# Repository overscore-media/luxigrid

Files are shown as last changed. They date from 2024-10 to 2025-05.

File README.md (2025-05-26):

# Luxigrid

Luxigrid is a WiFi-enabled LED matrix for your desk, compatible with an ecosystem of 25+ apps and counting.

The hardware and software are open-source, so you can build one yourself. Or buy one pre-assembled or as a kit from [our website](https://luxigrid.overscore.media)!

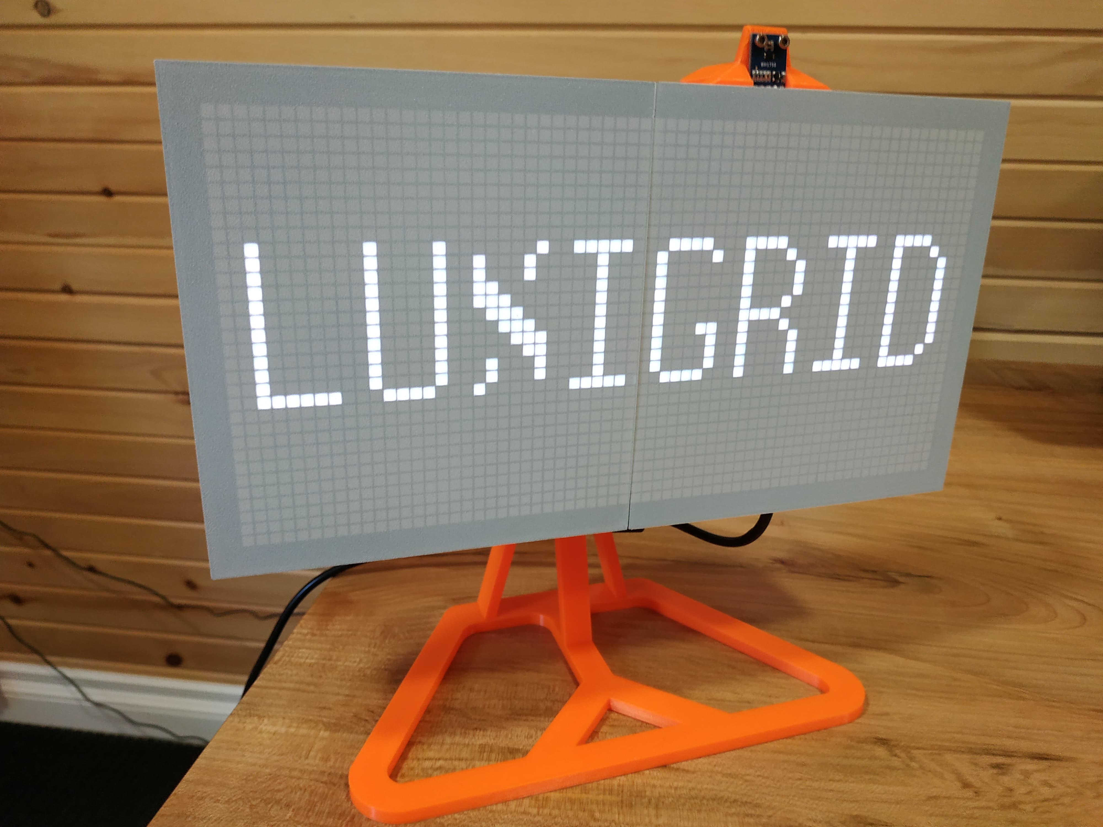
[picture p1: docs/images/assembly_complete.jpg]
An orange and white Luxigrid sitting on a wooden desk, displaying the Luxigrid logo on-screen


## Quick Specs

- 2048 RGB LEDs (in 64x32 grid)
- Browser-Based Web Interface
  - Configure important settings (WiFi, time/date, browse files on SD card, etc.)
  - Upload new apps over WiFi
  - Modify app-specific settings
- Can connect to the Internet (for stocks/weather/news/other info)
- Automatically adjusts its brightness (integrated light sensor)
- Temperature/Humidity Sensor (for an indoor weather station)
- Buzzer for playing alarms, alerts, and chiptunes
- Automatically adjusts for daylight savings time
- Keeps time even when the power goes out (real-time clock on-board)
- Made with readily-available components
- Open-Source
  - Build your own, or modify the code/hardware files to your heart's content
  - Code available under the MIT License
  - 3D printed parts available under the CC-BY-4.0 license
  - PCB Gerbers and KiCad project available and free to use as you see fit

## Quick Start Guide

If you're looking for help setting up your Luxigrid, we've assembled a Quick Start Guide with answers to your most common questions and troubleshooting help.

View the latest version of the [Quick Start Guide](./QUICK_START_GUIDE.md).

For technical support, you can also contact us on [our website](https://luxigrid.overscore.media). Please note that we only provide official support for products purchased from our website. But we'd be happy to chat with you, regardless of whether you've purchased a Luxigrid from our website, or built your own from scratch.

## Technical Details

- 64x32 LED matrix with 4mm pitch
  - Total of 2048 RGB LEDs
  - Compatible with HUB75 protocol
  - Readily available on sites like Aliexpress

- ESP32-DevKitC V4 board
  - ESP32-WROOM-32D processor module
  - WiFi (b/g/n 2.4 GHz) and Bluetooth 4.2
  - 240 MHz Clock Speed
  - 520 KB SRAM (16 KB cache) and 448 KB ROM
  - 1.75 MB of usable flash memory (with OTA updates enabled)
  - Readily available on many sites for under $10
  - Reference: <https://docs.espressif.com/projects/esp-idf/en/stable/esp32/hw-reference/esp32/get-started-devkitc.html>

- Custom PCB
  - Micro SD card reader
  - BME680 Environmental Sensor (temperature, humidity, air pressure)
  - BH1750 Light Sensor (for automatic screen brightness)
  - DS3231 Real-Time Clock (powered by a CR2032 coin cell battery)
  - Piezo Passive Buzzer
  - On/Off Rocker Switch
  - 2.5mm DC Barrel Jack for power

- Power Consumption: 5V DC - 3+ Amps at peak
  - *Please use a power supply capable of delivering at least 4A*

## Assembly Instructions

The process of assembling your own Luxigrid is fairly intensive, but should be documented well enough to be a fair challenge. If you're building one from scratch, you'll need to have purchased the parts from the Bill of Materials, have access to a 3D Printer, and be comfortable with soldering. It's not too difficult, as far as these sorts of electronics projects go, but it may not be for the faint of heart.

[View the full assembly instructions](./ASSEMBLY.md).

Alternatively, you can purchase a Luxigrid in kit form or pre-assembled from [our website](https://luxigrid.overscore.media).

## Development Instructions

The Luxigrid software is split into two semi-distinct components - the C++ firmware that resides on the ESP32, and the HTML/CSS/JavaScript-based web interface that runs on your browser. Since the ESP32 also acts as a web server, there is a level of integration involved. But the most complicated part of the software is its ability to support an arbitrary number of apps. Only one app can be installed on a Luxigrid at a time, and each app must be compiled separately (with its own firmware and web interface). But apps can be swapped between on the fly, thanks to the ESP32's Over-The-Air (OTA) update capability.

Needless to say, the underlying setup to make all of this work is pretty complex. And there are still potential areas for improvement. But we've done what we can to document the process.

[View the full development instructions](./DEVELOPING.md).

Alternatively, you can download the latest compiled versions of the available apps from the official [Luxigrid App Store](https://luxigrid.overscore.media/apps), or the [GitHub Releases page](https://github.com/overscore-media/luxigrid/releases).

## Found an Issue?

Let us know by [creating an Issue](https://github.com/overscore-media/luxigrid/issues) on this GitHub repository. Or if you have a bugfix, feature, or new application you'd like to share, feel free to open a [Pull Request](https://github.com/overscore-media/luxigrid/pulls). We also welcome GitHub stars, forks, and watchers.

For answers to specific questions, or if you just want to chat, drop us a line at [luxigrid.overscore.media](https://luxigrid.overscore.media).

## Credits

OverScore Media wishes to recognize the many giants whose shoulders this project stands upon. Thank you for your contributions to creativity and technology. We hope this project serves as an inspiration to others, like so many have been inspirations to us.

This includes the following individuals and teams. If we've missed any, please let us know. But be assured that their contributions have not gone unappreciated.

Where appropriate, additional copyright notices and software licenses have also been placed in the code. See also [licenses/credits.md](./licenses/credits.md).

### Software Libraries

- [ESP32 HUB75 LED Matrix Panel DMA Display](https://github.com/mrcodetastic/ESP32-HUB75-MatrixPanel-DMA) by @mrcodetastic on GitHub
- [Adafruit GFX Library](https://github.com/adafruit/Adafruit-GFX-Library)
- [Adafruit BusIO](https://github.com/adafruit/Adafruit_BusIO)
- [Adafruit Unified Sensor](https://github.com/adafruit/Adafruit_Sensor)
- [Adafruit BME680 Library](https://github.com/adafruit/Adafruit_BME680)
- [Adafruit RTClib](https://github.com/adafruit/RTClib)
- [BH1750](https://github.com/claws/BH1750) by @claws on GitHub
- [ESP Async WebServer](https://github.com/mathieucarbou/ESPAsyncWebServer) originally by [@me-no-dev](https://github.com/me-no-dev/ESPAsyncWebServer), then forked by [@yubox-node-org](https://github.com/yubox-node-org/ESPAsyncWebServer), then forked by [@mathieucarbou](https://github.com/mathieucarbou)
- [ArduinoJson](https://arduinojson.org/)
- [AnimatedGIF](https://github.com/bitbank2/AnimatedGIF) by @bitbank2
- [FastLED](https://github.com/FastLED/FastLED)

### Projects

The following projects have served as direct inspiration for parts of the Luxigrid firmware.

- [myClock](https://github.com/dragondaud/myClock) by @dragondaud on GitHub
- [Pong Wars for M5Stack](https://github.com/anoken/pong-wars-forM5Stack) by @anoken on GitHub
- [PONG clock](https://github.com/conejoninja/pongclock/) by @conejoninja on GitHub
- [Aurora](https://github.com/pixelmatix/aurora) by Jason Coon
- [minimalUploadAuthESP32](https://github.com/CelliesProjects/minimalUploadAuthESP32/blob/master/minimalUploadAuthESP32.ino) by @CelliesProjects on GitHub

### Development Tools

- [Arduino](https://www.arduino.cc/)
- [ESP32](https://www.espressif.com/en/products/socs/esp32)
- [PlatformIO](https://platformio.org/)
- [Visual Studio Code](https://code.visualstudio.com/)

### Web Development Tools

- [Tailwind.css](https://tailwindcss.com/)
- [Vite](https://vitejs.dev/)
- [JSDOM](https://github.com/jsdom/jsdom)
- [ESLint](https://eslint.org/)
- [ESLint Config XO](https://github.com/xojs/xo)
- [PostCSS](https://postcss.org/)
- [vite-plugin-html](https://github.com/vbenjs/vite-plugin-html)
- [vite-plugin-singlefile](https://github.com/richardtallent/vite-plugin-singlefile)
- [CSSNano](https://github.com/cssnano/cssnano)
- [Iconoir](https://iconoir.com/)

### Data Sources

- [Open-Meteo](https://open-meteo.com/) (for weather data)
- [Finnhub Stock API](https://finnhub.io/) (for stock data)
- [Wikipedia](https://www.wikipedia.org/) (for periodic table of elements data)
- <https://github.com/nayarsystems/posix_tz_db> (for timezone data)

### 3D Software

That's right. Luxigrid's 3D-printed parts were designed with free and open-source software!

- [FreeCAD](https://www.freecad.org/)
- [OpenSCAD](https://openscad.org/)
- [PrusaSlicer](https://www.prusa3d.com/page/prusaslicer_424/)

### 3D Models

This excellent 3D model was used as the basis for the desk mount. Our modified version is a bit taller, and uses an M4 bolt instead of an M5.

- [Vesa 75x75 monitor stand](https://www.thingiverse.com/thing:3808242) by @choosecool on Thingiverse
  - Licensed under the [Creative Commons - Attribution license](https://creativecommons.org/licenses/by/4.0/).

### Tutorials

These helpful tutorial creators have served as invaluable references during various parts of the concept, design, and production phases of this project. Thanks for sharing your knowledge!

- [Random Nerd Tutorials](https://randomnerdtutorials.com/) for a wealth of electronics tutorials
- [@Swiss_Cheese on YouTube](https://www.youtube.com/@Swiss_Cheese.) for PrusaSlicer tips and tricks
- [@ontherundesign's Hirth Joint](https://www.thingiverse.com/thing:2937436) FreeCAD Tutorial
- [RGB Panel Hookup Guide](https://learn.sparkfun.com/tutorials/rgb-panel-hookup-guide) by Sparkfun
- [Adafruit GFX Library Guide](https://cdn-learn.adafruit.com/downloads/pdf/adafruit-gfx-graphics-library.pdf) by Phillip Burgess

### Inspirations

These are some of the hardware projects and commercial products that have served as indirect inspirations for the development of Luxigrid. There were times when it seemed impractical to complete, but the existence of these projects gave us hope that it could be done. Hopefully this project can serve as such an inspiration to others. Your dreams may not be so unachievable, after all! :)

- [Tidbyt](https://tidbyt.com/)
- [Clockwise](https://clockwise.page/)
- [Adafruit Matrix Portal](https://www.adafruit.com/product/4745)
- [Pico RGB Matrix P3 64x32](https://www.waveshare.com/wiki/Pico-RGB-Matrix-P3-64x32) by Waveshare
- [Pixel Art Matrix Display](https://www.printables.com/model/600039-pixel-art-matrix-display) by @Till_312394 on Printables
- [Pixel Art with 64 LED Matrix WS2812B - v2](https://www.printables.com/model/946221-pixel-art-with-64-led-matrix-ws2812b-v2-new-led-di) by @Regis on Printables
- [ESP32 HUB75 LED Matrix Driver](https://github.com/rorosaurus/esp32-hub75-driver) by @rorosaurus on GitHub
- [ESP32 I2S Matrix Shield](https://www.tindie.com/products/brianlough/esp32-i2s-matrix-shield/) by Brian Lough
- [ESP32 D1 Mini D1 RGB Matrix Shield](https://github.com/hallard/WeMos-Matrix-Shield-DMA) by @hallard on GitHub
- [ESP Pixel Matrix](https://github.com/hanneslinder/esp-pixel-matrix) by @hanneslinder on GitHub
- [PxMatrix](https://github.com/2dom/PxMatrix) by @2dom on GitHub
- [HUB75 Pixel Art Display](https://github.com/mzashh/HUB75-Pixel-Art-Display) by @mzashh on GitHub
- [RGB Matrix Panel Shield for ESP32](https://www.tindie.com/products/lightwell/rgb-matrix-panel-shield-for-esp32/) by LIGHTWELL
- [ESP8266 RGB Matrix Cable Version](https://github.com/mike-rankin/ESP8266_RGB_Matrix_Cable_Version) by Mike Rankin

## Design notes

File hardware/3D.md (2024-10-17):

# Luxigrid - 3D Printed Parts List

The Luxigrid enclosure is fully 3D printable (with the exception of some fasteners and heated inserts - see the [Bill of Materials](./BOM.md) for more info).

Here is the list of files you'll need to print to make one of your own!

## List of Files

| Part Name | Optional? | Est. Print Time | Est. Filament Used (g) | Supports Required |
|---|---|---|---|---|
| Backplane Mesh Holder (x4) | * | 40 minutes | 12 | N |
| Desk Mount Bracket | N | 45 minutes | 13 | N |
| Desk Mount | N | 3 hours 30 minutes | 59 | N |
| Left Backplane | N | 4 hours 10 minutes | 82 | Y |
| Left Bracket | N | 1 hour 30 minutes  | 32 | Y |
| Left PCB Bracket | N | 50 minutes | 16 | Y |
| Matrix Diffuser - No Lip | * | 2 hours 20 minutes | 39*** | N |
| Matrix Diffuser - With Lip | * | 2 hours 20 minutes | 39*** | N |
| Right Backplane | N | 4 hours 10 minutes | 87 | Y |
| Right PCB Bracket | N | 40 minutes | 14 | Y |
| SD Card Hat | N | 5 minutes | 2 | N |
| **Totals** | | **21 hours** | **395 g** | |

*The backplane mesh holders are optional. Print them if you want to glue a mesh over the "windows" on the back of the enclosure.

**You need to print two diffusers. But you can choose to print a "No Lip" and a "With Lip" one, or two "No Lip" ones. The difference in material use is negligible, because the "With Lip" just has one extra 0.5mm line on the first layer. See notes below.

***You need at least black and white filament to print the diffusers. A minimum of **6g** of white, and **19g** of black filament is required per diffuser. The other 14g can be white, black, or whatever other colour you want.

## Slicing Tips

The recommended slicer to use with this project is [PrusaSlicer](https://www.prusa3d.com/page/prusaslicer_424/). It is compatible with Prusa printers, and many other models. Other slicers may work, but these files were designed with PrusaSlicer in mind. See the files in the `/hardware/3d/3MF` directory for PrusaSlicer projects.

Not all files are available in 3MF format, because not all of them have special requirements for supports, etc. The diffusers are probably the hardest parts of the enclosure to print, but it is doable.

If you plan to use a different slicer, you will need to ensure that supports are generated for the models requiring supports in the above. Just try not to go overboard with supports. Even if you're using a different slicer, it's recommended to open the 3MF's in PrusaSlicer first, to get a feel for which features need supports and which don't.

For the matrix diffusers, you will need one layer of white, followed by 10 layers of black, followed by any colour of your choice. This is assuming a **0.4mm nozzle** and **0.20mm** layer height, which is recommended for all parts.

The diffusers should *not have a brim on the edge where they connect*. This is to make it easier for them to fit together with as small a gap as possible. You may still need a brim on the other sides - see the 3MF files for an example.

In addition to the 3MF files for the trickier parts, we have also provided STL files for all parts, and STEP files for all but the matrix diffusers. Since they were designed in [OpenSCAD](https://openscad.org/), you also have access to the original .scad source file used to generate the matrix diffusers.

## Printing Tips

If you're using PrusaSlicer, especially with non-Prusa filament, you'll likely want to decrease the nozzle temperature considerably, to mitigate stringing. Especially for the black "grid" part of the matrix diffusers. We've had success at 190-195C for the black grid. But it depends on the specific filament you're using. Don't print too cold, or you may have other issues. But the default ~220C is generally too hot for printing the matrix diffuser grid. The other parts don't matter as much if they're stringy or not, but it really matters for the diffusers.

The diffusers must be printed with the same material throughout. So if you start with white PETG, you also need black (and whatever other optional colour) PETG to finish the diffuser. Same if you started with white PLA. Obviously you can print the rest of the enclosure with a different filament, but the colour difference may be noticeable, if you're using different types of filament for different parts of the enclosure.

We've had good results with either PLA or PETG, but other materials may work as well.

## Post-Processing Tips

If there are strings or small globs on your parts, very carefully removing them with a heat gun may be effective. This isn't really an option for the matrix diffusers or the vents/windows on the back of the enclosure, due to the thin plastic there being susceptible to warping if heat is applied.

Having some sandpaper and something like a "Metal Spudger" on hand may be useful for removing parts of brims, or other print artifacts. See the [BOM](./BOM.md) for more information on recommended tools.

For attaching the optional backplane mesh holders, hot glue is recommended. We recommend gluing the mesh to the holders first, then gluing the hole thing onto the backplane. Use the guide posts printed onto the inside of the backplanes to help align them. You may choose to install the mesh face-up or face-down. It can work either way. Although face-up is probably easier. See the [Assembly Instructions](../ASSEMBLY.md) for more information.

## Heated Insert Tips

The matrix diffusers and the right backplane both require metal heat-insert threads. You may choose to modify the source files to remove this requirement, but we highly recommend giving them a try.

These specific places, especially if you ever plan to take your Luxigrid apart, greatly benefit from not just having to screw into plastic. We experimented with placing them elsewhere, as there are still some places you'll have to screw into plastic. For instance, the PCB brackets have some plastic holes you'll have to screw into. But we couldn't get a reliable result that didn't involve the inserts falling out or detaching themselves from the plastic parts.

See the [BOM](./BOM.md) for details on the specific parts you'll need. There are many good tutorials out there for working with heated inserts. A special insert tip for a temperature-controlled soldering iron is recommended. We've tested several temperatures, and 490F or somewhere thereabouts seems ideal. You may want to have some practice before you attempt this. It's not too bad once you get the hang of it. But always be careful around soldering irons and high heat. And give the parts sufficient time to cool before continuing with the rest of the assembly.

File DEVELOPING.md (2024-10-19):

# Luxigrid - Development Documentation

## Project Setup

This repository contains two semi-distinct sub-projects - the C++ firmware for the ESP32, and the browser-based web interface code.

Briefly, the web interface lives in the `/ui` folder, and the C++ project is spread across the `/apps`, `/lib`, and `/src` directories.

The firmware is compiled using the PlatformIO toolchain. The `platformio.ini` file contains the build configuration, including the list of external C++ dependencies.

The `/scripts` directory contains a few Python and shell scripts that help with automating builds of the software.

Working with this code requires a decent amount of experience with C++ and JavaScript. Experience with embedded development is also a plus. It's not the fanciest or best code by any means, but it's more than serviceable.

## Initial Setup

You will need Node.js (at least version 18.20.2) and npm installed on your system. See <https://nodejs.org/en/download> for instructions.

You will also need PlatformIO to be installed on your system, ideally through its VS Code extension, and a compatible version of Python 3. Not as tricky as it might seem - see <https://randomnerdtutorials.com/vs-code-platformio-ide-esp32-esp8266-arduino/> or <https://docs.platformio.org/en/latest/integration/ide/vscode.html> for help.

You might also want to install `curl` if you don't already have it on your system (if you want to use the OTA Upload capability from PlatformIO).

First things first, clone or download this Git repository. Once you have it somewhere on your system, run `npm install` in the `/ui` directory.

Then, you should copy the `.env.example` file and rename the copy to `.env`. Do the same for the `/ui/.env.example` file.

Finally, from the PlatformIO sidebar in VS Code, you should be able to see the `Build` button under the `esp32dev` device folder.

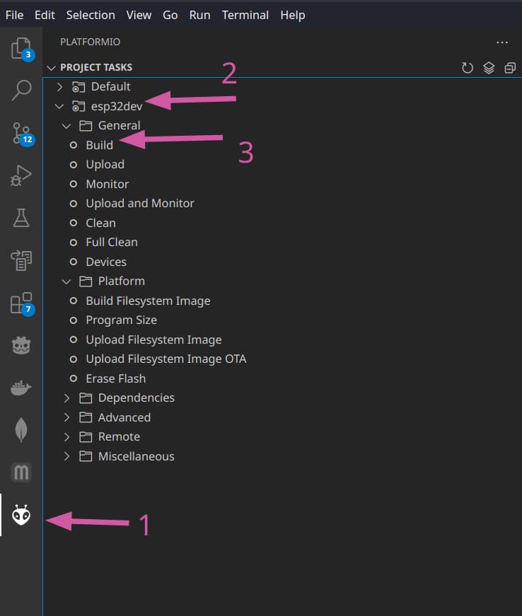
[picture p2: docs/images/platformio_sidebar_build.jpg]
From the PlatformIO sidebar, click "Build" under "esp32dev"


A terminal window should open in VS Code, and the result should look something like this.

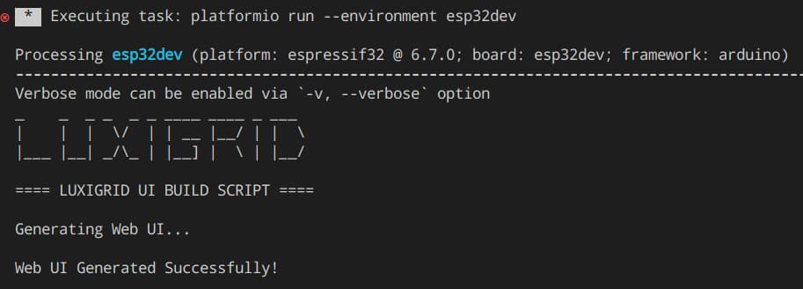
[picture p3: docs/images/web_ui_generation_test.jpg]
A terminal displays Web UI Generated Successfully!


You will probably have some errors below this, but as long as it says "Web UI Generated Successfully!" you should be good to move on.

## Setting the Current App

Each time you build the Luxigrid firmware, you need to specify which app you have selected. The reasoning for this is quite simple. With the ESP32's limited resources (especially flash memory) it is not possible to have all of these apps installed at the same time. Further, many of the apps have mutually-exclusive functionality that would conflict.

In order to set the current app, you must uncomment one of the app names in `lib/apps.h`. To enable the Pong Clock, for instance, you would uncomment `#define PONG_CLOCK` like so:

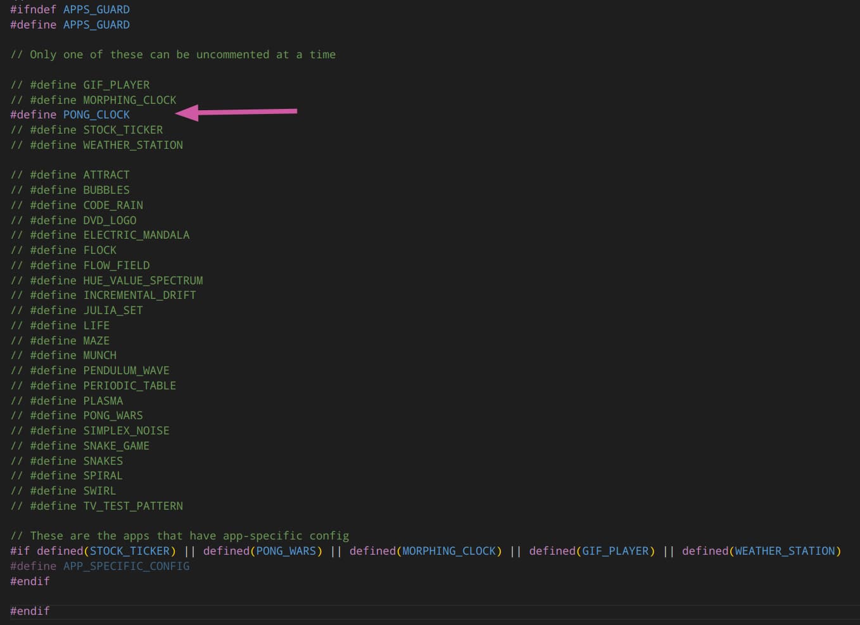
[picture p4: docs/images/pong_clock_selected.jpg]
The line with PONG_CLOCK is uncommented, while the other app names are still commented out


Unfortunately there's also a bit of frontend configuration to be done.

In the `/ui/.env` file, you'll need to at set at least the `VITE_APP_NAME`. In this case, `VITE_APP_NAME=Pong Clock` would be appropriate. For apps with app-specific config (see the list in `/lib/apps.h`) you'll also need to provide a `VITE_CURRENT_APP`. But for now you can leave it commented out. The other environment variables aren't that big of a deal right now. You could leave them as-is or comment them out.

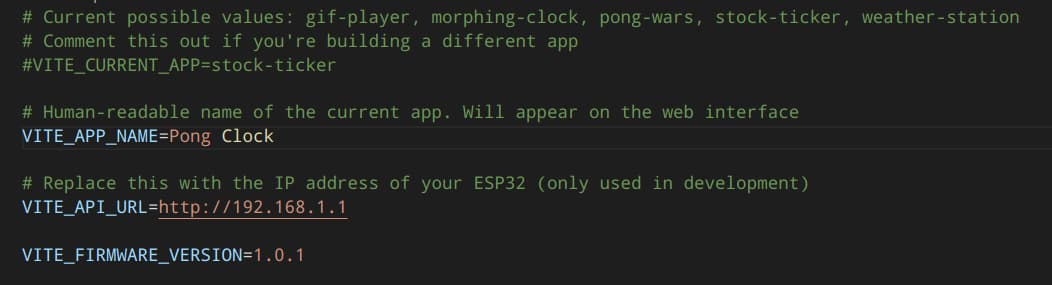
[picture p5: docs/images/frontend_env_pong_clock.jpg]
/ui/.env file with VITE_APP_NAME=Pong Clock and VITE_CURRENT_APP commented out


Then that should be all you need. Try building the app from the PlatformIO sidebar "Build" button. You should get something that looks a bit like this. Note the "Web UI Generated Successfully!" at the top, and the "Successfully created esp32 image." at the bottom. If you see any yellow or red text, something may have gone wrong.

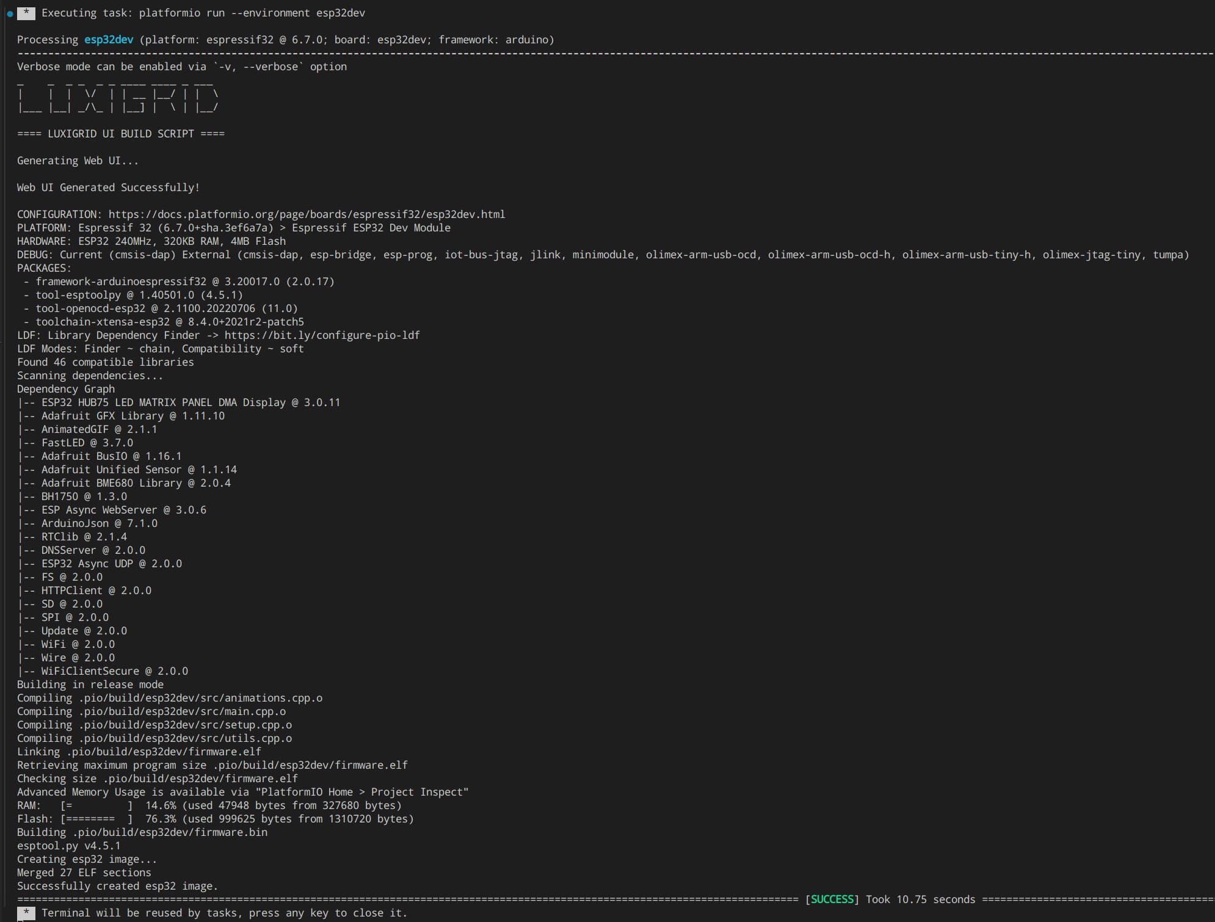
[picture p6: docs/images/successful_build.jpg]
A successful build of the Luxigrid firmware, that says "Successfully created esp32 image." at the bottom


So why are they all in the same project? Good question. While there are some obvious benefits to a more encapsulated approach, where each app has its own project, that would lead to a lot of unnecessary code duplication and even more complexity. It's just not worth it, when all of the apps share a significant portion of the codebase. Separating the shared code into a separate library might have made sense, but the existence of the web interface throws a bit of a wrench into that plan.

Ultimately, there may be better ways of structuring a project like this, but this works pretty well, given the constraints. Is it perfect? Does it eliminate code duplication? Does it make it the easiest to create new apps? No, not really. But it works.

## Deploying to the ESP32

### OTA Upload via PlatformIO

Once you've successfully built the Luxigrid firmware, you have a few options for deploying it to the ESP32. One option, provided by this project, is to use the "Upload" button on the PlatformIO sidebar (just under "Build").

If your ESP32 is already running, and already has an IP address on your WiFi network, you can set it as your `ESP32_IP` in the `.env` file. Then as long as it's accessible, and you have `curl` installed on your system, it should automatically upload the new firmware image to the ESP32, replacing the existing firmware. Once the ESP32 reboots, it should be running the new firmware (unless something went wrong, which the terminal might give you some insight on).

### Upload via the Luxigrid Web Interface

Alternatively, the `/.pio/build/esp32dev/firmware.bin` file is what you're looking for. If you have a Luxigrid that's currently running, you can upload that firmware image via the Luxigrid web interface from your browser. Same deal, it should reboot after uploading and installing the new firmware.

### Upload via USB

Otherwise, you'll have to find a way to upload onto the ESP32 via USB. You can comment out the `upload_protocol`, `upload_command`, and `pre:scripts/upload_firmware.py` lines in `platformio.ini`. Something like this (comment lines out by putting a `;` in front of them.)

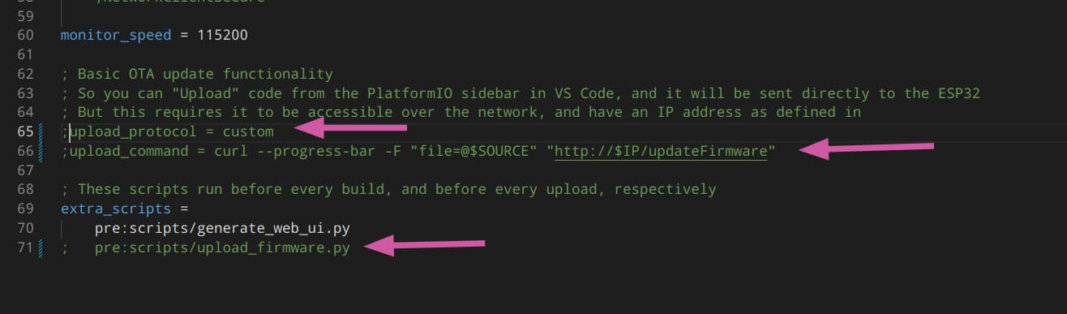
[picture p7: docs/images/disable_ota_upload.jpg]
Three lines near the end of the platformio.ini file are commented out with semicolons


Then plug your ESP32 into your computer via its Micro USB port.

It's not recommended to have the ESP32 plugged into the Luxigrid circuit board while uploading firmware. It might work, but it's at your own risk. Ideally you should have just the ESP32 board itself plugged in via USB.

You may need to mess with drivers or various things to get the ESP32 code upload to work over USB. Luckily, PlatformIO is pretty good at finding it, and it's pretty configurable if you're having issues. This tutorial from Random Nerd Tutorials should be very helpful if you're running into issues <https://randomnerdtutorials.com/vs-code-platformio-ide-esp32-esp8266-arduino/>.

You'll know when it works, when you can plug the ESP32 into the Luxigrid circuit board (provided it's properly installed in the LED matrix), provide power to the circuit board, and watch the Luxigrid logo pop up.

## Creating a New App

### Basic Requirements

The process of creating a new app is quite involved. Especially if it will have app-specific config. Hopefully the available apps can serve as decent examples should you choose to embark on this journey.

The first thing to note, is you should have a main source file for your app, in the `/apps` (or `/apps/animations`) folder. You'll need to think up a unique name for it, that doesn't conflict with existing app names. Your main source file should have an `.hpp` extension.

You should put a define guide at the top, something like:

```cpp
#ifndef STOCK_TICKER_GUARD
#define STOCK_TICKER_GUARD
```

But make it unique, like `MY_APP_NAME_GUARD`. Also don't forget to put a `#endif` at the end of the file. You will also need to import the Arduino and Luxigrid headers, at the very least.

```cpp
#include "Arduino.h"
#include "../lib/luxigrid.h"
```

You can import other dependencies at the top of your source file. They can be local files, or external dependencies installed by PlatformIO. It's up to you.

All apps need at least a `setup()` and a `loop()` function.

```cpp
void setup() {
    setupMatrix();
}

void loop() {

}
```

The `setup()` function should call `setupMatrix()` at the top, or you won't have access to the rest of the shared features of the Luxigrid firmware.

### App-Specific Config (Optional)

Apps that have app-specific config also need at least the following functions:

```cpp
void retrieveAppConfig() {}
void validateAppConfig() {}
void saveAppConfig() {}
```

There are several examples of apps with app-specific config, some more complicated than others. The config in `/apps/animations/pong-wars.hpp` is two colours, whereas the config in `/apps/stock-ticker.hpp` is much more involved.

Without going into too much detail, or we'd be here all day, each app with app-specific config needs to provide the means to load the config (from a JSON file on the SD card), a function to provide the config to the web interface, a function to provide a function to validate user-provided config from the web interface, and a function to save the config to the SD card.

The ArduinoJson library makes it convenient to store configuration as a JSON file. And various custom `struct`'s can be used to define the types of configuration that will be used in the app.

The app-specific config must be loaded in the `setup()` function, after which the global variable `configIsLoaded` should be set to true. Otherwise, it's up to you what happens in-between. See `/lib/web_server.hpp` for an idea of what the rest of the codebase expects.

### Other Required Setup

You'll also need to update `/lib/apps.h` and add your new app to the list. Add a new line under the APPS_GUARD that looks something like: `#define MY_NEW_APP`. For apps with app-specific-config, you'll need to add your app to the list of apps that have it. The goal is so `APP_SPECIFIC_CONFIG` will be defined only if it needs to be.

You'll also need to modify `/src/main.cpp` so your app's main source file is imported. That might look something like this, but your mileage may vary:

```cpp
#ifdef MY_APP
#include "../apps/my-app.hpp"
#endif
```

Finally, you might want to update `/scripts/build_all_apps.py` to include your new app. That is, if you want it to be built along with the other apps when bulk-compiling them.

### Required Web Interface Setup

Unfortunately this is only half the story (if app-specific config is involved). You'll still need to create a custom section on the web interface to enable users to interact with the app-specific config.

Without app-specific config, you can just set `VITE_APP_NAME` in `/ui/.env` to whatever you want to call your app. And keep `VITE_CURRENT_APP` commented out. You could then set a custom `VITE_FIRMWARE_VERSION`, it's up to you.

### Additional Web Interface Setup (App-Specific Config only)

If your app has its own config, you'll need to provide some frontend code to go along with it. This starts by creating a folder in the `/ui/apps` directory, with the name of your app. If you app is called "My App", for instance, `/ui/apps/my-app` would be a good choice. You will need to provide the name of this folder (in this case `my-app`) as the `VITE_CURRENT_APP` in the `/ui/.env` file.

Inside this folder, you'll need at least a JavaScript file, named something like `/ui/apps/my-app/my-app.js` (same filename as `VITE_CURRENT_APP` but with a `.js` extension).

This JS file must export a function by default. It can be called whatever you want.

This function must setup the app's icon (Finding icons from <https://iconoir.com/> and running them through <https://jakearchibald.github.io/svgomg/> works well), the app's name, the name of the button on the web interface, what settings inputs are available, and how they're interacted with.

In lieu of a step-by-step guide, see `/ui/apps/pong-wars/pong-wars.js` for a fairly minimal example. You can choose to construct the interface using just JavaScript, or you can provide a `.hbs` file and import it into your `.js` file. It must be `.hbs`, even if it's not actually Handlebars, because a custom optimizer (configured in `/ui/vite.config.js`) runs on `.hbs` files.

Like with the C++ side of app-specific config, other than that, it's up to you how you choose to implement the various parts of the web interface. Ideally, you should be able to work with what you have, and not have to pull in external JavaScript dependencies. Because in an embedded environment, they can really add up.

## Tips, Tricks, and Caveats

Admittedly, the process of creating a new app could be easier or better documented. But for the time being, at least unless there is enough interest in streamlining this process, development will be focused on fixing bugs, adding little features here and there, and adding new apps from time to time.

It would be nice to have the ability to create builds of the firmware with features like the Light Sensor, BME680 environmental sensor, RTC, etc. disabled in the code - for people who built a Luxigrid without one or more of them. Currently that's not officially supported (although the light sensor can be disabled from the web interface) but it would be nice.

Double buffering is supported by the ESP32-HUB75-MatrixPanel-DMA library, but the shared codebase isn't drop-in compatible with it. Although for most apps, it shouldn't be necessary in the first place.

If you're experiencing flickering with a custom app, avoid `dma_display->clearScreen()` wherever possible. For one reason or another, flickering seems far less noticeable if you're just updating one part of the screen at a time. Like drawing a black rectangle before updating the text above it.

Technically more fonts are supported, although only two are currently used in the app (`Org_01` is a blocky font, `TomThumb` is a tiny font). But the Adafruit GFX library is compatible with (and includes) many fonts. Worth looking into, if you're interested in a different look.

There are some pretty advanced latent capabilities of this system. An alarm clock comes to mind, or perhaps a Spotify "Now Playing" display. Rest assurred, we at OverScore Media have some ideas in the works. But if you have any ideas of you own, you might be surprised what's possible.

The hardest part about building internet-connected apps is finding a reliable data source. Finnhub and Open-Meteo are great; really appreciate that they're free for personal use. But a lot of interesting project ideas are hampered by bad, non-existent, obsolete, or expensive APIs.

There might be a way to run clock faces from the Clockwise project on a Luxigrid. There may also be potential HomeAssistant or ESPHome integrations.

It'd be interesting to apply this approach to larger or smaller LED matrixes. The Luxigrid PCB technically has "HUB75 (E)" compatibility, for larger matrixes like 64x64. Although the firmware currently expects a 64x32 matrix in most places. There are also matrixes with larger or smaller LEDs. Going any larger than 4mm would push the PCB to (and perhaps beyond) its limits, since it would require more power to operate. Especially the barrel jack, which is rated at 5A. Although a smaller 3mm matrix version should be doable. The hardware would probably work just fine, it would just require new 3D files. Anyway. Maybe one of these days...

But from a software point of view, you'd probably be surprised just how many similar code projects are out there. Search "HUB75" followed by whatever search term. Some work with a Raspberry Pi, and may require resources that the ESP32 can't provide. Many may be compatible with some tweaks, though. And even if they're written in a different programming language, or even if they use an LCD/OLED instead of a HUB75 LED matrix, you'd probably be surprised how straightforward they may be to port to this framework.

Case in point, the Pong Clock app is pretty much a port of <https://github.com/conejoninja/pongclock/>, although the original was written in Go. And Pong Wars was adapted from <https://github.com/anoken/pong-wars-forM5Stack>. The original was written for a modified ESP32 connected to a square LCD display.

Bottom line, as early and complex as it may be - the Luxigrid firmware has been designed with modularity in mind from the start. It abstracts away as much of the repetitive stuff as reasonable, letting you interact with the display and perhipherals in a pretty fluent way. The powerful [ESP32-HUB75-MatrixPanel-DMA](https://github.com/mrcodetastic/ESP32-HUB75-MatrixPanel-DMA) library by @mrcodetastic does a lot of the heavy lifting on the LED side of things, and libraries like [ArduinoJson](https://github.com/bblanchon/ArduinoJson) and [ESPAsyncWebServer](https://github.com/mathieucarbou/ESPAsyncWebServer) make custom web-based configuration fairly straightforward to setup.

## Folder Structure

Here's the complete folder structure of this project, including some descriptions of relevant files. Most source code files also have some kind of comment(s) inside the files themselves, explaining their purpose, etc.

- `/.pio` (auto-generated by PlatformIO; do not source-control)

- `/.vscode` (contains some optional settings to make code editing easier with Visual Studio Code)

- `/apps` (the individual applications live here)
  - `/apps/animations` (for apps that don't rely on external resources or time-keeping)

- `/docs`
  - `/docs/images` (where images are stored for this documentation)

- `/hardware`
  - `/hardware/3d/` (3D Printing files)
    - `/hardware/3d/3MF` (3MF files generated from Prusa Slicer. Use as a reference for the trickier-to-print parts.)
    - `/hardware/3d/SCAD` (OpenSCAD source files. Currently just for the matrix diffusers)
    - `/hardware/3d/STEP` (STEP 3D files. Useful for importing into a 3D slicer or CAD program)
    - `/hardware/3d/STL` (STL files. Useful for importing into some 3D slicers. STEPs are recommended whenever your slicer supports them, but the matrix diffuser is only available in SCAD and STL)
  - `/hardware/pcb`
    - `/hardware/pcb/kicad` (the KiCad project used to create the PCB)
    - `/hardware/pcb/gerbers` (pre-generated Gerber files for PCB manufacturing)
  - `/hardware/3D.md` (3D printing instructions)
  - `/hardware/BOM.md` (Bill of Materials)
  - `/hardware/luxigrid_shopping_list.xlsx` (Spreadsheet for helping with buying parts for building a Luxigrid from scratch)

- `/lib` (various helper/library files, for apps or Luxigrid itself) - all apps use at least these files:
  - `/lib/apps.h`
    - Where the list of apps is defined, and the current app is selected
    - Uncomment out one of the apps at a time, so the compiler will know which one to build
    - Also defines whether the current app has app-specific config (from the web interface)
  - `/lib/luxigrid.h`
    - The main project header. Imports dependencies used in every app, and declares global variables/structs and shared functions
  - `/lib/web_server.hpp`
    - Where the web server code lives. With the exception of app-specific config handlers (defined in app code where applicable)
    - Includes routes for SD card file management, WiFi configuration, time and other global configuration, OTA firmware updates, and a health check route to see if the device is online and fully loaded
  - `/lib/web_ui.h`
    - Auto-generated by `scripts/generate_web_ui.py`; do not source-control
    - Contains a binary array of gzipped data, representing the web interface
    - Is used by the web server to display the web interface
    - When compiling with PlatformIO, the web interface is automatically rebuilt prior to each code compliation

- `/licenses` (licenses and credits for third-party code/libraries used in this project)

- `/scripts` (automation helpers)
  - `/scripts/build_all_apps.py` (used to compile all apps automatically, and generate a .ZIP of them)
  - `/scripts/build_ui.sh` (bash script used in conjunction with `generate_web_ui.py`)
  - `/scripts/generate_elements.py` (used to generate the list of elements for the periodic table app - kept here for future reference)
  - `/scripts/generate_web_ui.py` (ensures the web interface code is up to date before the rest of the C++ code is compiled)
  - `/scripts/upload_firmware.py` (enables automatic OTA firmware uploads from PlatformIO)

- `/src` (main C++ source directory)
  - `/src/animations.cpp` (some animations and user interface elements, like the startup logo and WiFi information splash page)
  - `/src/main.cpp` (basically just `#include`'s for the available apps, based on the current app as set in `/lib/apps.h`)
  - `/src/setup.cpp` (initial setup functions, for the LED matrix, WiFi, time and date, the onboard sensors, and the SD card)
  - `/src/utils.cpp` (various shared utilty functions)

- `/ui` (where the web interface code lives)
  - `/ui/apps` (contains subfolders for the apps with app-specific config)
    - Must have a `.js` file, but may also have other files (like `.hbs` or `.css`)
    - Each app with config must have a folder with its name, and a matching `.js` file inside
    - So `gif-player` has `/ui/apps/gif-player` which houses `gif-player.js`
    - And `pong-wars` has `/ui/apps/ponig-wars` which houses `pong-wars.js`
  - `/ui/dist` (automatically-generated build files; do not source-control)
  - `/ui/lib` (various shared JavaScript utility functions)
  - `/ui/node_modules` (Node.js dependencies; do not source-control)
  - `/ui/templates` (some reusable HTML templates)
    - They're `.hbs` extension, and they have `{{}}` interpolation going on, but it's not actually Handlebars
    - It's just easier to think of them as Handlebars files
  - `/ui/.env.example` (copy and rename this to `/ui/.env`)
    - Set `VITE_CURRENT_APP` for apps with app-specific config (like `stock-ticker`, `gif-player`, etc.) or uncomment for apps without app-specific config
    - Set `VITE_APP_NAME` to a human-readable name of the current app (like `Stock Ticker` or `GIF Player`)
    - Set `VITE_API_URL` to the accessible URL of your ESP32 (during development only)
    - Set `VITE_FIRMWARE_VERSION` to whatever version string you want to display on the web interface (optional)
  - `/ui/.eslintrc.cjs` (ESLint configuration for linting/analyzing JavaScript code)
  - `/ui/.gitignore` (List of files that won't be source-controlled in the `/ui` directory by default)
  - `/ui/.prettierrc` (Prettier configuration for linting HTML)
  - `/ui/generateWebUI.js` (Script that generates `/lib/web_ui.h`)
  - `/ui/index.html` (Main HTML file for the web interface)
  - `/ui/main.js` (Main JavaScript file for the web interface)
  - `/ui/package-lock.json` (Node.js dependencies list - do not edit)
  - `/ui/package.json` (High-level, Node.js dependencies list, for use with `npm`)
  - `/ui/postcss.config.js` (PostCSS configuration)
  - `/ui/style.css` (Global CSS file for the web interface)
  - `/ui/tailwind.config.js` (Configuration for Tailwind.css)
  - `/ui/timezones.json` (JSON data of timezones - adapted from <https://github.com/nayarsystems/posix_tz_db>)
  - `/ui/vite.config.js` (Custom Vite configuration)

- `.clang-format` (settings for auto-formatting C++ code, to keep it stylistically consistent)

- `.env.example` (copy and rename this to `.env`)
  - You can set `ESP32_IP` if you want to OTA upload to the ESP32 directly from PlatformIO

- `.gitignore` (list of files that won't be source-controlled by default)

- `ASSEMBLY.md` (Assembly Instructions)

- `DEVELOPING.md` (this file - Development Instructions)

- `LICENSE.txt` (the main license of this repository)

- `platformio.ini` (contains the build configuration and C++ dependencies)

- `QUICK_START_GUIDE.md` (Quick Start Guide)

- `README.md` (take a guess 😉)

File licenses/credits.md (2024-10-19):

# Credits

- License Files:
  - **MIT License** (licenses/MIT_LICENSE.txt)
  - **Apache 2.0 License** (licenses/APACHE_LICENSE.txt)
  - **GNU Lesser General Puglic License v3.0** (licenses/LGPL3_LICENSE.txt)
  - **BSD License** (licenses/BSD_LICENSE.txt)
  - **CC-BY 4.0 License** (licenses/CC_BY_LICENSE.txt)
  - **CC0 1.0 License** (licenses/CC0_LICENSE.txt)

## Credits for Luxigrid Software

---

- Adafruit BME680 Library
  - <https://github.com/adafruit/Adafruit_BME680>
  - <https://adafruit.github.io/Adafruit_BME680/html/index.html>
  - Written by Limor Fried/Ladyada for Adafruit Industries
  - BSD License

---

- Adafruit Bus IO Library
  - <https://github.com/adafruit/Adafruit_BusIO>
  - Copyright (c) 2017 Adafruit Industries
  - MIT License

---

- Adafruit GFX Library
  - <https://github.com/adafruit/Adafruit-GFX-Library>
  - Copyright (c) 2012 Adafruit Industries.  All rights reserved.
  - BSD License

---

- Adafruit RTClib
  - <https://github.com/adafruit/RTClib>
  - "a fork of JeeLab's fantastic real time clock library for Arduino"
  - Copyright (c) 2019 Adafruit Industries
  - MIT License

---

- Adafruit Unifed Sensor Driver
  - <https://github.com/adafruit/Adafruit_Sensor>
  - Apache 2.0 License

---

- AnimatedGIF
  - <https://github.com/bitbank2/AnimatedGIF>
  - Copyright (c) 2020-2024 BitBank Software, Inc.
  - Written by Larry Bank (<larry@bitbanksoftware.com>)
  - Apache 2.0 License

---

- ArduinoJson
  - <https://arduinojson.org/>
  - <https://github.com/bblanchon/ArduinoJson>
  - Copyright © 2014-2024, Benoit BLANCHON
  - MIT License

---

- BH1750
  - <https://github.com/claws/BH1750>
  - Copyright (c) 2018 claws
  - MIT License

---

- cssnano
  - <https://github.com/cssnano/cssnano>
  - <https://cssnano.github.io/cssnano/>
  - Copyright (c) Ben Briggs <beneb.info@gmail.com> (<http://beneb.info>)
  - MIT License

---

- ESLint
  - <https://github.com/eslint/eslint>
  - <https://eslint.org/>
  - Copyright OpenJS Foundation and other contributors, <www.openjsf.org>
  - MIT License

---

- ESLint Config XO
  - <https://github.com/xojs/xo>
  - Copyright (c) Sindre Sorhus <sindresorhus@gmail.com> (<https://sindresorhus.com>)
  - MIT License

---

- ESP32-HUB75-MatrixPanel-DMA
  - <https://github.com/mrcodetastic/ESP32-HUB75-MatrixPanel-DMA>
  - Copyright (c) 2018-2032 Faptastic
  - MIT License

---

- ESPAsyncWebServer
  - <https://github.com/mathieucarbou/ESPAsyncWebServer>
  - Originally by [@me-no-dev](https://github.com/me-no-dev/ESPAsyncWebServer)
  - Then forked by [@yubox-node-org](https://github.com/yubox-node-org/ESPAsyncWebServer)
  - Then forked by [@mathieucarbou](https://github.com/mathieucarbou)
  - LGPL-3.0 License

---

- Espressif 32 for PlatformIO
  - <https://github.com/platformio/platform-espressif32>
  - Apache 2.0 License

---

- FastLED
  - <https://github.com/FastLED/FastLED>
  - <https://fastled.io/>
  - Originally created by Daniel Garcia in 2010 ([@focalintent](https://github.com/focalintent) on GitHub) - RIP
  - Mark Kriegsman ([@kriegsman](https://github.com/kriegsman)) on GitHub) - joined the project in 2013
  - Copyright (c) 2013 FastLED
  - MIT License

---

- Iconoir
  - <https://iconoir.com/>
  - <https://github.com/iconoir-icons/iconoir>
  - Copyright (c) 2021 Luca Burgio
  - MIT License

---

- JSDOM
  - <https://github.com/jsdom/jsdom>
  - Copyright (c) 2010 Elijah Insua
  - MIT License

---

- minimalUploadAuthESP32
  - <https://github.com/CelliesProjects/minimalUploadAuthESP32>
  - Copyright (c) 2022 Cellie
  - MIT License

---

- posix_tz_db
  - <https://github.com/nayarsystems/posix_tz_db>
  - Copyright (c) Nayar Systems
  - MIT License

---

- PostCSS
  - <https://github.com/postcss/postcss>
  - <https://postcss.org/>
  - Copyright 2013 Andrey Sitnik <andrey@sitnik.ru>
  - MIT License

---

- Tailwind CSS
  - <https://github.com/tailwindlabs/tailwindcss>
  - <https://tailwindcss.com/>
  - Copyright (c) Tailwind Labs, Inc.
  - MIT License

---

- Vite
  - <https://github.com/vitejs/vite>
  - <https://vitejs.dev/>
  - Copyright (c) 2019-present, Yuxi (Evan) You and Vite contributors
  - MIT License

---

- vite-plugin-html
  - <https://github.com/vbenjs/vite-plugin-html>
  - Copyright (c) 2020-present, Vben
  - MIT License

---

- vite-plugin-singlefile
  - <https://github.com/richardtallent/vite-plugin-singlefile>
  - Copyright (c) 2021-present, Richard S. Tallent, II
  - MIT License

---

## Image Credits for [luxigrid.overscore.media](https://luxigrid.overscore.media)

- 32x32 Pixel Art Creatures
  - <https://opengameart.org/content/assorted-32x32-creatures>
  - <https://opengameart.org/content/more-assorted-32x32-creatures>
  - <https://opengameart.org/content/32x32-pixel-art-creatures-volume-3>
  - Posted by AndHeGames on OpenGameArt
  - CC0 License

- 32x32 Portraits
  - <https://opengameart.org/content/32-x-32-portraits>
  - Posted by Seafood5040 on OpenGameArt
  - CC0 License

- CC0 Food Icons
  - <https://opengameart.org/content/cc0-food-icons>
  - Posted by AntumDesign on OpenGameArt
  - CC0 License

- CC0 Tool Icons
  - <https://opengameart.org/content/cc0-tool-icons>
  - Posted by AntumDeluge on OpenGameArt
  - CC0 License

- Hand Cursor
  - <https://opengameart.org/content/hand-cursor>
  - Posted by andreyin on OpenGameArt
  - CC0 License

- Hearts [32x32] & [16x16]
  - <https://opengameart.org/content/hearts-32x32-16x16>
  - Posted by Leozlk on OpenGameArt
  - CC0 License

- GitHub Icon
  - <https://iconduck.com/icons/313558/github>
  - Jérémie Pichon
  - MIT License

- Winter Birds
  - <https://opengameart.org/content/winter-birds>
  - Posted by Refuzzle on OpenGameArt
  - CC0 License

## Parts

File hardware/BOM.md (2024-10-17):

# Luxigrid - Bill of Materials

This is the list of the parts/tools you may need to assemble a Luxigrid of your own. Fair warning, it's a fairly long list. But we've gone to considerable lengths to ensure the availability/reasonable price of these components. Hopefully they're still relatively easy to find, if and when you choose to embark on this adventure.

You can also purchase a Luxigrid in kit form or pre-assembled from [our website](https://luxigrid.overscore.media) 😉.

**Please Note:** OverScore Media does not guarantee that any of this information is accurate or up-to-date. It is provided for informational purposes only, in the hope that it will be useful. Any images are for illustration only. If you choose to follow these instructions, you do so at your own risk. This is just to let you know what you might be in for. Please be careful.

We've also provided a handy [Shopping List](./luxigrid_shopping_list.xlsx) spreadsheet that you may find helpful.

## Modules

- **LED Matrix**
  - P4 64x32 LED Matrix
  - 256x128mm
  - HUB75
  - Your mileage may vary, but Muen LED/MuenShop on Aliexpress has good deals
  - *Must be compatible with the ESP32 HUB75 MatrixPanel DMA Library* - see <https://github.com/mrcodetastic/ESP32-HUB75-MatrixPanel-DMA?tab=readme-ov-file#supported-panels>

- **ESP32-DevKitC V4 Board**
  - You're looking for a **38-pin** ESP32 board that has an **ESP32-WROOM-32D** chip and **Micro USB**
  - Look for the one that matches this picture *exactly*, since the Luxigrid PCB is built around it
  - They shouldn't be too hard to find, if you know what you're looking for - i.e., this:

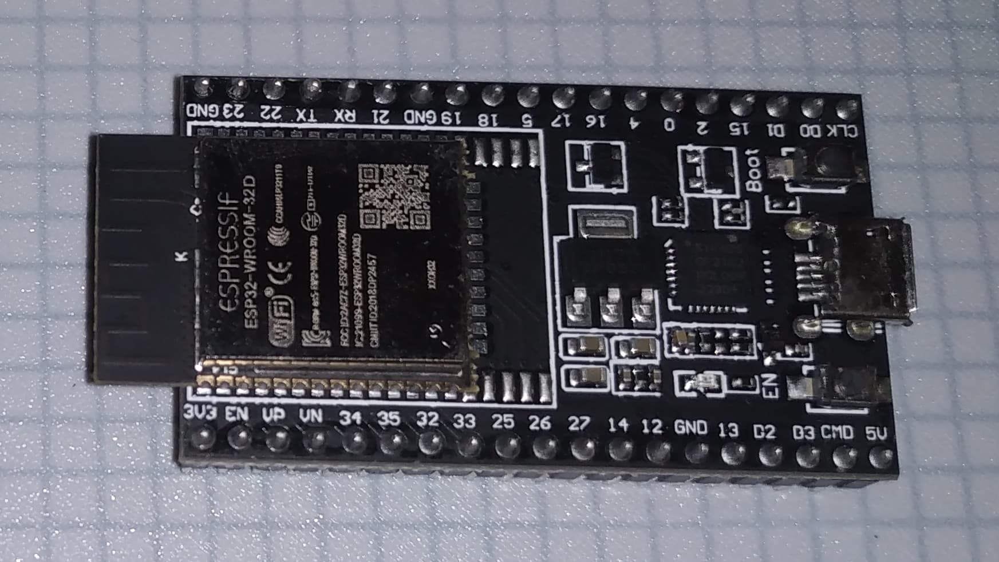
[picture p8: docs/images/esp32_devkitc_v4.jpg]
38-pin Microcontroller board powered by ESP32-WROOM-32D chip


- **DS3231 RTC Module**
  - These RTC modules are fairly easy to find
  - Some come with a battery included, but you're probably better off finding a battery elsewhere (more on that below)
  - Note: To install it on the Luxigrid PCB, you'll need to solder 4 male header pins facing downwards (as shown in the picture)
  - Many modules come with 4 extra male header pins for this purpose
  - Also, don't mind the subpar soldering job on this and other parts. These were from an early test - we've had more practice since then.

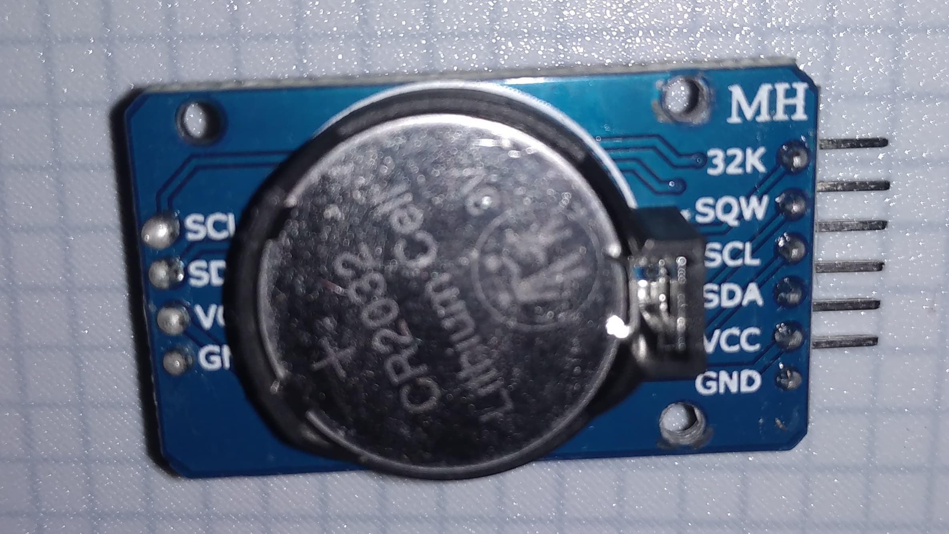
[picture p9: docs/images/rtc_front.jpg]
Front of RTC Module, with CR2032 Battery, 4 pins on left side, and 6 pins on right side

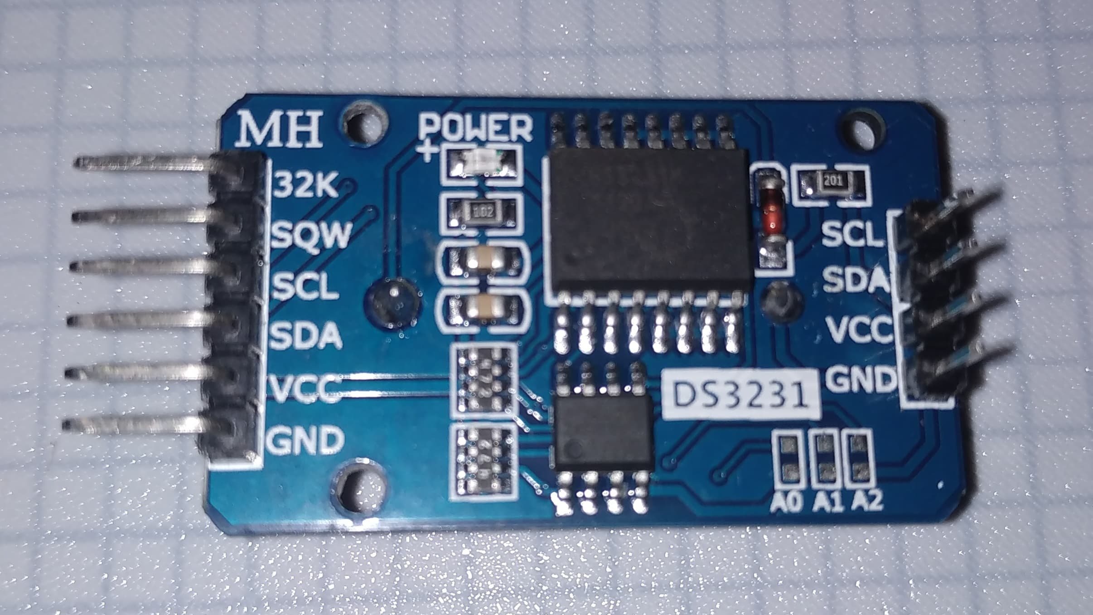
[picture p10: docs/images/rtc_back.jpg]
Backside of RTC Module, 6 pins on left side pointing sideways, and 4 pins on right side pointing up


- **BME680 Module**
  - Unfortunately, this module can be quite pricey, as the sensor itself is about $4 CAD. Try to find one under $10 CAD, if possible.
  - Granted, *good luck* finding anywhere near as accurate/powerful a sensor for the price point that can do temperature and humidity.
  - It must have VCC, GND, SCL, SDA, SDO, and CS pins as shown. Although Luxigrid doesn't use the SDO and CS pins; just the other pins for the I2C interface
  - For whatever reason, these are usually purple. But you might find one in black or other colour. As long as it has the same board shape and pinout, you should be fine.
  - You will need to solder a 6-pin (or at least a 4-pin; SDO and CS are unused) male header to the pins as shown, with the "back" side of the board facing up. The orientation is very important.

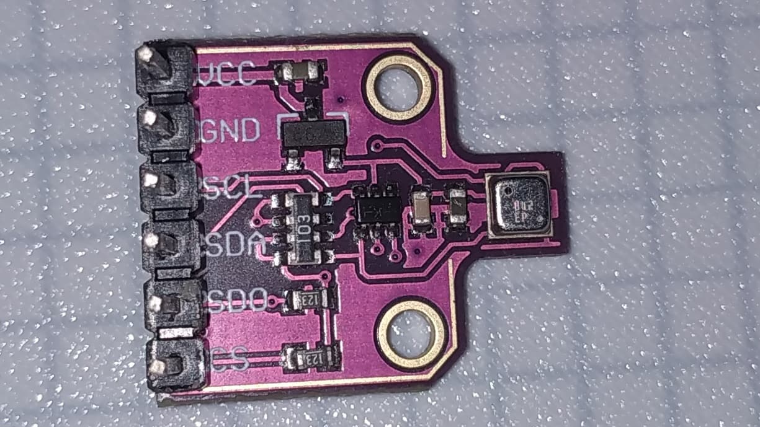
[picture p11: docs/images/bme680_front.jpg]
Front of BME680 module, with 6 header pins sticking up on the left, and the sensor itself on a protrustion of the purple PCB to the right

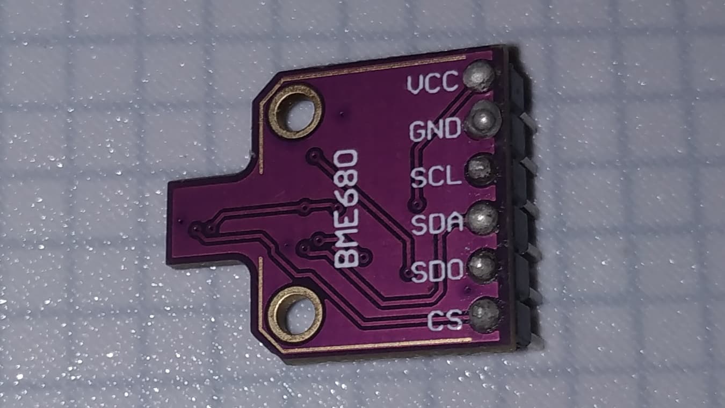
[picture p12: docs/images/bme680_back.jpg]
Bottom of BME680 module, with 6 header pins facing dowards on the right


- **Micro SD Card Module - 3.3V Logic**
  - This is unfortunately one of the trickier ones to find - not because there aren't many out there, but because there are many incompatible products that look similar.
  - This module you want is very small, and it runs off **3.3V logic**. Many Arduino-compatible SD card modules use 5V logic
  - You can generally tell them apart, because the 5V ones are a bit bigger, and they have a little black part with three "legs" and a "hat" - that's the voltage regulator. You don't want one of them.
  - "Mini TF Card Module" might help in your search
  - Try not to get dinged on shipping, but these shouldn't be more than about $1.50 CAD.
  - You're going to want to solder 6 male header pins (often included) facing up from the top
  - So if you put the module on its back (the side without the micro SD card slot) the pins should be pointing down

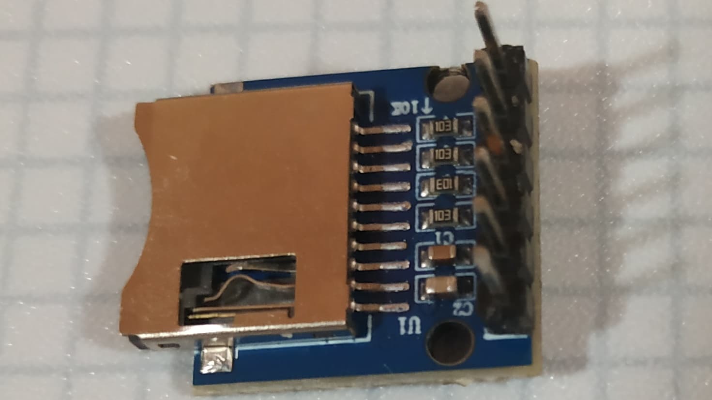
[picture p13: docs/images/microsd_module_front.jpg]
Front of Micro SD Card Module, with 4 small resistors and 2 capacitors beside the Micro SD card slot, and 6 male header pins facing upwards


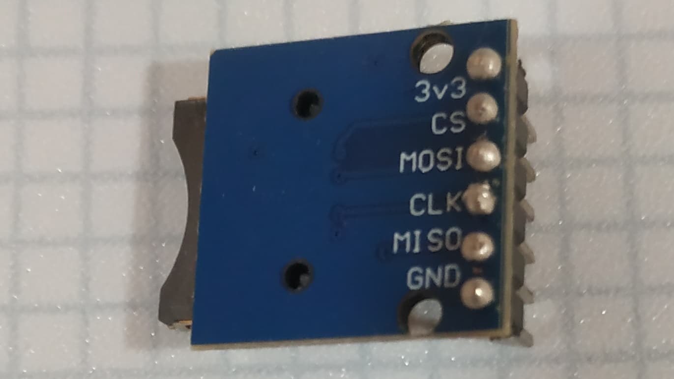
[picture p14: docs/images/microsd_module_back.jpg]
Bottom of Micro SD Card Module, with 6 male header pins facing downwards


- **BH1750 Module**
  - These are readily available, often under the name "GY-302"
  - It's a rectangular board with a BH1750 chip, five pins, and two screw holes
  - You'll need to solder 5 male header pins facing away from the front, where the sensor is (or at least 4; the ADDR pin is unused by Luxigrid)
  - The little black rectangle on the front-middle of the board is the sensor itself

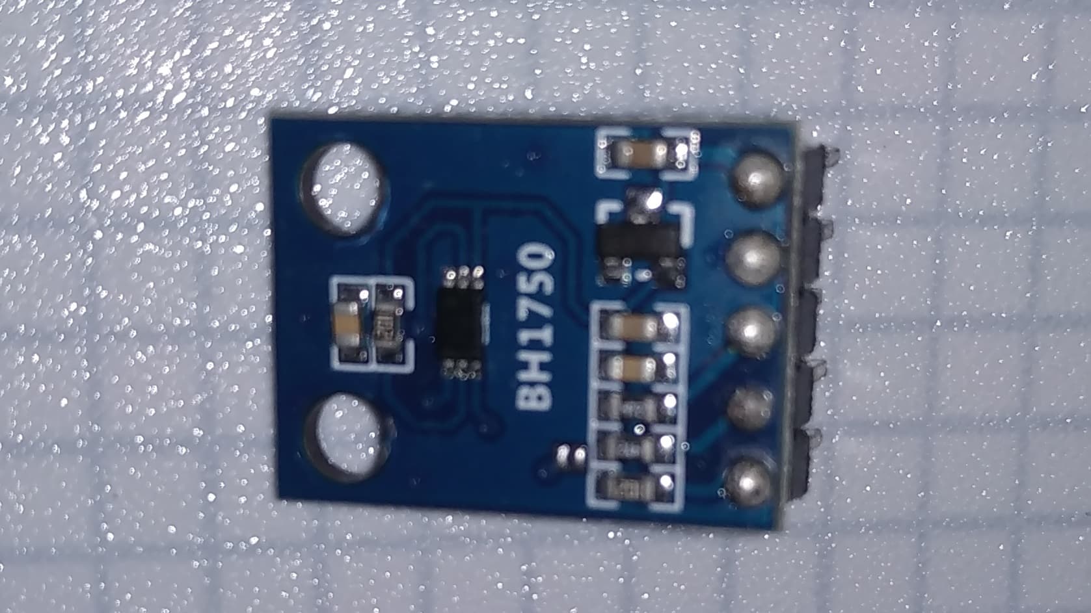
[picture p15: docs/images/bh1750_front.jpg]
Front of BH1750 Module, with two screw holes on one side and five male header pins facing down on the other side. In the middle is a small black rectangle and the text BH1750

Back of the BH1750 Module, called GY-302. Five male header pins are sticking upwards

## Passive Components

- **Resistors - 1K** - x2
  - You'll need two 1K (that's one Kiloohm) resistors for hooking up the buzzer
  - The main requirements are the 1K resistance and that they're through-hole components
  - Resistors are generally a pretty generic part, but these were the ones we found. Anything similar to these is probably going to work: [MFR50SFTE52-1K](https://www.mouser.ca/ProductDetail/603-MFR50SFTE52-1K)

A group of blue 1K resistors with silver leads and colour bands signifying their resistance level

- **Transistor - S8050** - x1
  - You're looking for an NPN transistor with a through-hole footprint
  - There are many good options out there, but we found these ones work really well. The ones with "kinked leads" make soldering them a bit easier: [SS8050DTA](https://www.mouser.ca/ProductDetail/512-SS8050DTA)
  - It doesn't necessarily have to be an S8050, but that part is known to work

A group of S8050 transistors on a strip of tape, with bent legs to allow for easier soldering

- **Passive Piezo Buzzer** - x1
  - These are a pretty generic part, but you definitely want a **passive** buzzer, not an active buzzer
  - Generally the passive ones have a little green circuit board on the bottom
  - You may have to slightly bend the legs to make it fit the PCB, but that should be fine if you're careful

Two passive piezo buzzers, showing a plus side on one side, and a green circuit board on the back

- **DC-Rated Miniature Rocker Switch** - x1
  - These were a royal pain to find, but they're a perfect fit: [Wurth 471002268143](https://www.digikey.ca/en/products/detail/w%C3%BCrth-elektronik/471002268143/9950822)
  - You may also have success with the sister model, the [Wurth 471002268142](https://www.digikey.ca/en/products/detail/w%C3%BCrth-elektronik/471002268142/9950821), which just has a different off symbol.
  - These are fairly expensive, at ~$5 CAD per switch, but they are actually rated for DC current. The majority of miniature rocker switches are only rated for AC, and there's no formula to calculate a safe DC rating for an AC switch.
  - If you decide on a different switch, you may have to adjust the 3D model of the left backplane of the Luxigrid enclosure to fit it. But we would strongly recommend not going with a switch that has not been rated for at least 10A DC. For reference, Luxigrid operates at 5V DC, and may draw upwards of 3A when the screen is fully lit.

A group of black, round Wurth 471002268143 rocker switches with on/off markings and leads to solder onto

## Connectors

- **Spade Terminals/Barrier Terminal Block (1x2, 7.62mm)** - x1
  - You will need a 2-pin barrier terminal block, with 7.62mm, to connect the LED matrix to the Luxigrid PCB

Two barrier terminal blocks, with screws on one side and leads to connect to the PCB on the other side

- **Screw Terminals (1x2, 5mm)** - x1
  - You will need a 2-pin screw terminal block with 5mm pitch, to wire up the power switch
  - We recommend the [Same Sky TB003-500-P02BE](https://www.mouser.ca/ProductDetail/490-TB003-500-P02BE) or a similar product. You need one that's able to support 18 AWG wire, and the higher the voltage and current rating, the better.

Teal screw terminals, with screws on the top, leads on the bottom, and two spots for holding onto wire in the middle

- **DC Barrel Jack** - x1
  - The barrel jack provides power to the PCB. It depends on what power supply you're using, but getting one with an inner diameter of 2.50mm, and an outer diameter of 5.50mm is ideal
  - Don't cheap out on the barrel jack. We recommend the [Same Sky PJ-002BH](https://www.digikey.ca/en/products/detail/same-sky-formerly-cui-devices/PJ-002BH/408447) or something equivalent. It has a DC voltage rating of 24 V, and a current rating of 5A. Most cheap/generic barrel jacks are only "rated" (if they're actually rated at all) at 2.5A or less. Like the power switch, you don't want such a critical part melting on you.

A group of Same Sky PJ-002BH barrel jacks, with three PCB connector pins

## Headers

You will need some female 2.54mm "Dupont" style PCB headers, to connect parts like the sensors and ESP32 to the PCB.

- *Note: This assumes the Modules above all came with male header pins, as shown in the pictures above, which is likely. Otherwise, you would have to order those separately*

- 2x8 Female Header Block - x1

Black plastic header blocks with metal pins stickig out the bottom. There are two rows of 8 pins in each

- 1x4 Female Header Block - x3

- 1x6 Female Header Block - x1

- 1x19 Female Header Block - x2

- *Pro Tip:* You're probably going to be out of luck finding 1x19 female header pins. But with a bit of practice, you can cut one pin off a 1x20 pin block with side cutters or a hobby knife (be careful) and sand it down a bit until it's flush.
  - Once you know how to do that, you can buy **1x40** female header blocks for pretty cheap. So you don't necessarily have to find these specific sizes, once you learn how to cut them down to size
  - You should still probably get a 2x8 female header block, though. The bigger blocks are harder to cut, and you'll want the PCB to line up properly with the LED matrix

40-pin male header blocks, showing how side cutters can be used to cut them down into smaller sizes

You could technically solder certain parts directly onto the Luxigrid PCB, but the 3D printing files were not designed with that in mind. And with headers, you can more easily replace a specific component if it ever fails, instead of having to replace the whole board, which is probably more convenient and slightly less wasteful.

## Fasteners

- You're looking for the following sizes/quantities of metric "Socket Head Cap Screws" or "Hex Socket Cap Screws" or something like that. They're pretty ubiquitous.

- **M3 x 10mm** - x16
  - These hold the main part of the Luxigrid enclosure together, and keep the PCB in place
  - Eight of them will be screwing into threaded inserts on the matrix diffusers, six will be screwing into the integrated threads on the LED matrix itself, and two will hold the PCB

- **M2.5 x 8mm** - x4-8
  - These are for attaching the BH1750 light sensor (x2), the micro SD card module (x2), and the RTC and BME680 sensor. For the RTC and BME680 sensor, you may only want one screw, or none at all

- **M4 x 12mm** - x4
  - These are for attaching the desk mount bracket to the back of the right backplane, via the threaded inserts

- **M4 x 30mm** - x1
  - This is for the desk mount. It acts like a peg to hold it together.
  - *You can use a longer screw than 30mm, because it will just stick out the other end of the desk mount, but at least 30mm is recommended*

- **M4 Nut** - x1
  - The specific shape of nut probably won't matter, as long as it has M4 threads and isn't too big
  - But you're not looking for a nylon lock nut, just a regular M4 nut
  - This is for the desk mount, by the way

An M4 nut, a M4x12mm screw, an M2.5 x 8mm screw, a black M3 x 10mm screw (the others are stainless steel) and a long M4 screw that is over 30mm

- *Pro Tip:* Buy these types of fasteners in bulk or as a kit when you can, for decent savings down the road. Especially if you plan on doing more 3D printing projects, having some metric hex cap screws is never a bad idea. You can get a lot of mileage off a 100-pack of M3 x 10mm's or M4 x 12mm's, for instance.
  - You can commonly see the black carbon screws or stainless steel screws. Stainless is a *bit* more expensive and it won't blend in if you made a black Luxigrid, but it's shinier and won't rust as easily. Your call; neither's a bad choice.

## Hookup Wire

- **18 AWG Wire for the Power Switch**
  - Flexible copper wire with silicone insulation is probably the easiest to work with in this case
  - You only need about 10-20cm to hook up the power switch, but you may find it easier to buy it by the meter

About a metre of 18 AWG wire with red insulation, spooled up in a plastic bag

- **Female-to-Male Dupont Cables (20mm)** - x4
  - These colourful pre-made cables are often used with breadboard and Arduino projects
  - You need four of them to hook up the BH1750; they're often available in packs of 10-40 for a reasonable price
  - Make sure you get the ones with one female end and one male end

A group of colourful Dupont cables, with male ends on one side and female ends on the other

## Other Components

- **Luxigrid PCB**
  - See the [Assembly Instructions](../ASSEMBLY.md) for more information on procuring and assembling the PCB
  - Here are pictures of the front and back of the board, before populating it with parts

The front of the Luxigrid PCB

The back of the Luxigrid PCB

- **5V 4A Power Supply**
  - You're looking for something that safely outputs at 5V DC at at least 4A (or 5A+)
  - Luxigrid pulls upwards of 3A when the screen is completely lit and at full brightness.
  - Look for something with a 2.5mm barrel connector
  - You may require an AC extension cord to extend the wall side of the power supply. We do not recommend extending the DC/barrel connector side of the cable, or putting an inline switch on it, etc. They are likely not rated for this amount of current.

- **CR2032 Coin Cell Battery**
  - For the Real-Time Clock module, to keep the time even when your Luxigrid is off, or during a power outage
  - Some RTC modules come with batteries, but you can find these almost anywhere
  - It's probably cheaper to buy this separately, instead of buying an RTC module that comes with a battery

- **Micro SD Card**
  - *At least 4GB recommended*
  - The size of the card you need is basically determined by how many big GIFs you might want to put on it
  - Other things (configuration files, etc.) don't take up much space at all, but GIFs can be pretty big depending on their length/quality

- **Heated Inserts**
  - The diffusers and right backplane require heated inserts
  - We recommend **6mm M3 w/ 4.5mm OD** inserts (of which you'll need **8**) for the diffusers and **5mm M4 w/ 6mm OD** inserts for the right backplane (you need **2** of these)
  - There are many types, of varying quality and effectiveness. Try to find ones designed with 3D printing in mind - not just injection molding. If they're tapered near the end, with two sets of opposing knurls on the outside, they will probably work. But your mileage may vary.
  
  M3 heated inserts made of brass

  M4 heated inserts made of brass

- **Stainless Steel Filter Screen** (optional)
  - If you want to cover the holes in the back of the enclosure with a filter to mitigate dust build-up, there are various options
  - You want something with holes large enough to allow some airflow, but small enough to block most dust - and something that won't tear easily.
  - A **"120 Mesh" Stainless Steel Filter Screen** is what we usually go with. You should only need about **150 square centimetres** for the four filter plates. You can usually buy it by the square meter
  - You will need to cut it into 4 rectangular pieces, roughly 4 cm x 9.5 cm.
  - These may be difficult to find, but they are out there on sites like Aliexpress if you're persistent.

A stainless steel mesh that is fine, but still somewhat see-through

## Tools/Consumables

- **Allen Keys/Screwdriver**
  - M2.5
  - M3
  - M4
  - *Pro Tip:* If Allen Keys frustrate you, look into a "Precision Screwdriver Set" that comes with metric hex bits.
  - You'll also need some precision Phillips bits for screwing down some connectors, but you may already have some lying around.

- **Wire Strippers/Cutters**
  - For preparing the wire to hook up the power switch, you should use strippers capable of stripping 18 AWG gauge wire
  - You might be able to use this to cut the header blocks, if that's your plan. Otherwise you'll also need **side cutters**.

- **Soldering Iron**
  - Any iron will technically do, but at least basic temperature control is a major plus
  - We used a Hakko FX-888D for what it's worth, but a cheaper iron should do the trick - if you're patient and have at least a bit of practice
  - Also Flux. Use Lots of Flux to help the solder flow properly (you can clean it off finished parts with a toothbrush and some rubbing alcohol - there are many good tutorials for that out there) - just don't brush your teeth with it after! 😂

- **Heated Insert Tips for Soldering Iron**
  - Certain 3D printed parts of the Luxgrid enclosure (the matrix diffusers and the right backplane) require installing heated inserts.
  - A convenient way to install these is to swap the tip of your soldering iron with a special tip dedicated to heated inserts.
    - You'll need at least two heated insert tip sizes - for M3 and M4 inserts
    - You may be able to buy an adapter that fits onto the end of your iron, so you can swap out the M3 or M4 insert tip
  - Just be careful when changing the tips, that your soldering iron isn't on or still hot!
  - It takes a bit of practice, but it's not too difficult once you get the hang of it - and there are many helpful resources out there for threaded inserts and 3D printing

An example of brass adapters for heated inserts on the end of a soldering iron

- **Hot Glue Gun**
  - If you want to install the optional dust screens on the back of the enclosure, you'll need some kind of glue to attach them
  - Hot Glue is pretty convenient, but there are other options
  - Just make sure whatever you're using can stick to the plastic you printed with, and that it doesn't eat away at it. Some adhesives are corrosive or reactive with certain types of palstic.
  - You might go through a few sticks of hot glue in the process.

- **Multimeter**
  - For testing and troubleshooting electrical connections, a multimeter is a good tool to have on hand. Even a cheaper one should do the trick. Even if you're just using it for continuity tests or voltage measurements, it can help to eliminate some pesky variables in the event something goes wrong. If you want some features/precision, or you want to measure the amperage draw of anything, you may want a slightly more sophisticated model, although you shouldn't have to spend too much to get something usable enough for this project. The cheapest ones often can't safely measure more than a few hundred mA of current, which parts of Luxigrid's circuits can easily draw.

## 3D Printing Requirements

- **3D Printer**
  - Obviously 😂
  - Use whatever you're comfortable with, but Luxigrid was designed to be printed on an FDM printer with PLA or PETG filament
  - Some of the parts, especially the diffusers, may be difficult to print unless you have a well-tuned printer with reasonable dimensional accuracy and excellent build surface adhesion
  - We used a Prusa MK3.9 during the design process, but there are many good options out there
  - See the [3D Printing Instructions](./3D.md) for more information

- **Filament**
  - **~400g** needed to print entire enclosure
    - Assuming 0.4mm nozzle and 0.20mm layer height, and using recommended supports/orientations from 3MF files
  - **White Filament** (minimum 12g used for the diffusers)
  - **Black Filament** (minimum 38g used for the diffusers)
  - **Another Colour** (unless you want a white or black Luxigrid, in which case you're set)

- **Filament Notes:**
  - Use as bright white and as dark black as you can find. The diffuser effect won't work with any other colours. The accent colour, however, can be whatever you like
  - You can use whatever kind of filament you like, but at least the diffuser has to be made from filaments that will stick to each other (ideally the same kind of filament)
  - Your mileage may vary, but we've found that PLA won't stick to PETG at all, and PVB *might* stick to PLA well enough to finish a print, but it'll have to be glued together later, which could get messy.

- **Sandpaper (recommended)**
  - A few of the parts require printing with brims and/or support material which may leave minor surface defects upon removal
  - It's a good idea to have some sandpaper handy (of various grit levels, depending on your pateience and the amount of material you need to remove)

- **Post-Processing/Deburring Tools (recommended)**
  - For those ornery stray bits of plastic, some kind of metal deburring tool can come in handy
  - A tool called a "Double Sided Prying Tool" or "Metal Spudger" can also come in handy for removing brims or scraping away at excess plastic

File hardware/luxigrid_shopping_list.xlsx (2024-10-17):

Luxigrid Shopping List
Item Name: | Optional? | Min. Quantity Required | Recommended Part # | Found at Link: | Purchased? | Purchased On: | Paid:
Modules:
P4 64x32 LED Matrix |  | 1
ESP32-DevKitC V4 Board |  | 1
DS3231 RTC Module |  | 1
BME680 Module |  | 1
Micro SD Card Module – 3.3V Logic |  | 1
BH1750 Module |  | 1
Passive Components:
1K Resistor |  | 2 | Various, MFR50SFTE52-1K
S8050 NPN Transistor |  | 1 | Various, SS8050DTA
Passive Piezo Buzzer |  | 1
DC-Rated Miniature Rocker Switch |  | 1 | Wurth 471002268143 OR Wurth 471002268142
Connectors:
Barrier Terminal Block (1x2, 7.62mm) |  | 1
Screw Terminals (1x2, 5mm) |  | 1 | Same Sky TB003-500-P02BE
DC Barrel Jack (5A Rated) |  | 1 | Same Sky PJ-002BH
Headers:
2x8 Female Header Block |  | 1
1x4 Female Header Block |  | 3
1x6 Female Header Block |  | 1
1x19 Female Header Block (or 1x20 and cut it down to size) |  | 2
OR
1x40 Female Header Block (and cut it down to size) |  | 2
Fasteners:
M3 x 10mm |  | 16
M2.5 x 8mm |  | 4 – 8*
M4 x 12mm |  | 4
M4 x 30mm |  | 1
M4 Nut |  | 1
Hookup Wire:
18 AWG Wire (Flexible copper w/ silicone insulation recommended) |  | 10 – 20 cm
Female to Male Dupont Cables (20mm) |  | 4
Other Components:
Luxigrid PCB |  | 1
5V 4A+ Power Supply |  | 1
CR2032 Coin Cell Battery |  | 1
Micro SD Card (at least 4GB recommended) |  | 1
6mm M3 w/ 4.5mm OD heated inserts |  | 8
5mm M4 w/ 6mm OD heated inserts |  | 2
120 Mesh Stainless Steel Filter Screen | * | 150 Square Centimetres
3D Printing Filament:
White Filament |  | 12g
Black Filament |  | 38g
Another Colour |  | 345g
Tools/Consumables:
M2.5 Allen Key
M3 Allen Key
M4 Allen Key
Precision Phillips Screwdriver
OR
Precision Screwdriver Set with Metric and Phillips bits
Wire Strippers/Cutters
Soldering Iron
Solder
Flux
Toothbrush (for cleaning flux off PCB)
Isopropyl Alcohol (99%)
M3 Heated Insert Tip for Soldering Iron
M4 Heated Insert Tip for Soldering Iron
Hot Glue Gun | *
Hot Glue Sticks | *
Multimeter
Sandpaper (Various Grits)
Metal Spudger
Side Cutters
Please Note:
OverScore Media does not guarantee that any of this information is accurate or up-to-date. It is provided for informational purposes only, in the hope that it will be useful. Please see the Luxigrid documentation for more details.

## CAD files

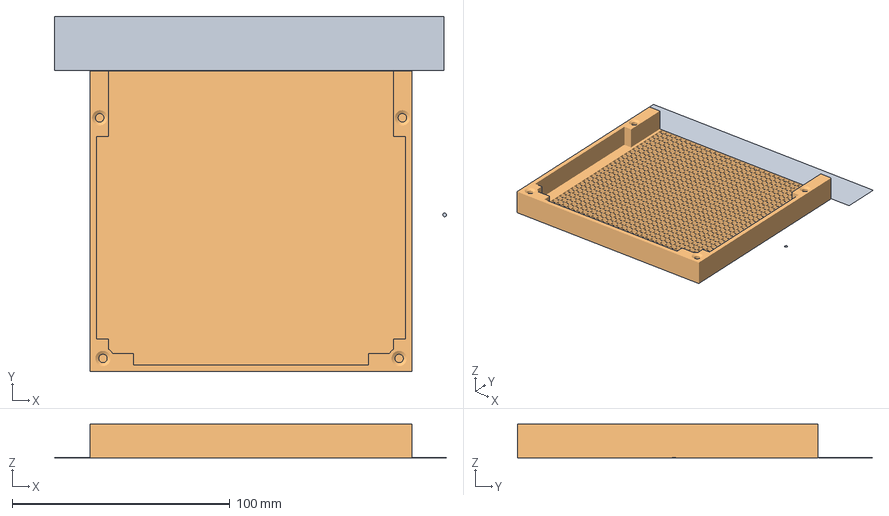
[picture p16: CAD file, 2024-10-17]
hardware/3d/3MF/matrix_diffuser_no_lip.3mf
180.0 x 163.0 x 15.5 mm
Shape-Box
matrix_diffuser_no_lip.stl

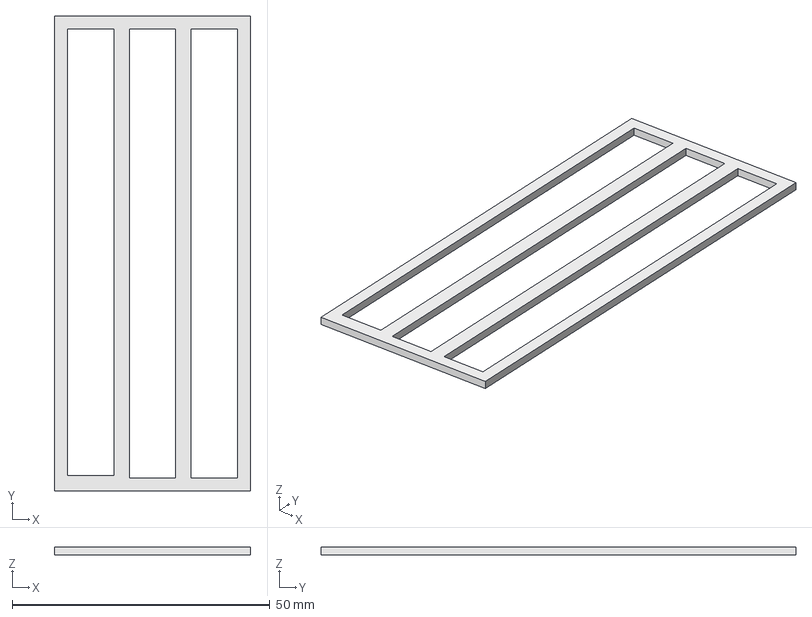
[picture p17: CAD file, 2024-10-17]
hardware/3d/STEP/backplane_mesh_holder.step
38.0 x 92.0 x 1.50 mm

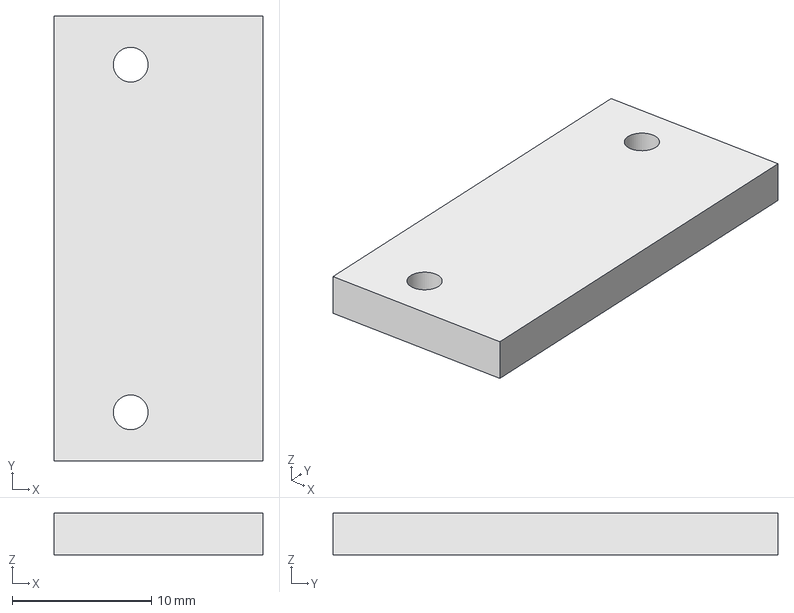
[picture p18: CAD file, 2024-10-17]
hardware/3d/STEP/sd_hat.step
15.0 x 32.0 x 3.00 mm

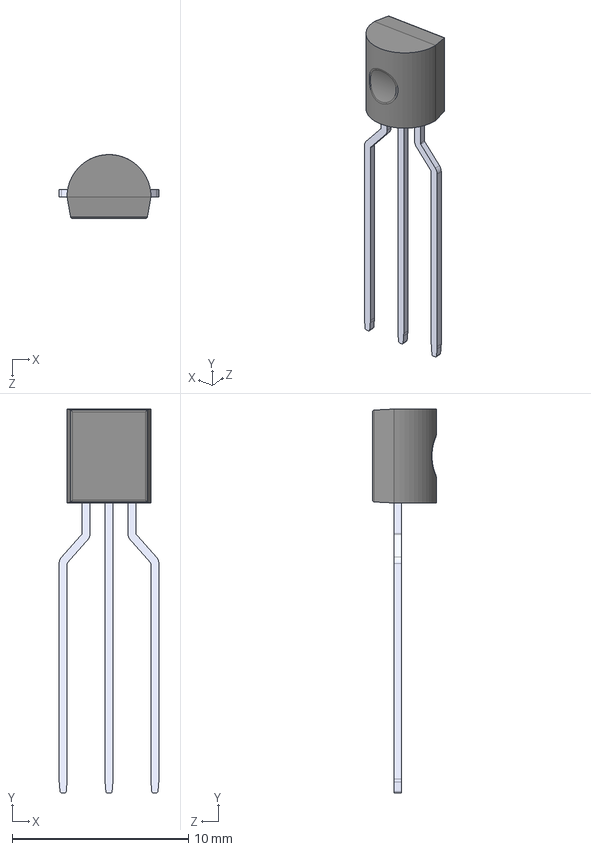
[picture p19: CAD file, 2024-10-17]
hardware/pcb/kicad/3d_models/SS8050DTA.step
5.66 x 21.8 x 3.62 mm

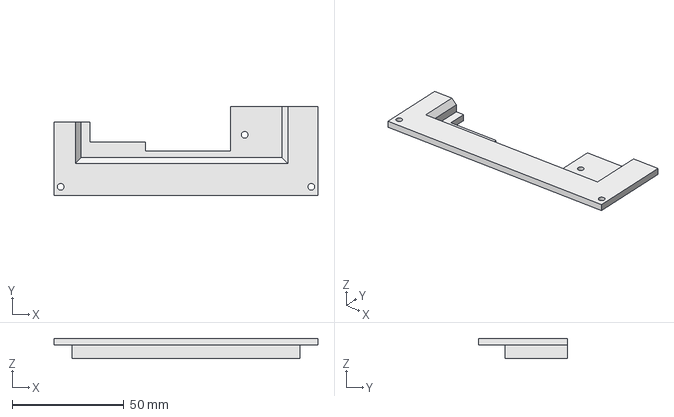
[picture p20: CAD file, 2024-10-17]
hardware/3d/STEP/right_pcb_bracket.step
118.0 x 40.0 x 9.00 mm

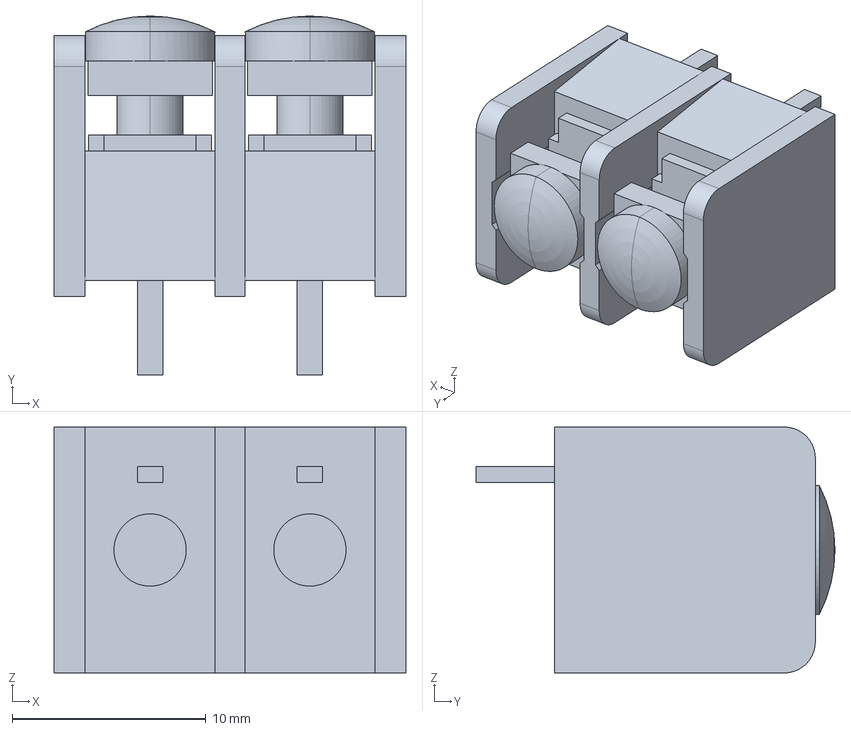
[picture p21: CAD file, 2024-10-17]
hardware/pcb/kicad/3d_models/c-2-1437667-4-n-3d.stp
18.2 x 18.5 x 12.7 mm

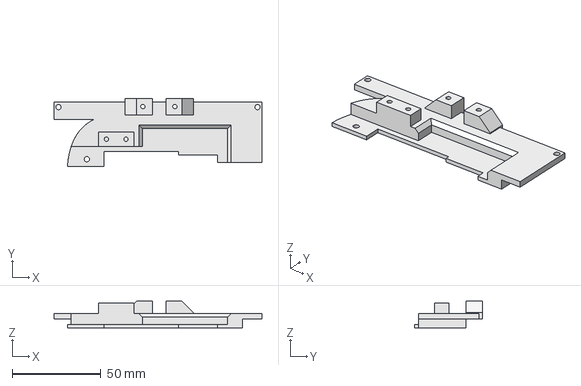
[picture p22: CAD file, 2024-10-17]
hardware/3d/STEP/left_pcb_bracket.step
117.0 x 38.5 x 15.0 mm

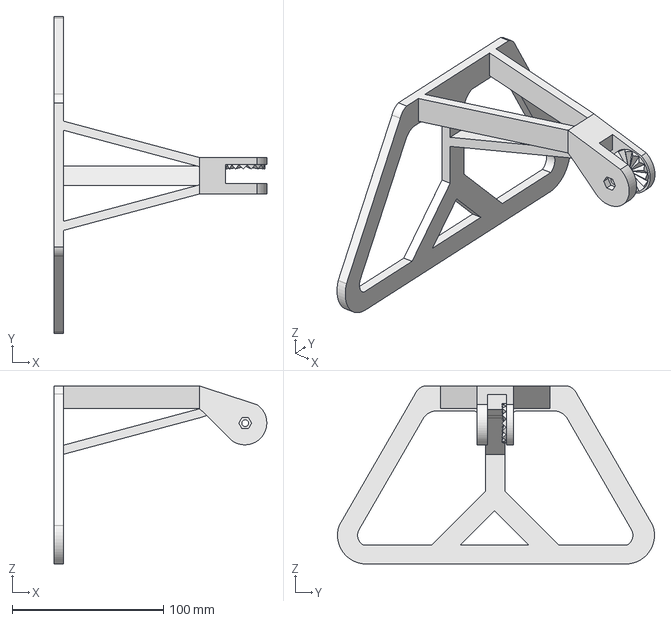
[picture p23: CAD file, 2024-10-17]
hardware/3d/STEP/desk_mount.step
140.4 x 209.3 x 117.5 mm

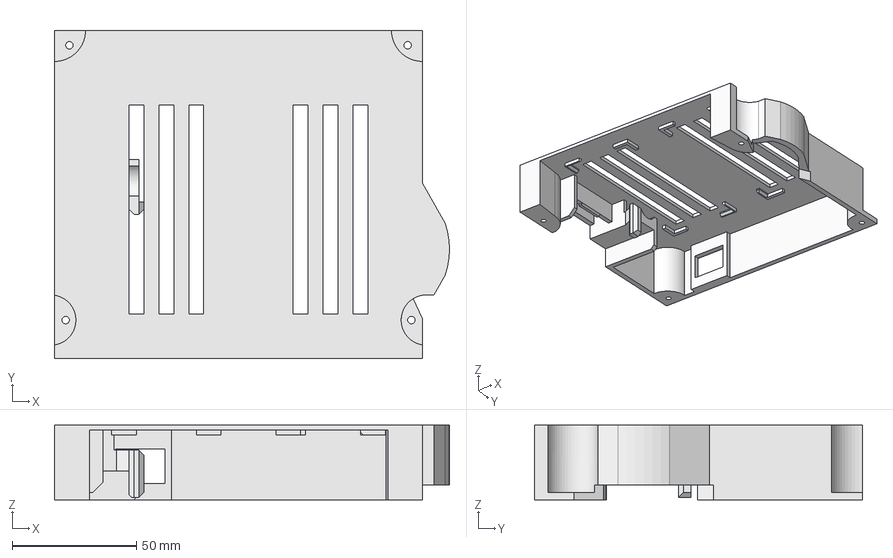
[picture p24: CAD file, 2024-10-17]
hardware/3d/STEP/left_backplane.step
158.8 x 132.0 x 30.0 mm

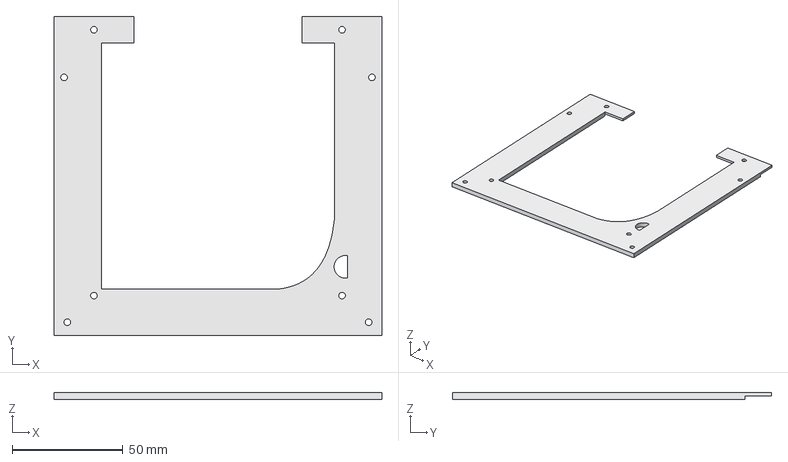
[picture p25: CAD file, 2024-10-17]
hardware/3d/STEP/right_bracket.step
148.0 x 144.0 x 3.00 mm

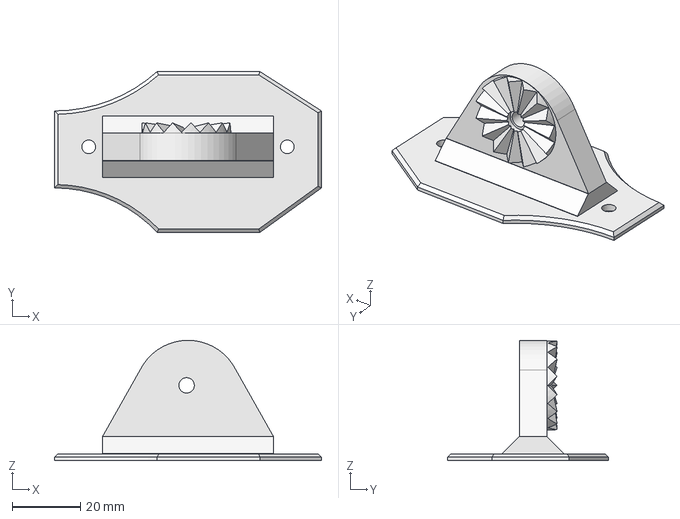
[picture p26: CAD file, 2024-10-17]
hardware/3d/STEP/desk_mount_bracket.step
78.0 x 47.0 x 35.2 mm

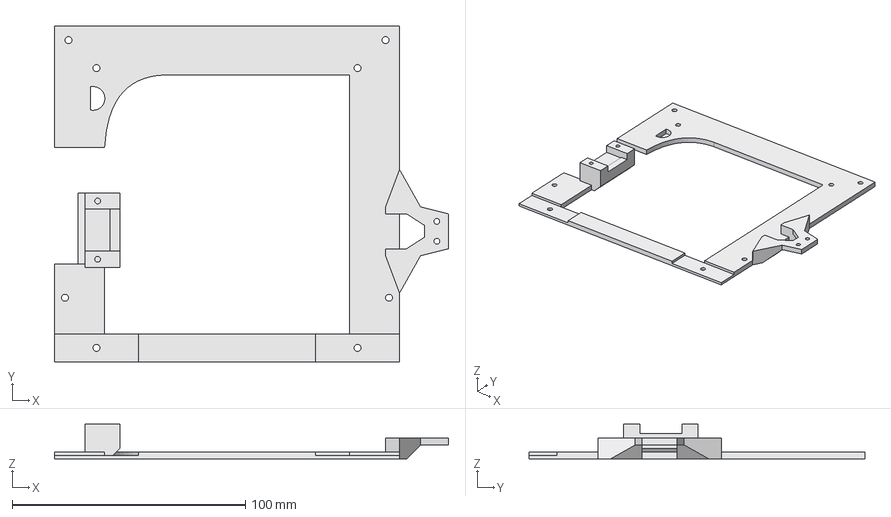
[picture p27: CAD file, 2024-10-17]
hardware/3d/STEP/left_bracket.step
169.0 x 144.0 x 15.0 mm

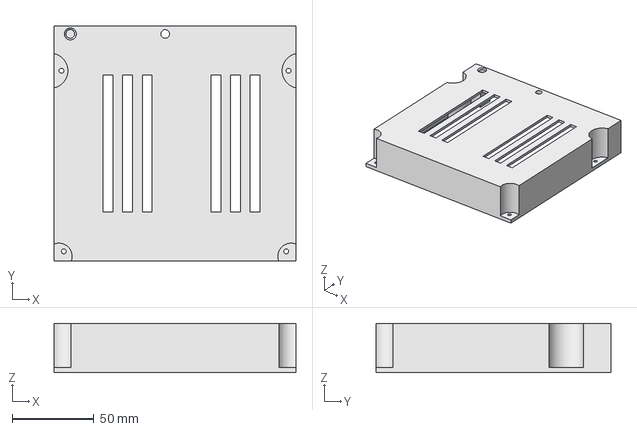
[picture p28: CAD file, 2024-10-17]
hardware/3d/STEP/right_backplane.step
148.0 x 144.0 x 30.0 mm

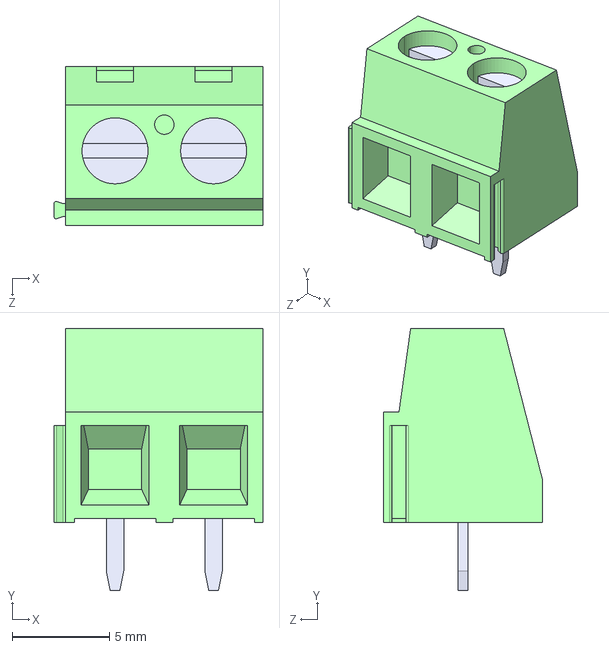
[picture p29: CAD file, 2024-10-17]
hardware/pcb/kicad/3d_models/282837-2.step
10.8 x 13.5 x 8.20 mm

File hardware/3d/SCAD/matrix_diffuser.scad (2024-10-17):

/* _    _  _ _  _ _ ____ ____ _ ___
 * |    |  |  \/  | | __ |__/ | |  \
 * |___ |__| _/\_ | |__] |  \ | |__/
 * =================================
 * Luxigrid - LED Matrix Diffuser
 * Copyright (c) 2024 OverScore Media - MIT License
 *
 * MIT LICENSE:
 * Permission is hereby granted, free of charge, to any person obtaining a copy of
 * this software and associated documentation files (the "Software"), to deal in
 * the Software without restriction, including without limitation the rights to
 * use, copy, modify, merge, publish, distribute, sublicense, and/or sell copies of
 * the Software, and to permit persons to whom the Software is furnished to do so,
 * subject to the following conditions:
 *
 * The above copyright notice and this permission notice shall be included in all
 * copies or substantial portions of the Software.
 *
 * THE SOFTWARE IS PROVIDED "AS IS", WITHOUT WARRANTY OF ANY KIND, EXPRESS OR
 * IMPLIED, INCLUDING BUT NOT LIMITED TO THE WARRANTIES OF MERCHANTABILITY, FITNESS
 * FOR A PARTICULAR PURPOSE AND NONINFRINGEMENT. IN NO EVENT SHALL THE AUTHORS OR
 * COPYRIGHT HOLDERS BE LIABLE FOR ANY CLAIM, DAMAGES OR OTHER LIABILITY, WHETHER
 * IN AN ACTION OF CONTRACT, TORT OR OTHERWISE, ARISING FROM, OUT OF OR IN
 * CONNECTION WITH THE SOFTWARE OR THE USE OR OTHER DEALINGS IN THE SOFTWARE.
 */


/* [LED Matrix size settings] */
// The pitch of the panel, in millimetres (P4 is 4, P3 is 3, and so on)
pixel_pitch = 4;

// The number of rows (horizontal) of LEDs
number_of_rows = 64;
// The number of columns (vertical) of LEDs
number_of_columns = 32;

// The size of half the matrix (assuming this can't be printed in one piece)
grid_width = (number_of_rows * pixel_pitch) / 2;
grid_height = number_of_columns * pixel_pitch;

/* [Diffuser Grid settings] */
// The height, in mm, of the grid
wall_height = 2;
// The width, in mm, of the gridlines
wall_width = 0.5;

/* [Bezel Settings] */
// The width of the bezel around the diffuser grid
bezel_width = 10;

// Distance from the first layer to the bottom of the bezel
bezel_height = 13.5;
distance_to_bracket =  bezel_height + wall_height;

// The width of the margin from the grid to the bezel
bezel_margin = 1.25;

// How thick the bezel should be at its thinnest points (i.e., away from the screw holes)
thin_bezel_width = 3;

// Distance from the side wall to the start of the top/bottom wall cutouts
top_bottom_wall_cutout_margin_wall = 15;
// Distance from the open end to the start of the top/bottom wall cutouts
top_bottom_wall_cutout_margin_open = 35;
// Distance from the corner to the start of the side wall cutout
side_wall_cutout_margin = 20;

/* [Screw Hole Settings] */

// The diameter of the screw holes in the bezel
screw_hole_diameter = 4.0; // 4.0 for M3 OD4.5 L6 Heated Inserts

// The distance from the corners of the bezel to the middle of the screw holes
screw_hole_offset = 6;

// Note how the calculation for the actual offset involves subtracting the radius of the screw holes
screw_hole_corner_offset = screw_hole_offset - (screw_hole_diameter / 2);

// The horizontal offset from the middle of the matrix to the interior screw holes
interior_screw_horizontal_offset = 15;
// The horizontal offset from the inner edge of the bezel to the interior screw holes
interior_screw_vertical_offset = 1.5;
// The depth, in mm, that the screws protrude into the walls of the bezel
screw_hole_depth = 7; // 7 for M3 OD4.5 L6 Heated Inserts

// The extra radius of the cylinders extending from the screw holes on the corners
corner_screw_hole_supports_offset = 3;

// For the "fillets" on the tops of the screw holes, to aid in the placement of heated inserts
screw_hole_fillet_size = 7; // 7 for M3 OD4.5 L6 Heated Inserts

/* [First Layer Settings] */
// Height of the first layer
first_layer_height = 0.2;

// Set this to 0 if you don't want a lip
// You'll want to print one diffuser with a first layer lip, and one without one for best results
// First layer overhang/lip amount so there's less of a seam between the diffuser panels
first_layer_overhang = 0.5; // Generally 0.5 works

// First Layer
translate([-grid_width / 2 - (bezel_width), (-grid_height / 2) + (wall_width / 2) - bezel_width, 0])
    color([1, 0, 0])
    cube([grid_width + (bezel_width * 2), grid_height + bezel_width + first_layer_overhang, first_layer_height]);


// Diffuser Grid
for(x = [0 : pixel_pitch : grid_width - pixel_pitch + wall_width]) {
    for(y = [0 : pixel_pitch : grid_height - pixel_pitch + wall_width]) {
        // Vertical grid walls
        translate([(x - grid_width / 2 - wall_width / 2), (y - grid_height / 2 - wall_width / 2), first_layer_height]) {
            cube([wall_width, wall_width + pixel_pitch, wall_height]);
        }

        // Horizontal grid walls
        translate([(x - grid_width / 2 - wall_width / 2), (y - grid_height / 2 - wall_width / 2), first_layer_height]) {
            cube([wall_width + pixel_pitch, wall_width, wall_height]);
        }
    }
}


// Additional vertical grid wall at the end (otherwise grid is cut-off at the top)
translate([(grid_width / 2 - wall_width / 2), (-grid_height / 2 + wall_width / 2), first_layer_height]) {
    cube([wall_width, grid_height, wall_height]);
}


// Additional horizontal grid wall at the end
translate([(-grid_width / 2), (grid_height / 2), first_layer_height]) {
    cube([grid_width, wall_width / 2, wall_height]);
}


// The walls around the grid, protruding down to the bracket on the other side of the LED matrix
module walls() {
    // Wall 1
    translate([-grid_height / 2 - bezel_width, -grid_width / 2 - bezel_width + wall_width / 2, 0]) {
        cube([bezel_width - wall_width / 2, bezel_width + grid_width, distance_to_bracket]);
    }

    // Wall 2
    translate([grid_height / 2 + wall_width/2, -grid_width / 2 - bezel_width + wall_width / 2, 0]) {
        cube([bezel_width - wall_width/2, bezel_width + grid_width, distance_to_bracket]);
    }

    // Wall 3
    translate([-grid_width / 2 - bezel_width / 2, -grid_width / 2 - bezel_width + wall_width / 2, 0]) {
        cube([bezel_width + grid_width, bezel_width - wall_width, distance_to_bracket]);
    }
}


// This cube represents a volume that will be subtracted from the sides of the walls, so there will be a margin between the walls and the LED matrix
module wall_margins() {
    translate([-grid_width / 2 - wall_width / 2 - bezel_margin, -grid_height / 2 - wall_width / 2 - bezel_margin, wall_height + first_layer_height]) {
        color([1, 0.6, 1]) {
            cube([grid_width + wall_width + bezel_margin * 2, grid_height + wall_width + bezel_margin + 0.01, distance_to_bracket - wall_height]);
        }
    }
}


// The screw holes in the walls around the grid
module screw_holes() {
    rotate([0, 180, 0]) {
    
        // The 0.01's are to prevent z fighting in the difference() with the walls
        translate([(grid_width / 2 + bezel_width - screw_hole_diameter / 2 - screw_hole_corner_offset), -(grid_width / 2 + bezel_width - screw_hole_diameter / 2 - wall_width / 2 - screw_hole_corner_offset), -distance_to_bracket - 0.01]) {
            cylinder(h=screw_hole_depth + 0.01, r=screw_hole_diameter / 2, $fn=100);
        }

        translate([(-grid_width / 2 - bezel_width + screw_hole_diameter / 2 + screw_hole_corner_offset), -(grid_width / 2 + bezel_width - screw_hole_diameter / 2 - wall_width / 2 - screw_hole_corner_offset), -distance_to_bracket - 0.01]) {
            cylinder(h=screw_hole_depth + 0.01, r=screw_hole_diameter / 2, $fn=100);
        }
        
        
        translate([(grid_width / 2 + bezel_width - screw_hole_diameter / 2 - screw_hole_corner_offset) + interior_screw_vertical_offset, (grid_width / 2 - screw_hole_diameter / 2 - wall_width / 2 - screw_hole_corner_offset) - interior_screw_horizontal_offset, -distance_to_bracket - 0.01]) {
            cylinder(h=screw_hole_depth + 0.01, r=screw_hole_diameter / 2, $fn=100);
        }

        translate([(-grid_width / 2 - bezel_width + screw_hole_diameter / 2 + screw_hole_corner_offset) - interior_screw_vertical_offset, (grid_width / 2 - screw_hole_diameter / 2 - wall_width / 2 - screw_hole_corner_offset) - interior_screw_horizontal_offset, -distance_to_bracket - 0.01]) {
            cylinder(h=screw_hole_depth + 0.01, r=screw_hole_diameter / 2, $fn=100);
        }
    }
}

// Poor man's fillets around the screw holes
// Basically cylinders with one smaller end and one larger end, subtracted from the tops of the screw holes
module screw_hole_fillets() {
    rotate([0, 180, 0]) {
        // The 0.01's are to prevent z fighting in the difference() with the walls
        translate([(grid_width / 2 + bezel_width - screw_hole_diameter / 2 - screw_hole_corner_offset), -(grid_width / 2 + bezel_width - screw_hole_diameter / 2 - wall_width / 2 - screw_hole_corner_offset), -distance_to_bracket - 0.01]) {
            cylinder(h=1 + 0.01, r1=screw_hole_fillet_size / 2, r2=screw_hole_diameter / 2, $fn=100);
        }
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

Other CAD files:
hardware/3d/3MF/matrix_diffuser_with_lip.3mf
hardware/3d/3MF/left_backplane.3mf
hardware/3d/3MF/left_bracket.3mf
hardware/3d/3MF/left_pcb_bracket.3mf
hardware/3d/3MF/right_backplane.3mf
hardware/3d/3MF/right_pcb_bracket.3mf
hardware/3d/STL/backplane_mesh_holder.stl
hardware/3d/STL/desk_mount.stl
hardware/3d/STL/desk_mount_bracket.stl
hardware/3d/STL/left_backplane.stl
hardware/3d/STL/left_bracket.stl
hardware/3d/STL/left_pcb_bracket.stl
hardware/3d/STL/matrix_diffuser_no_lip.stl
hardware/3d/STL/matrix_diffuser_with_lip.stl
hardware/3d/STL/right_backplane.stl
hardware/3d/STL/right_bracket.stl
hardware/3d/STL/right_pcb_bracket.stl
hardware/3d/STL/sd_hat.stl

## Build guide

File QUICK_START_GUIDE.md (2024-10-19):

# Luxigrid - Quick Start Guide

## Coming Soon

Sorry, this document is currently undergoing final proofreading and polish. It will be available very soon.

If you have any questions in the meantime, feel free to reach out to us on [our website](https://luxigrid.overscore.media/), or [open an Issue](https://github.com/overscore-media/luxigrid/issues) on this GitHub repository.

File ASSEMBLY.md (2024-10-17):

# Luxigrid - Assembly Documentation

This document presumes you have read the [Bill of Materials](./hardware/BOM.md) and the [3D Printing Documentation](./hardware/3D.md). They reference each other, but this document is primarily concerned with the physical assembly process.

**Please Note:** OverScore Media does not guarantee that any of this information is accurate or up-to-date. It is provided for informational purposes only, in the hope that it will be useful. Any images are for illustration only. If you choose to follow these instructions, you do so at your own risk. This is just to let you know what you might be in for. Please be careful.

## Procuring the PCB

Luxigrid uses a custom printed circuit board (PCB) at its heart. If you want to build a Luxigrid of your own, you will need to get one.

You can purchase just a PCB from [our website](https://luxigrid.overscore.media) (assembled or not assembled), or you can get it fabricated for you. As an open hardware design, you have access to all the files you should need to get the PCB fabricated. You also have access to the KiCad source files, if you want to make modifications to the PCB. You probably want to use the version without rounded traces to make adjustments to the design. Then you can use the wonderful [KiCad Round Tracks](https://github.com/mitxela/kicad-round-tracks) plugin by @mitxela to generate neat rounded traces. It's mostly a style thing, but we really like the look of it. It hearkens back to the days of designing PCBs by hand - but like, in a good way.

Anyway... let's assume you don't want to make modifications to the PCB design, and you just want to order some. Now, generally you can't order just one - many fabricators produce them in batches, with the smallest batch size often being 5 boards. Keep that in mind.

There are many places to order custom PCBs, like JLCPCB, PCBWay, OSHPark, Seeed Studio, Aisler, and others. Wherever you choose to get the boards made, you will need the **Gerber** files. For convenience, we have provided pre-generated Gerbers in a .zip file, in the `/hardware/pcb/gerbers` folder. Depending on the tolerances of your chosen manufacturer, you may want to adjust the settings and generate your own Gerbers from the included KiCad project. But these have worked for us with JLCPCB.

When ordering the boards, most manufacturers let you upload the Gerber files directly, and modify the options. If you're careful and not too picky, you can keep the price down. We recommend going with a 1.6mm board, Lead-Free HASL coating, and tented vias. Many manufacturers also let you choose the colour of the solder mask. We normally go with black, since it looks neat.

When choosing JLCPCB, we go with the "Order Number (Specify Position)" option. Hence the little "JLCJLCJLC" text on the back of the PCB design. That will be replaced with an order number by the factory. For reference, this is the order we usually go for with JLCPCB. Please note that OverScore Media is not specifically endorsing or disapproving any vendors here. We're simply relating a positive experience we had with JLCPCB for informational purposes.

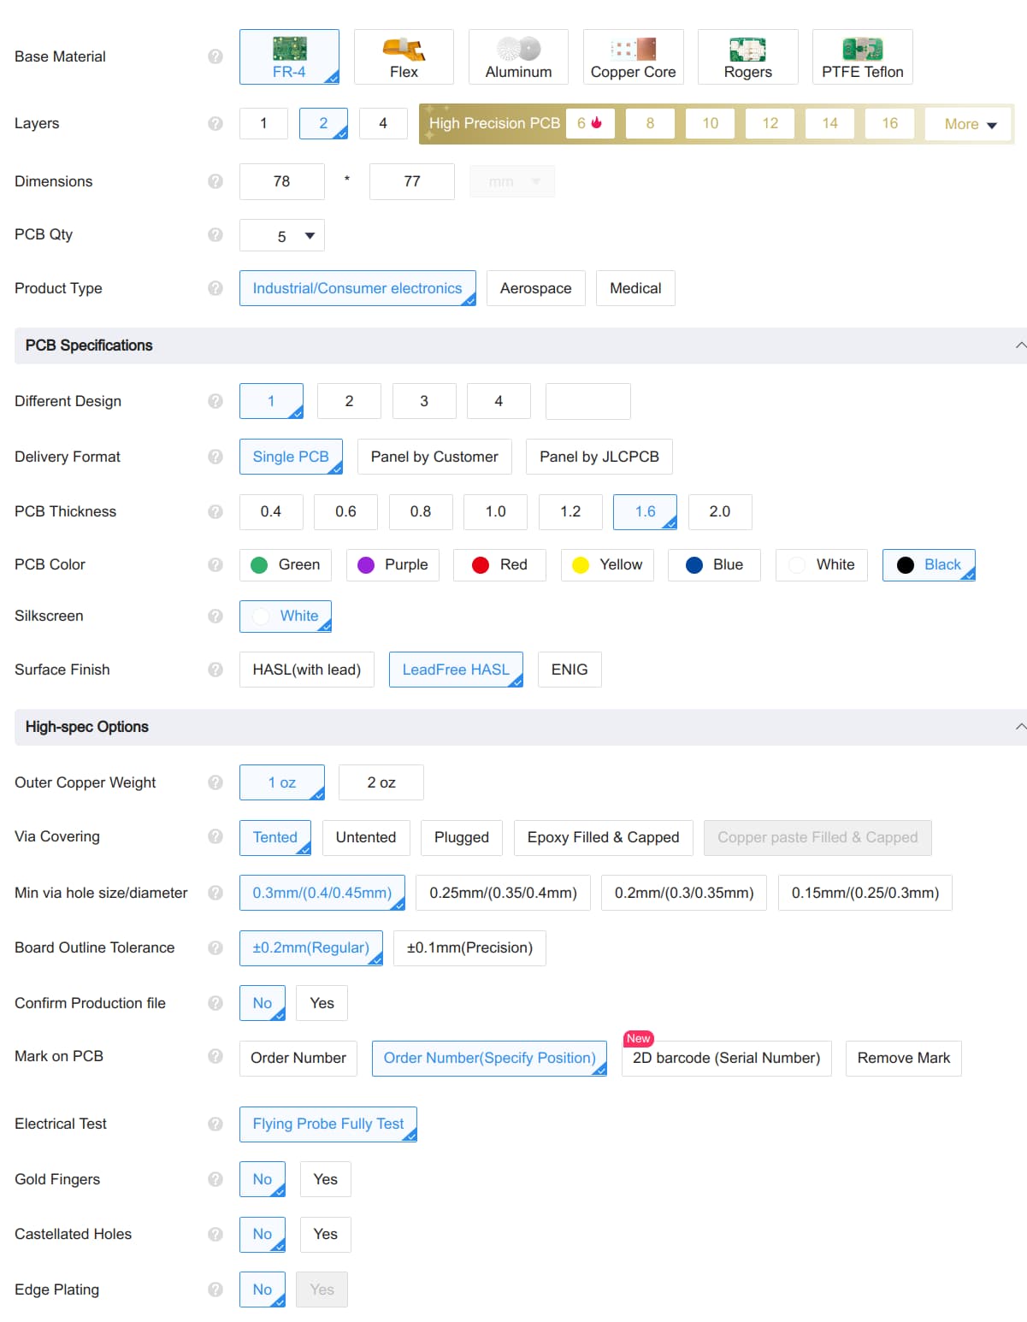
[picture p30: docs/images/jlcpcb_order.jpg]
Our usual order from JLCPCB. 2-layer FR-4 board, 1.6mm thick, black, LeadFree HASL surface finish, 1 oz outer copper weight, tented vias, and Order Number (Specify Position) with other settings the default


## Populating the PCB

Once you've gotten a PCB of your own, you'll need to populate it with parts. See the [Bill of Materials](./hardware/BOM.md) for more info. But in short, you will need the following parts.

- 2x8 Female Dupont Header Pins
- 1x4 Female Dupont Header Pins (x3)
- 1x6 Female Dupont Header Pins
- 1x19 Female Dupont Header Pins (x2)
- 1K Resistor (x2)
- Passive Piezo Buzzer
- S8050 Transistor
- Screw Terminals (5mm pitch)
- Barrier Terminal Block (1x2, 7.62mm)
- Barrel Jack (rated for at least 5A)

When completed, it should look a little something like this. Please disregard the sketchy solder joints in a few places.

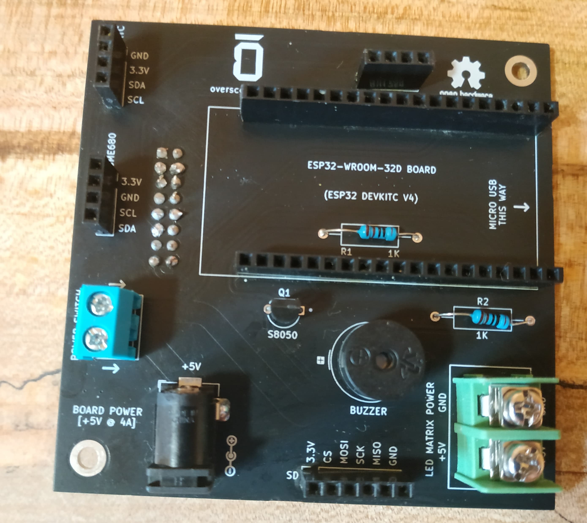
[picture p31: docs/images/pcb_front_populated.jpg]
Front of the populated PCB. Most of the header blocks, the two resistors, the transistor, the buzzer, the screw terminals, the barrier terminal block, and the barrel jack are on this side of the board


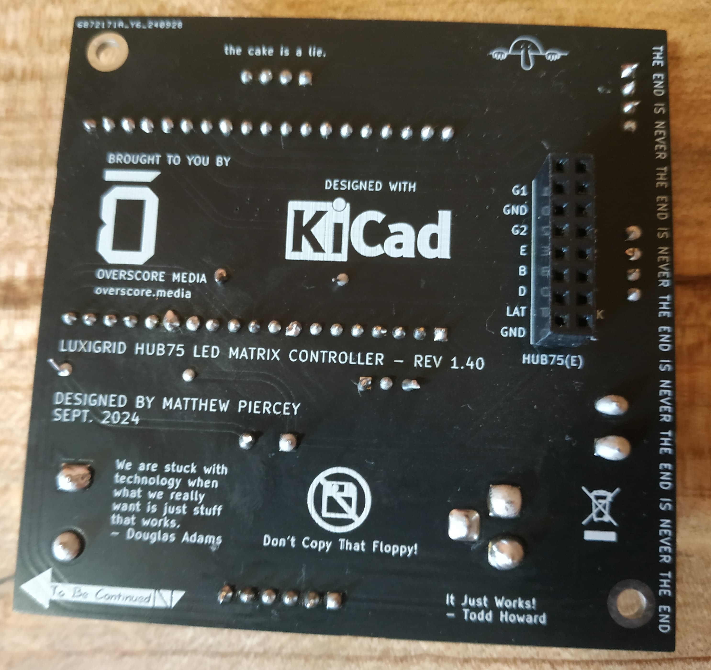
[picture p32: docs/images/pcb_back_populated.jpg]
Back of the populated PCB. The only part sticking out past the solder joints on the bottom is the 2x8 female header block for the LED matrix


We recommend cross-referencing these photos to see if you're installing everything correctly. The white silkscreen text/outlines should also be helpful. Especially take note of the orientation of the transistor, with the flat side facing the long header pins for the ESP32, the "+" on the buzzer lining up with the little plus sign on the board, the terminal barrier block (green) within the white outline, and the screw terminals (teal) oriented inwards. Although the last one isn't that big of a deal, just be consistent. We just found it slightly more convenient to have it facing inwards.

You should probably solder the 2x8 connector for the LED matrix before putting the other headers and screw terminals nearby. Otherwise, as shown in the picture, it can get tricky to solder it last. Although it can be done.

You will want side cutters, or big scissors to snip off the leads of parts like the resistors and transistor before soldering them. Otherwise they'll be too long. See the picture of the backside of the board - they shouldn't be protruding that much.

The buzzer may need to have its pins carefully bent in order for it to fit. It shouldn't be an issue, as long as you orient the plus sign correctly.

For the header pins, try soldering one pin first, then make sure the block is lined up. Then do the opposite pin, and make sure the block is straight. You may have a chance to heat the solder up and tweak the position if necessary. Also, try to ensure the block is completely seated against the surface of the PCB. You shouldn't be able to see the brass pins between the plastic block and the PCB surface. Once the start and end pins have been soldered, you can solder the pins in the middle of the block. That usually works.

For the barrier terminal block, we recommend slightly loosening the screws before soldering it onto the PCB. Otherwise, they may move around a bit when initially loosening the screws, which is probably not ideal.

And for all these parts, don't forget a generous coating of flux. Regular rosin flux works pretty well, in our experience. It can leave a bit of a mess on the board when you're done. But a careful scrub with a toothbrush dipped in 99% isopropanol/rubbing alcohol can usually get it all off. Just don't brush your teeth with it afterwards! 😂 The alcohol may leave a slight white film on the surface of the PCB when it evaporates. As long as you got the worst of the flux off the board, that's probably not a big deal. It's hard to see with a black PCB, anyway. Just make sure you let the board thoroughly dry after cleaning, and before hooking it up.

## Printing the Parts

As mentioned above, the [3D Printing Documentation](./hardware/3D.md) goes into more detail on the 3D printed parts you'll need to assemble the Luxigrid enclosure, and how to print them properly. It's not the easiest process, but we've tried to make it as repeatable and dependable as possible. You may want to print some test parts to experiment with the fit of everything, first.

We would also recommend getting used to the process of inserting heated inserts into a plastic part. You will need four M3 inserts in each of the two matrix diffusers, as well as two M4 inserts into the right backplane. Read more about the specific parts/tools you'll need in the [Bill of Materials](./hardware/BOM.md).

To reiterate, you will need roughly 400g of 3D printer filament and 21 hours of printing time to complete the parts for a Luxigrid enclosure. You will also need to be able to do per-layer colour changes, since the matrix diffusers require specific layers of white and black plastic in order to function.

But once you have a populated PCB, the 3D-printed parts, and the required fasteners, there are just a couple more matters of business before we can put this whole thing together

## Prepping the Parts

The two last main preparation steps are getting the power switch ready, and installing the heated inserts in the 3D printed parts that require them.

You may also want to install a mesh to cover the "vents" or windows on the back of the enclosure. It's an optional step, but it can help prevent dust build-up inside the enclosure, and it looks pretty neat.

Anyway, for the power switch, you'll want to solder a few centimetres of 18 AWG wire to it. Cut two equal pieces as long as you think you'll need (see the picture below), strip both ends of both pieces, and tin at least the ends that will be attached to the switch.

Be careful not to leave the soldering iron on the switch for too long at one time. Give the switch a chance to cool after connecting each wire. We recommend dabbing the contacts of the switch with some flux, applying a decent amount of solder to the contacts, then carefully attaching the tinned end of each piece of wire to each contact of the switch. Ensure there is a strong electrical and physical connection before continuing. An electrical continuity test between the ends of the wires should pass when the switch is on, but not when the switch is off.

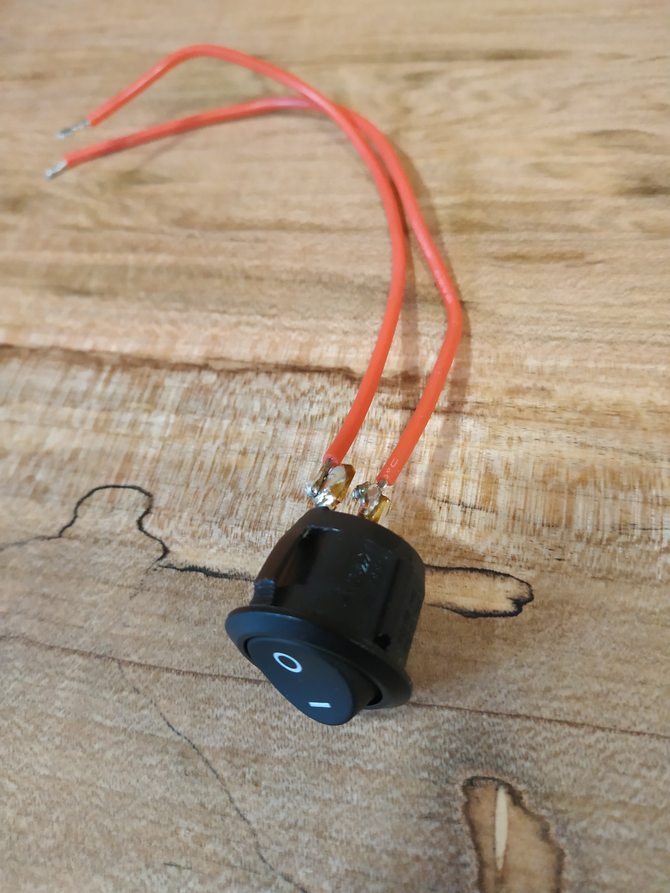
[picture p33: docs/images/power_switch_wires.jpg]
Two red 18 gauge wires are attached to the two contacts of the round rocker switch


For the heated inserts, it may take some practice to get the technique down pat. There are many good tutorials and practice models you can print to play around with them, though. This is more or less the result you're looking for:

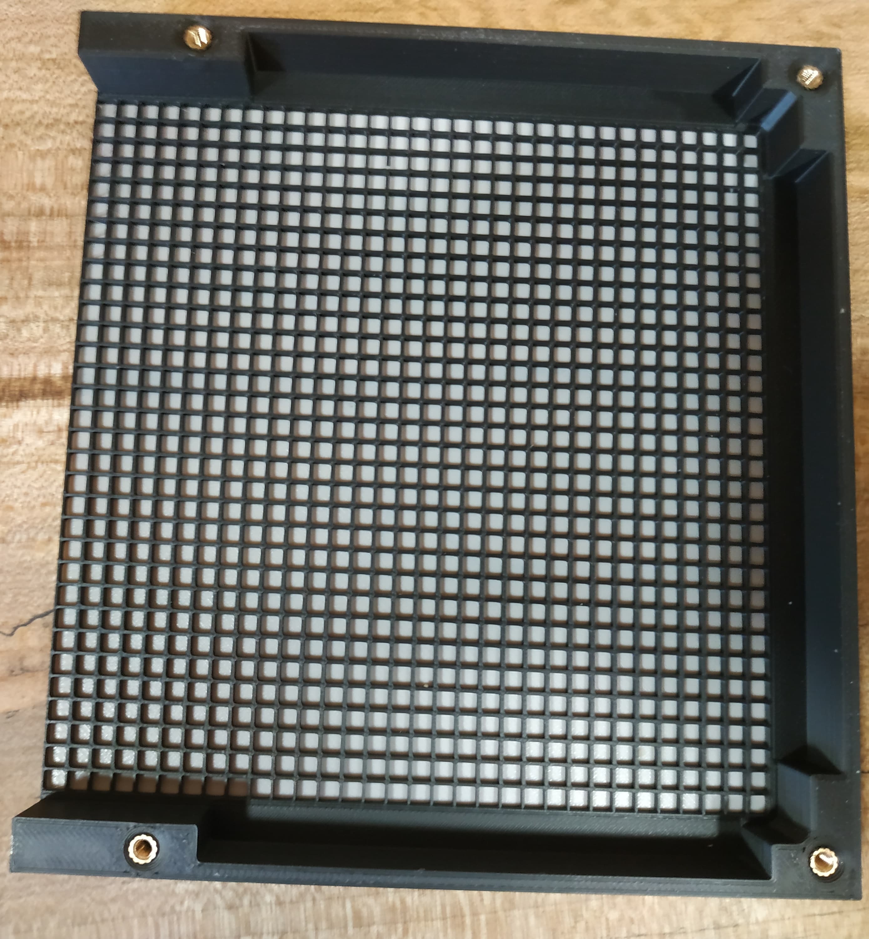
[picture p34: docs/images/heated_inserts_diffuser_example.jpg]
Brass heated inserts securely installed and properly aligned in the four holes of a matrix diffuser


Using a special heated insert tip on a soldering iron, at 490F tends to do the trick in our experience. You should just be able to set the insert skinny side down, apply a small amount of pressure via the soldering iron, and wait a few seconds for it to sink into the plastic. You shouldn't have to apply much force, you shouldn't come at it from an angle, and you shouldn't have to leave the iron on the insert for too long. Ideally, it'll just slide into place. Then slowly pull the iron out of the insert, and give the part ample time to cool before moving on. If you get something like on the left of the picture below, that *may* work but it's not ideal. Ideally each insert should be centered in the hole, all the way down but not too far down, and secure without an empty ring around it.

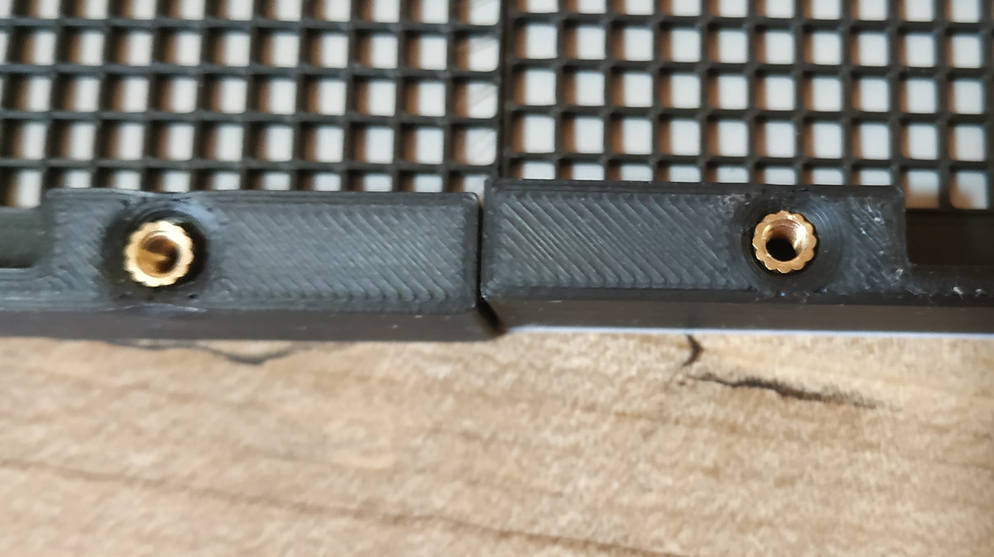
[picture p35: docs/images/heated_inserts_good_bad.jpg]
On the left, an insert is slightly misaligned, and a part of it is not connected to the plastic. On the right, an insert is properly centered and aligned with the hole, without a noticeable gap


Remember, the matrix diffusers take M3 inserts, and the right backplane takes M4 inserts. And for the right backplane, you may want to install the middle insert from the back. But it's up to you.

Now, if you want to install a mesh over the holes in the back of the enclosure, now's the time to do that. It's your call how to get it done, but we recommend printing four of the optional mesh holders, gluing a rectangular piece of mesh to each, then gluing the mesh and holder to the back of the backplanes. Use the alignment guides printed into the backplanes to help you get them in the right spots. Hot glue works pretty well for this. As you can see, there are multiple ways to do this, and it doesn't matter if the inside looks a little messy.

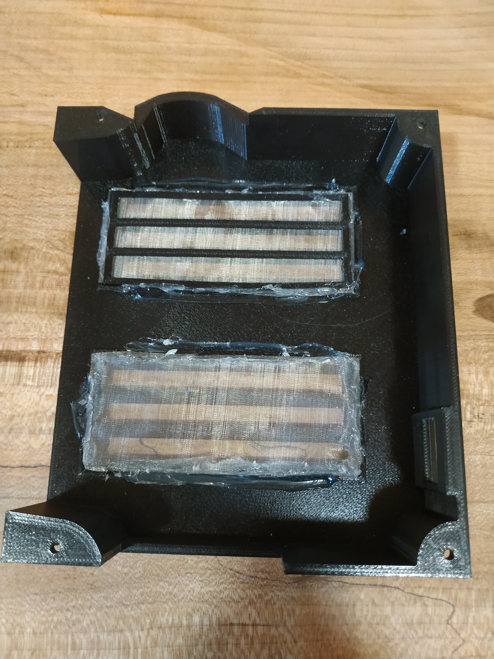
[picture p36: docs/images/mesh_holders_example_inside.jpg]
The inside of a backplane, with two examples of how to glue a piece of mesh to it


See? Looks good, doesn't it?

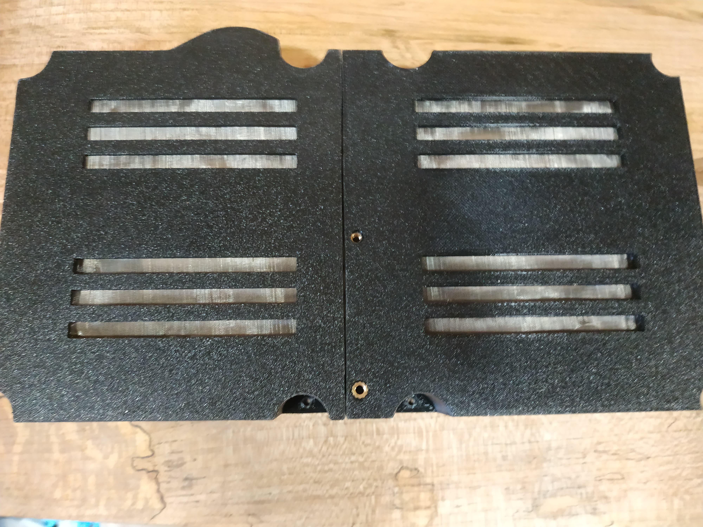
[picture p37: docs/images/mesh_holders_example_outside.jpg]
The outside of a backplane, with mesh neatly covering the rectangular ventilation cut-outs


## Putting it all Together

Before continuing, sure you have already flashed some firmware to the ESP32. Ideally an app like **Maze**, that can help you test out and troubleshoot the LED matrix. See the [Development Instructions](./DEVELOPING.md) for more information.

With that out of the way, let's get to the bottom of this, shall we?

First, install the power switch in the left backplane. There is a small lip on the edge of the switch that should help you align it with the hole. Make sure it's looking something like this. Pay attention to which way the switch should be mounted.

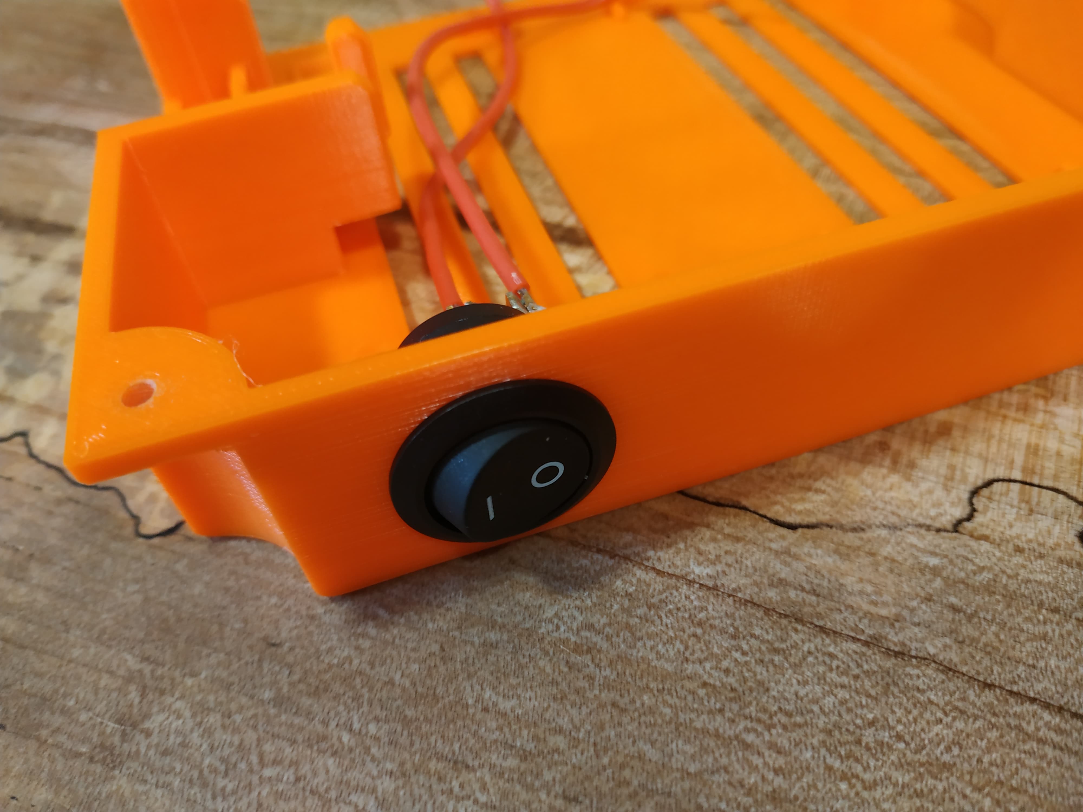
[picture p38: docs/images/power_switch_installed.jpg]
With the left backplane face down, the rocker switch is installed with the "-" or "ON" marking facing to the bottom, and the "O" or "OFF" marking facing to the top


Next, carefully pop the ESP32 board into the Luxigrid PCB. Make sure all 19 pins on both sides line up, and that the board's Micro USB port is pointing in the direction marked on the silkscreen of the PCB.

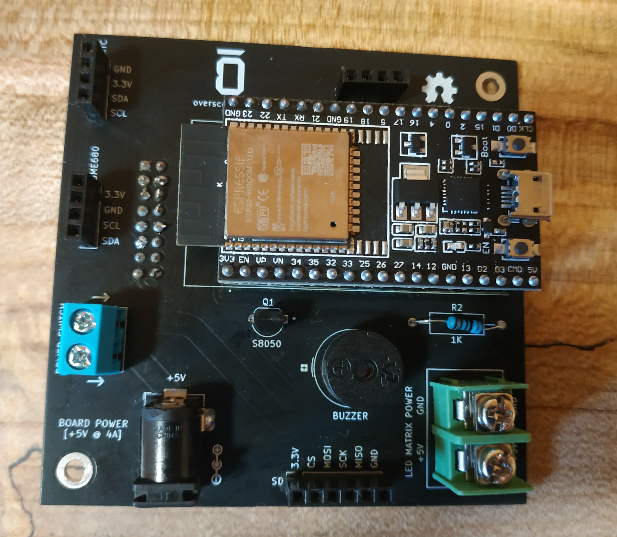
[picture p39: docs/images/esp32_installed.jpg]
The ESP32 board is installed into the Luxigrid PCB, with the Micro USB port facing the right edge of the board


Now, attach the right bracket to the LED matrix with 2 M3 x 10mm screws. Try to note the orientation of the screen. It's not 100% symmetrical. Yours may look slightly different, but generally the "up" arrows on the top-left corner should be pointing up. And generally the side with the power cable is the side to put the right bracket on.

Note the orientation, and also note we're only using 2 screws on the right side for now. Finally, make sure the LED matrix's power cable (most of them come with one) is properly installed. You may want to put some electrical tape around the contacts of the other part of the cable, since many cables are meant to power two panels. And it's probably best to not have exposed contacts kicking around. You could also remove the other connector and splice the cable yourself, but it's not really recommended when you can just spool it up and keep it inside.

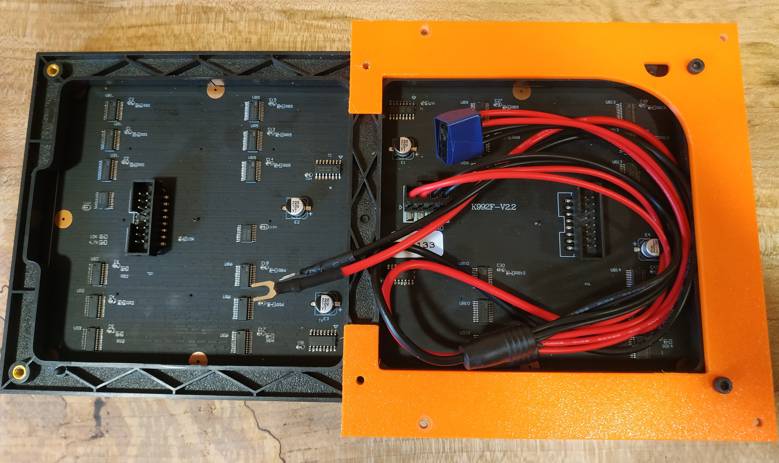
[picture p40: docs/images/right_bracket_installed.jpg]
The right bracket is installed on the right side of the LED matrix, with two screws on the right side and no screws in the middle yet. The LED matrix's power cable is spooled up inside the cut-out in the back of the display


Now, take the left bracket, and attach the BH1750 sensor board to it, with 2 M2.5 x 8mm screws. Note the orientation of the sensor and screws.

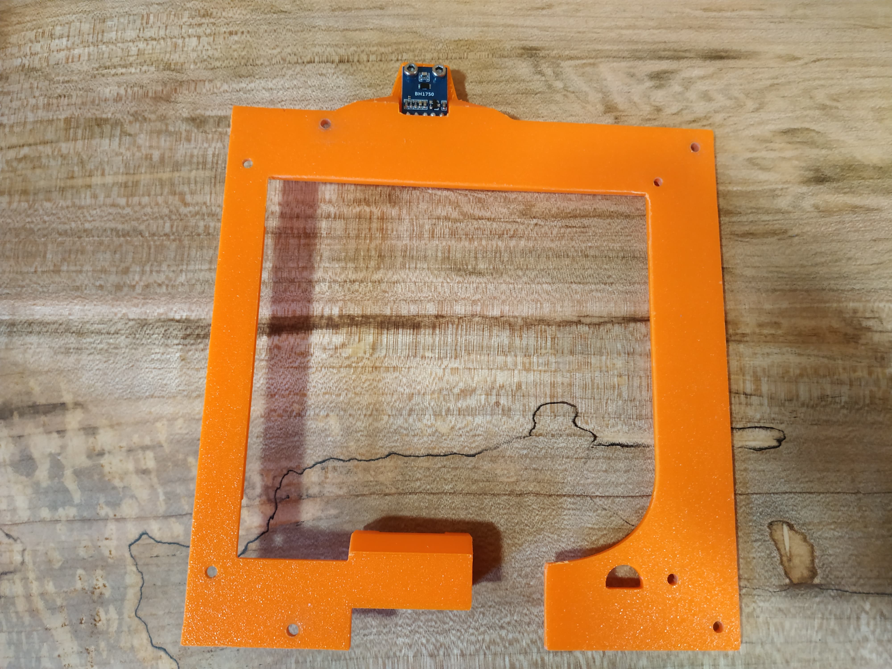
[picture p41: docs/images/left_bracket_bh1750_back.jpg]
From the back, the Bh1750 sensor is visible in its cut-out, with two screws going downwards


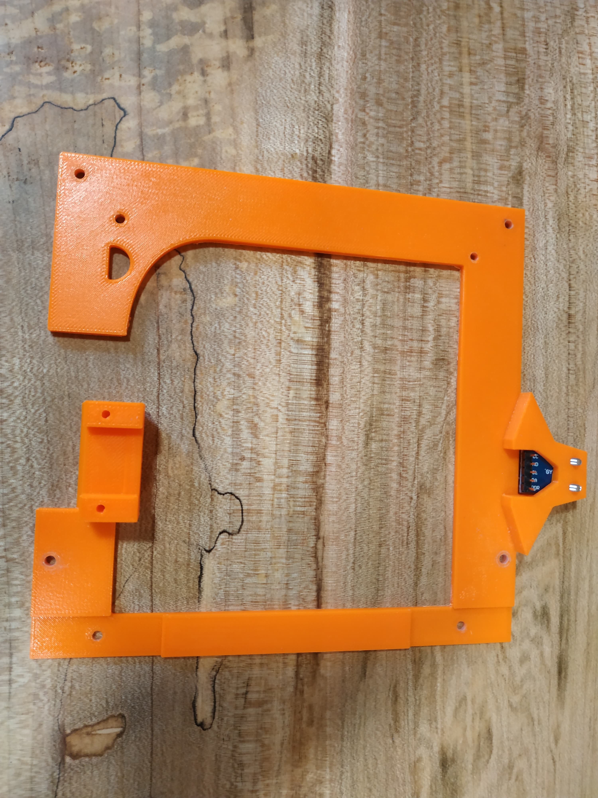
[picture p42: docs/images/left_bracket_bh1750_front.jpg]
From the front, the pins of the Bh1750 are sticking out, as is the extrusion for the SD card holder on the opposite side of the left bracket. The screws on the BH1750 are facing up


Next, install the left PCB bracket, right PCB bracket, and left bracket onto the LED matrix as shown. The left bracket should slip under the right bracket (hence the two screw holes we left in it earlier) and the BH1750 should be facing downwards. Use 4 M3 x 10mm screws to attach the left and right PCB brackets.

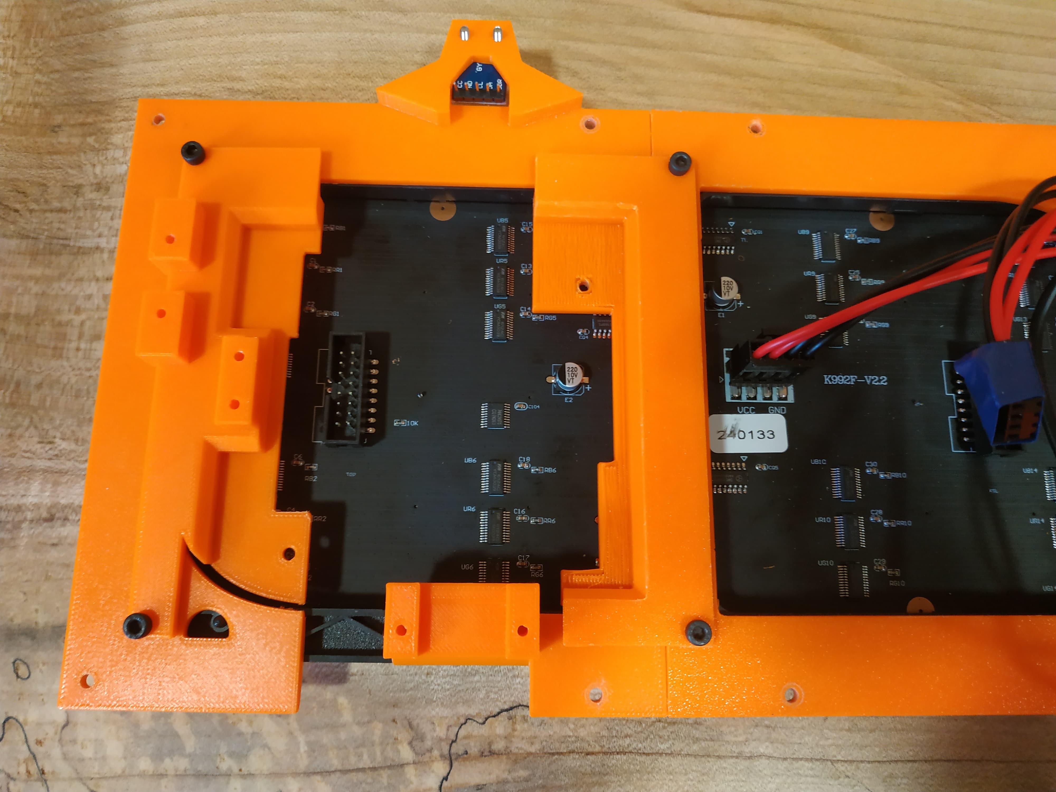
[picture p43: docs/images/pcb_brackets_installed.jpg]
The left and right PCB brackets are attached to the top of the left and right brackets, which in turn are connected to the LED matrix itself


It's time to install the PCB. With 2 M3 x 10mm screws, one in each corner of the board, connect it to the PCB brackets. Ensure the header pins on the bottom of the board align exactly with the pins on the LED matrix, and the screw holes in the PCB align with the screw holes in the PCB brackets.

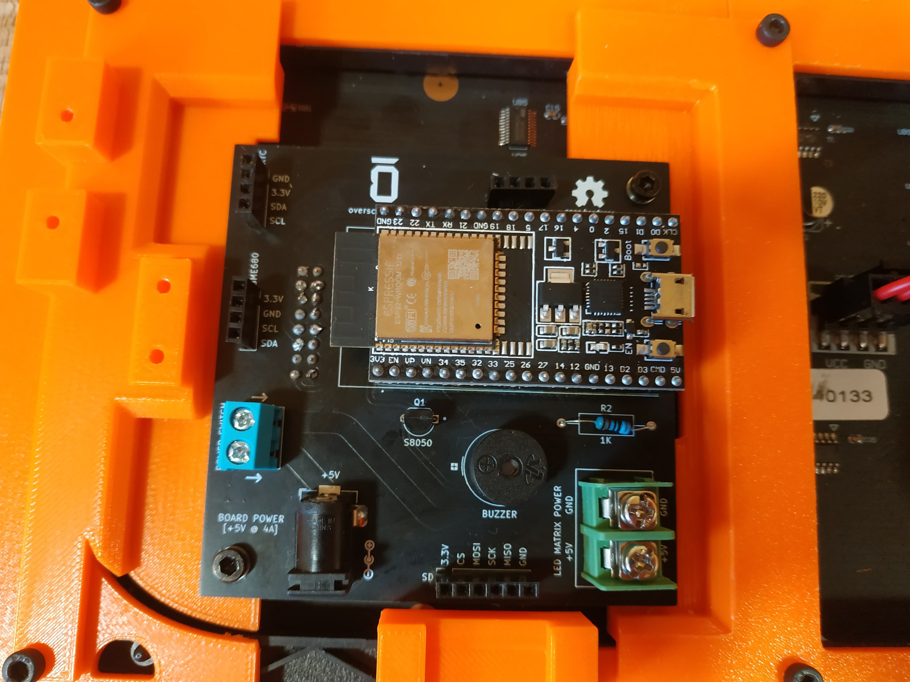
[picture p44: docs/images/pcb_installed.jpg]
The PCB is attached squarely between the PCB brackets, with a screw in each corner


Once that's done, connect the Micro SD card module. Make sure it faces the outside of the enclosure, and the pins line up. Carefully push it into place.

You will also want to install the RTC and BME680 at this time. Ensure the pin names line up (VCC on the RTC and BME680 correspond to 3.3V on the PCB, and SDO/CS are unused on the BME680). For the RTC and BME680, you may want to use one or two M2.5 x 8mm screws to ensure they do not fall out.

You may want to pre-screw the screws into the RTC and BME680 boards, before attaching them to the PCB. Otherwise it might flex the pin headers too much, as it can take quite a bit of force to screw into the boards. And remember, you're screwing into plastic here. Don't go too tight. Try to ensure the pins of the modules are lining up with the pin headers on the PCB, and the screws aren't so loose as to fall out. Otherwise they don't need to be too tight.

Finally, attach the LED matrix's power connectors to the PCB. **Pay very close attention to this step, and don't rush!**

### Remember: Red goes to +5V, and Black goes to GND

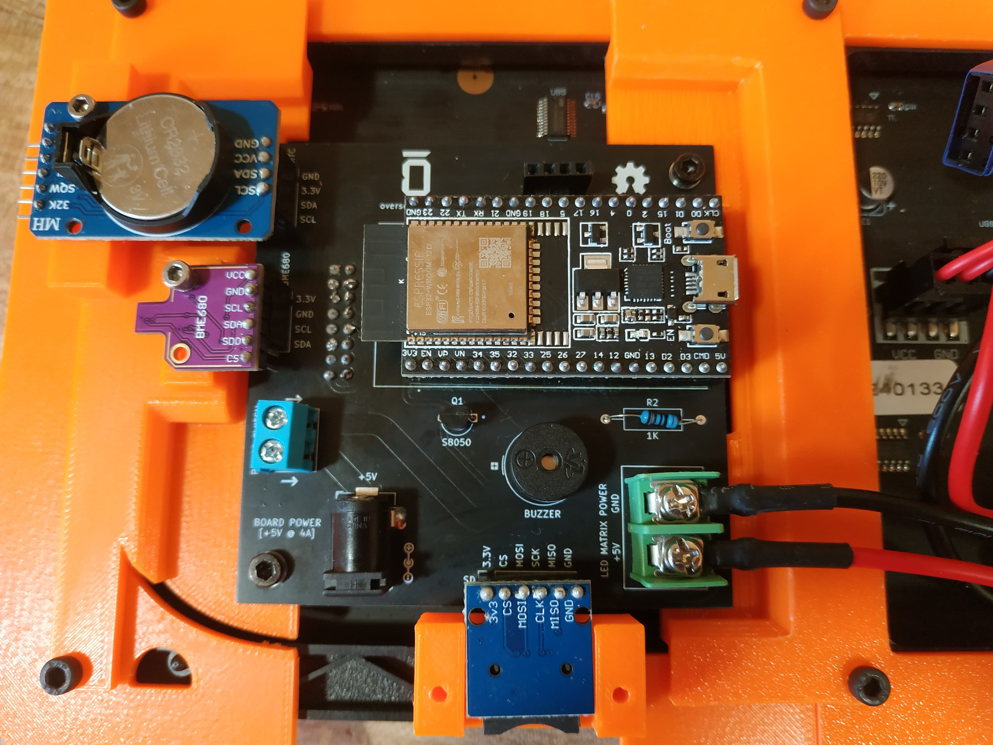
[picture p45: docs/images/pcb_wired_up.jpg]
The RTC, BME680, Micro SD card module, and matrix power connectors have been attached to the PCB


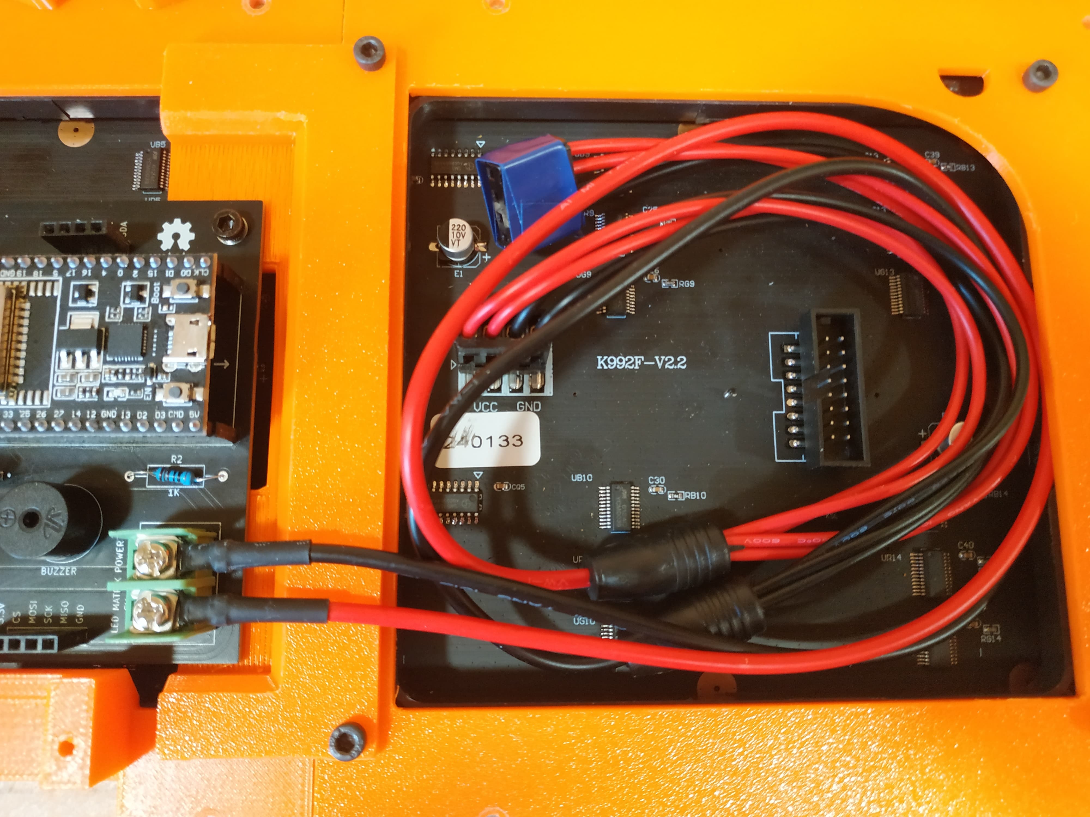
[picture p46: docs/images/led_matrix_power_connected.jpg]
A closer look at the LED matrix power connector. Black goes to the top of the barrier terminal block, GND, and GND on the LED matrix. Red goes to the bottom of the barrier terminal block, +5V, and VCC on the LED matrix


This is assuming, of course, that your power connector has the proper colouring. At any rate, the +5V on the PCB's barrier terminal block should be connected to "+" or "VCC" on the LED matrix. And the GND on the PCB's barrier terminal block should be connected to "-" or "GND" on the LED matrix. If you're 100% certain that's the case, you can move on.

Take the SD card "hat", and install it over the Micro SD card module, onto the left bracket. Use two M2.5 x 8mm screws. The Micro SD card module may still be able to move a bit after this, but it shouldn't fall out or become disconnected.

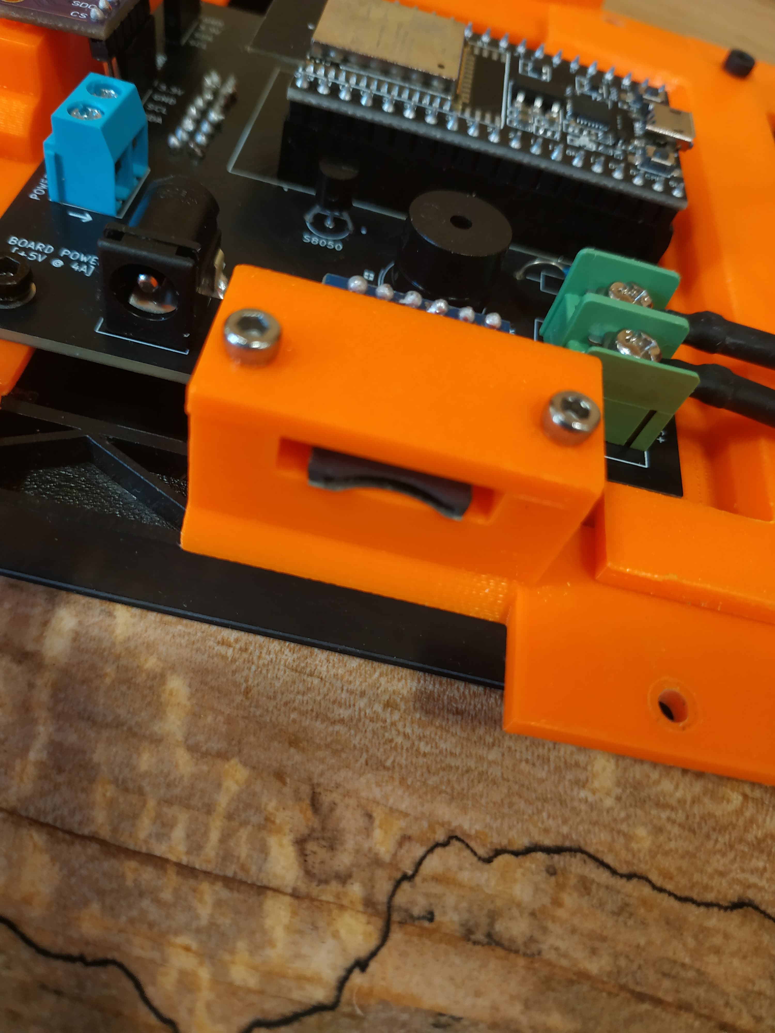
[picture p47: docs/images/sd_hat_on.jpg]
The SD card "hat", a rectangular piece of plastic that sits on top of the Micro SD card module, attached with two screws


With a Philips screwdriver, loosen the screws from the screw terminals all the way to the top. Then with the power switch and left backplane sitting beside it, carefully connect each of the power switch wires to the screw terminals, and screw them down one at a time. Be very careful to ensure the wires are securely attached, and not at risk of touching each other's uninsulated metal before continuing. Remember, **the full power of the LED matrix will go through the screw terminals!** So don't rush this part, either.

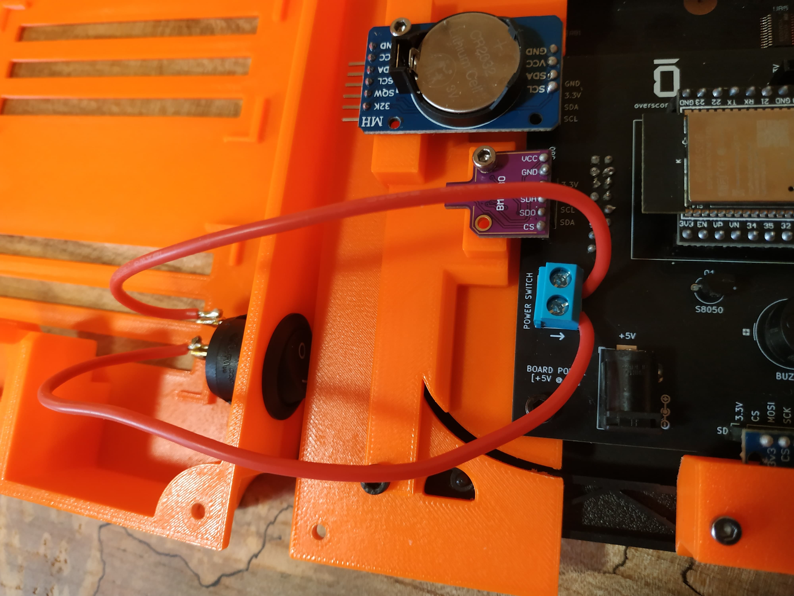
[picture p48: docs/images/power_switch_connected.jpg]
The two wires from the power switch are connected via the screw terminals to the PCB


With four female-to-male Dupont jumper wires, connect the BH1750 to the PCB as follows. VCC to 3.3V, GND to GND, SCL to SCL, and SDA to SDA. ADDR on the BH1750 remains disconnected. Colour coding is not required, but super handy.

Ensure each of the wires is sitting snugly in the connector before continuing

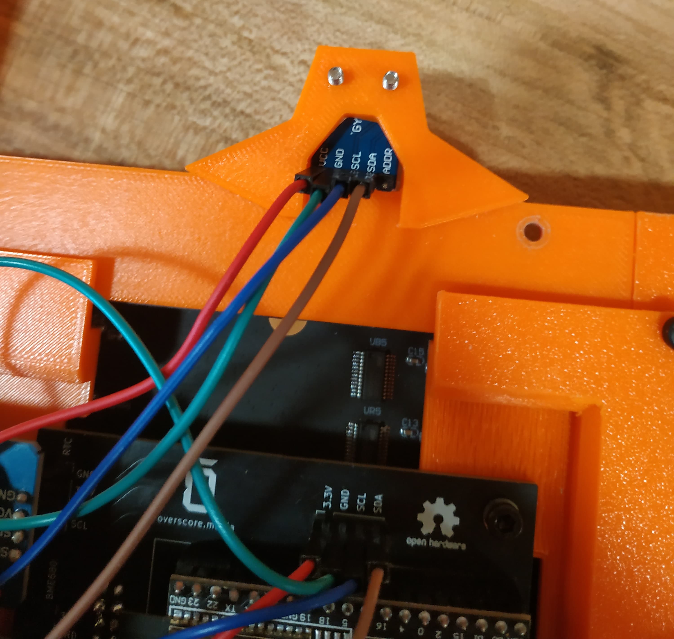
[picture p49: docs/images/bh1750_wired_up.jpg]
Four coloured wires connect the BH1750 to the PCB


We're almost done! Take one of the matrix diffusers, and place it under the front of the LED matrix, on the left side. Then, very carefully close the left backplane. Do your best to manage the cables from the power switch and BH1750. It doesn't have to look pretty, so long as nothing's stuck, and no wires are disconnected or touching where they shouldn't be. Then with 4 M3 x 10mm screws, carefully join the left backplane, the left bracket, and one of the matrix diffusers. **Don't screw too tightly into the diffuser** - all threaded inserts have a breaking point with too much torque. Just make sure it's all secure, and there are no visible gaps between the parts.

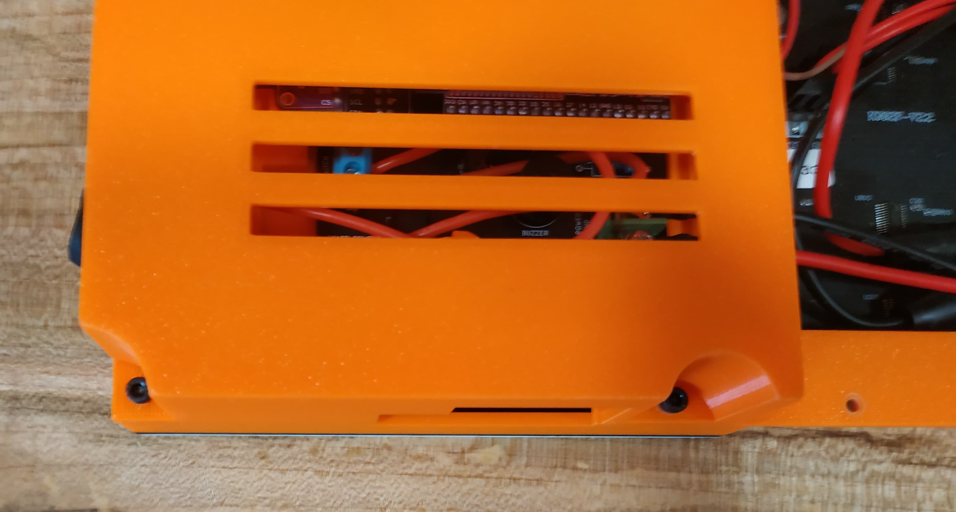
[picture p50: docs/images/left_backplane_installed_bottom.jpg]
The bottom of the left backplane, showing it covering the PCB. It is attached with two screws here, and two above (not shown here)


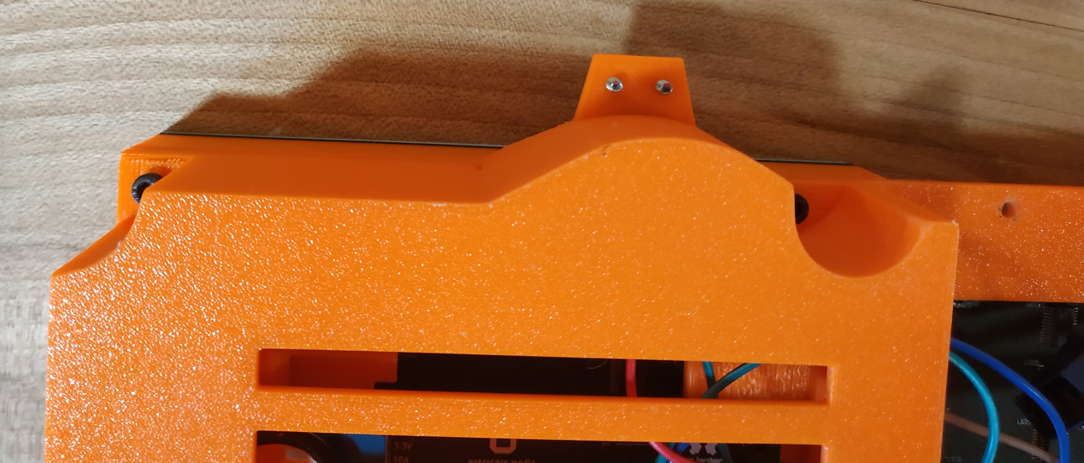
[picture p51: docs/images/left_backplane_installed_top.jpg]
The top of the left backplane, attached with two screws here, in addition to the two on the bottom of the backplane


Take this opportunity to flip it over and examine your handiwork. Looking pretty good, huh?

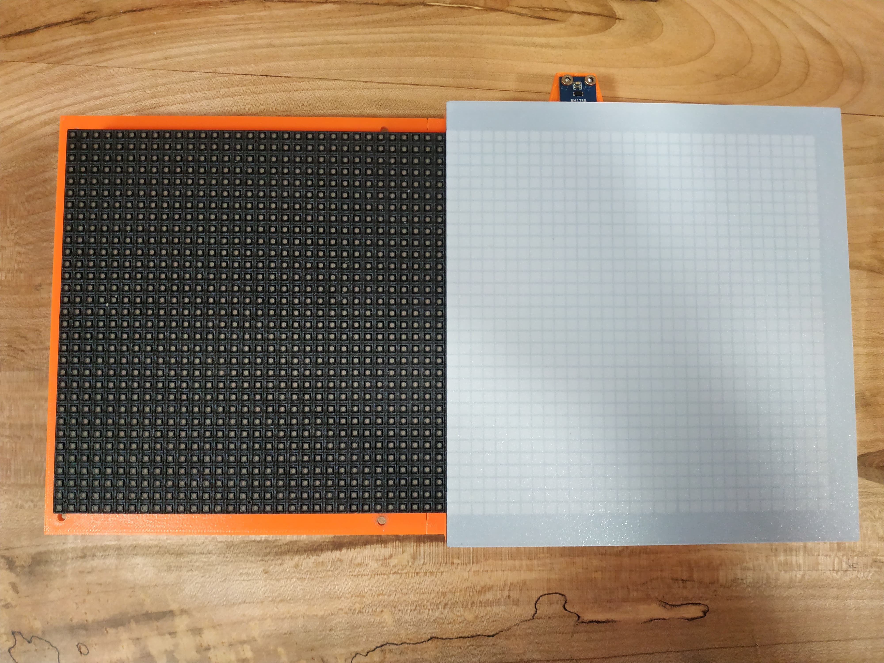
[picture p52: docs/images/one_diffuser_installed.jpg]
One of the matrix diffusers has been installed, leaving one to go


Now, it's at this point you could probably go crazy trying to perfect this. But it's not hard to get a *decent* result. You just have to manage your expectations. In case you haven't realized by now, this is the difference between a diffuser with a lip and one without a lip:

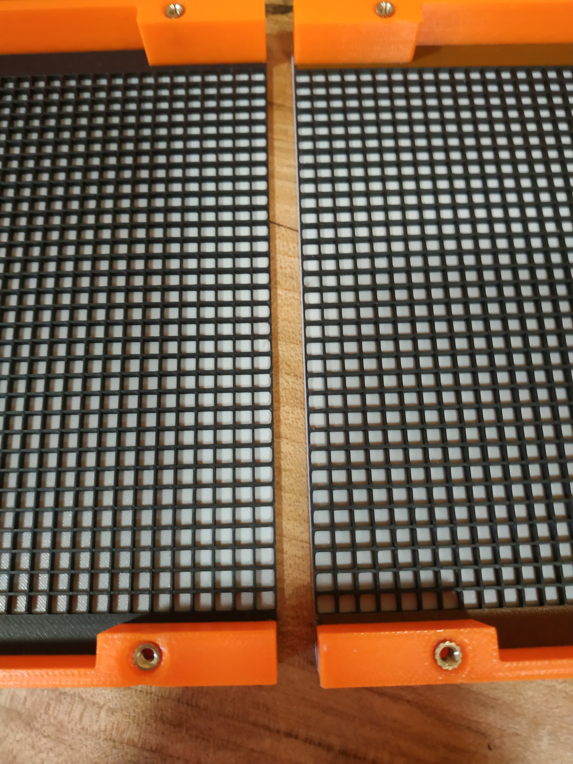
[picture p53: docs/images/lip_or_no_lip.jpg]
The diffuser on the right has a 0.5mm extra strip of white plastic on the first layer


It may be hard to see, but that little white line on the edge of the right one - that's the lip. It's 0.5mm.

Is this really necessary? Well, not strictly. You could forego the lip and enjoy your Luxigrid just fine. But if you want to try to eliminate the "seam" between the two panels, that's what it's for. Ideally, this is what it should look like, with as unobtrusive a seam as possible.

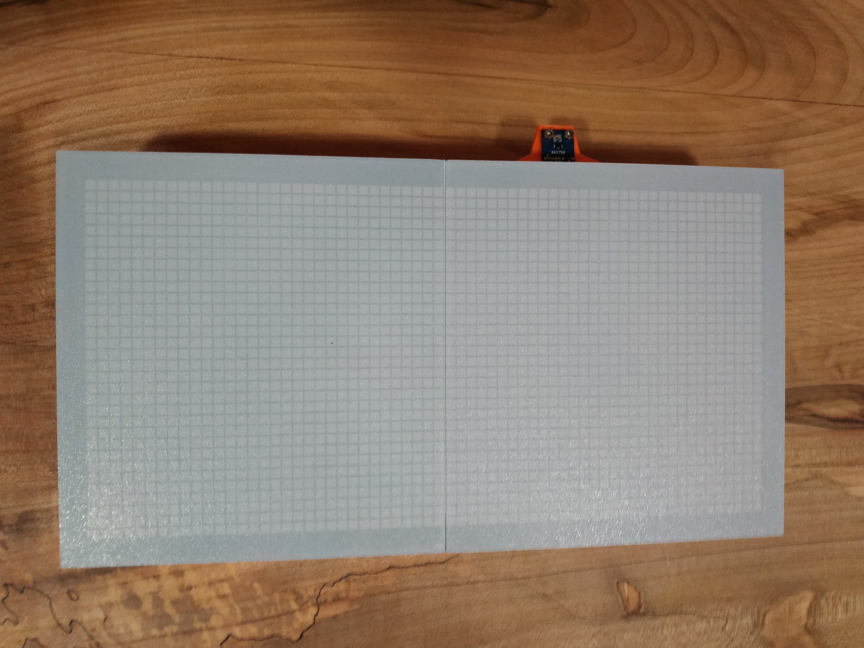
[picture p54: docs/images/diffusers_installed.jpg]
Two diffuser panels connected, with a barely visible seam between them


It's your call whether you care about the seam or not, but if you do, just be careful not to get discouraged by diminishing returns. Because as long as you've followed the rest of the directions, your Luxigrid will be 100% functional, and have access to the full ecosystem of apps - even if there's a bit of a seam between the panels, or a few of the pixels are a bit off. See the notes at the bottom of this document if you're dealing with diffuser issues, but try not to let them get to you.

Because you're *so close!* If you want to skip ahead to the "Powering it On" section, now might be a good time to do that. The last major step is installing the desk mount, but you can do that after testing your Luxigrid.

Anyway, once you're sure that your Luxigrid works, and you're ready to move on, let's install the desk mount.

Take the desk mount bracket, and attach it to the right backplane with two M4 x 12mm screws. Remember, you're screwing into the heated inserts in the right backplane.

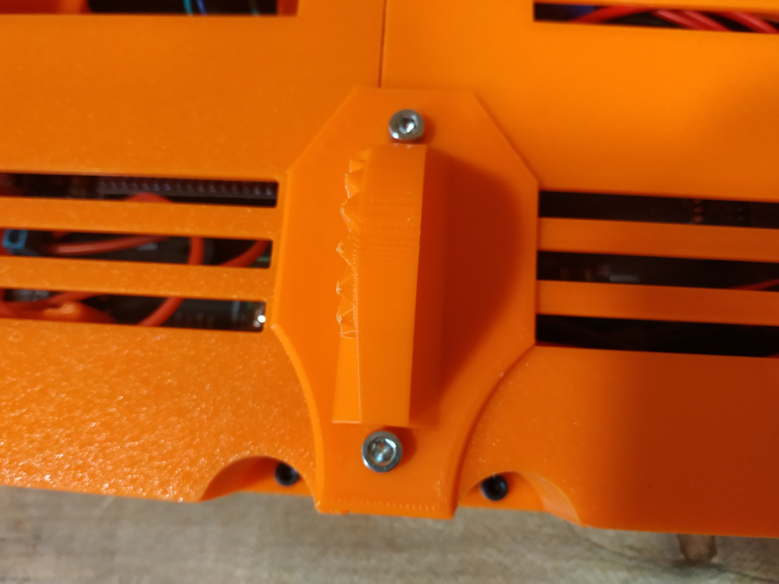
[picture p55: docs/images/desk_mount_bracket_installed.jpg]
The desk mount bracket is attached to the right backplane with two M4 screws. The side with tapers goes towards the bottom, and the side with straight lines goes towards the top


Once that's set, get an M4 x 30mm screw and an M4 nut ready. Before installing the screw and nut, ensure that the teeth on the desk mount bracket line up with the teeth on the desk mount. It may take a bit of fiddling, but they should mesh together eventually. Just make sure the desk mount is at the angle you want it to be. Ideally 90 degrees with the back of the enclosure, unless you want your Luxigrid pointing up or down.

Once you're satisfied with the position, insert the M4 screw from the left, and use it to connect the desk mount and desk mount bracket. Then slip the M4 nut onto the screw by hand. Carefully hold the nut in place while you tighten the screw. **Be careful not to over-tighten the screw.** You run the risk of cracking the plastic if you over-tighten the screw. But you don't need it super tight, you just need to stop the joint from moving on its own, and ensure the M4 nut is inside the cut-out in the desk mount. Here's what it should look like:

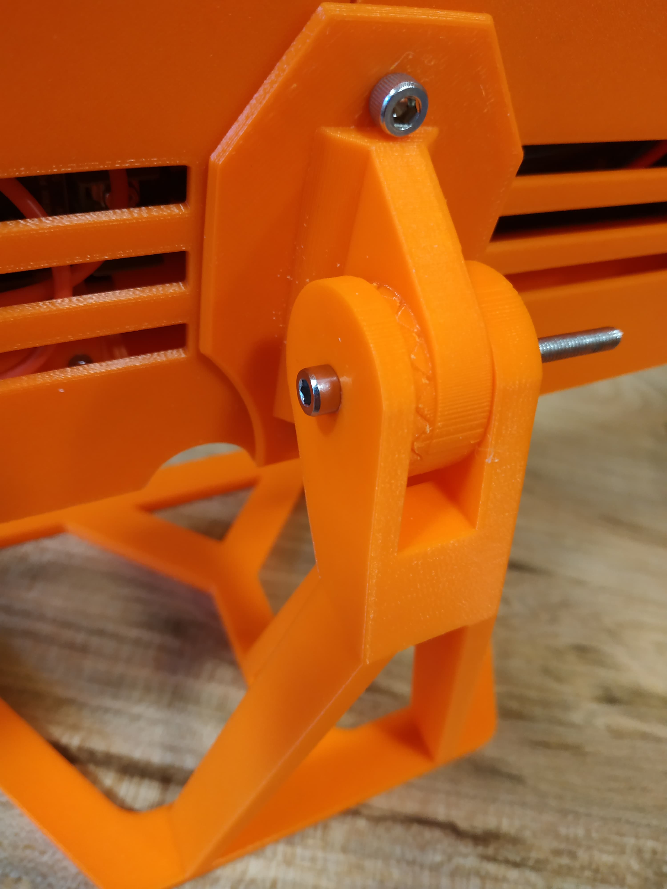
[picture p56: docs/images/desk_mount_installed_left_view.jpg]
The desk mount bracket is snugly attached to the desk mount, with an M4 screw running through the middle of the joint


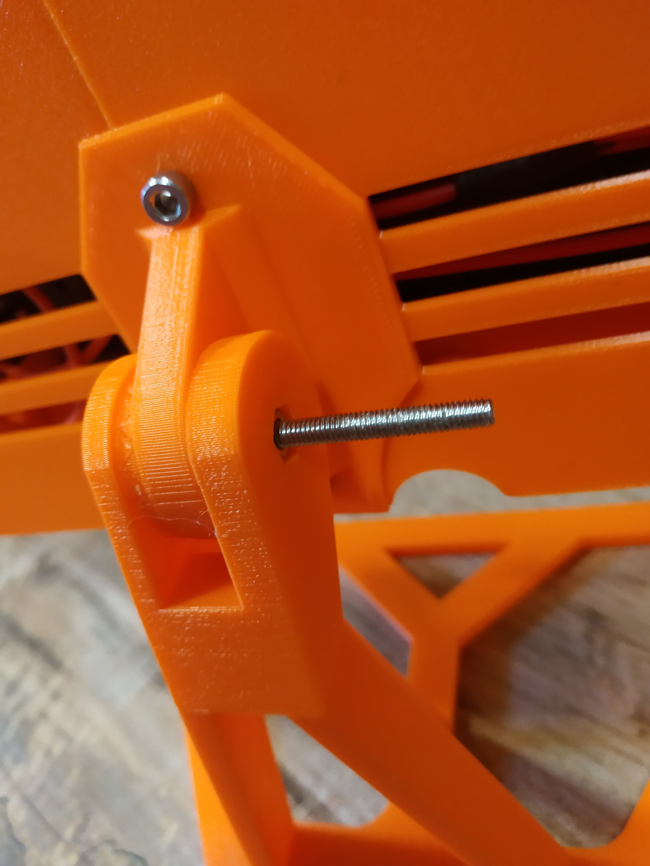
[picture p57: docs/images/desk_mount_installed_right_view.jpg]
On the opposite side of the desk mount, the M4 nut is securely in its little mounting hole, and the M4 screw is sticking out of it


## Powering it On

*Exercise caution with this step. Powering anything you just built always has its risks.*

Once everything is together, and you're feeling adventurous, plug your power supply into the wall. Then, plug the barrel plug into the jack on your Luxigrid. Make sure the power switch is currently off. Finally, with the LED matrix facing towards you, turn the power switch on.

If all goes well, it should light up and display the Luxigrid logo, before connecting to WiFi and showing its IP address.

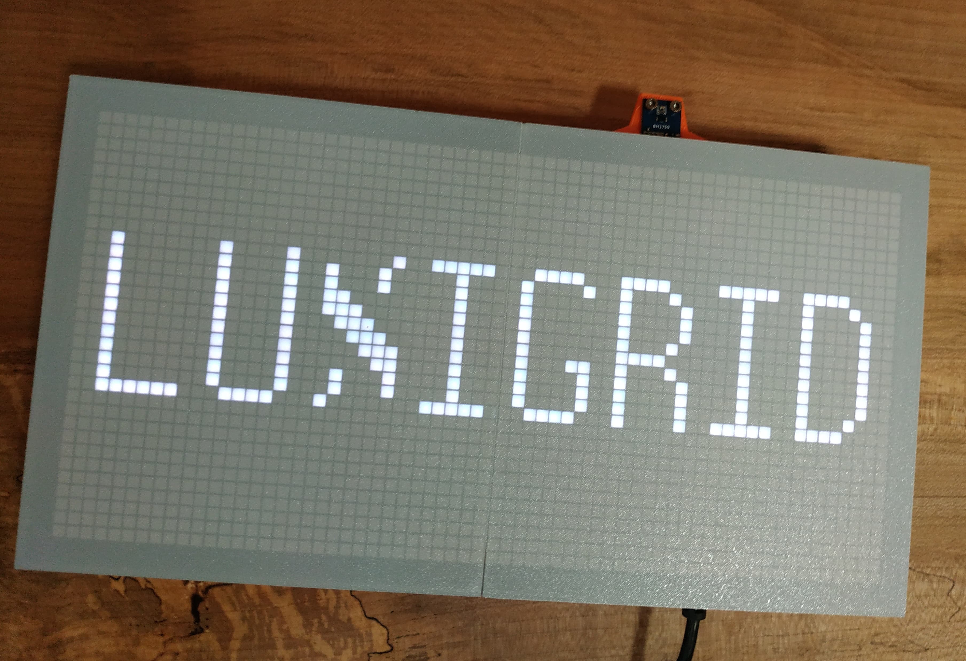
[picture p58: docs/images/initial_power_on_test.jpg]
The Luxigrid logo is being displayed on the LED matrix, indicating a successful startup


*If you see or smell any smoke, hear a loud buzzing noise, see a blank or glitchy screen, or anything weird like that, something's definitely wrong. Turn it off immediately, and unplug it.*

If you see an error message on the screen, refer to the [Quick Start Guide](./QUICK_START_GUIDE.md) for common error troubleshooting. It may have an easy fix. As long as the screen is on and not glitching out, the hard part is probably over.

If you're getting ERROR 1100, you may just need to install the Micro SD card. It's probably best not to install it until you're confident that your Luxigrid is otherwise working properly. But once you're satisfied with it, you can turn it off and install the Micro SD card like this:

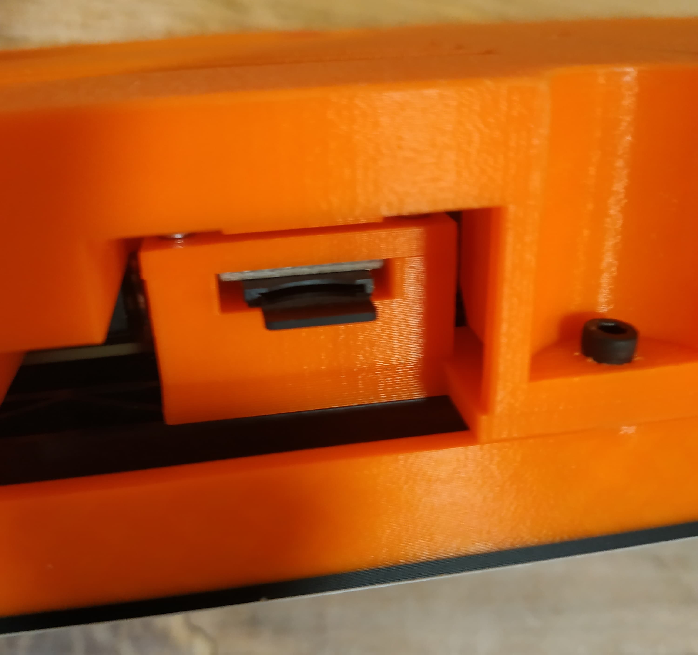
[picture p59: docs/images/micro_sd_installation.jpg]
The Micro SD card is installed in the module, with the back of the card facing upwards, towards the screws on the SD card "hat"


It only goes one way. The back of the card should be facing upwards, towards the screws on the SD card "hat" and towards the back of the enclosure. Don't force it. Make sure it's actually going into the reader module, and not just getting stuck in the plastic.

Anyway, to complete the initial test run, visit the IP address of your Luxigrid, from the WiFi network it has generated. From the web interface, you can tell it to connect to another WiFi network, configure other settings, or upload a new app onto it.

You'll also likely want to test the light sensor and automatic brightness functionality. Putting your hand over the light sensor, or turning off the lights in the room should make the brightness of the screen automatically adjust.

Finally, check if the matrix diffusers are properly aligned. It's up to you how far you want to take this step. But if you're going for pixel perfection, you may want to look into these tests. The **Maze** app is helpful for troubleshooting pixel perfection issues.

And just like that, you're done! Congratulations!



Anyway, thank you for following along. If you've made it this far, we salute you. Enjoy your shiny new Luxigrid!

Please let us know what you thought of the process - where improvements could be made, etc. Drop us a line on [our website](https://luxigrid.overscore.media), to share your thoughts. And feel free to use the @luxigrid hashtag to share your creation on social media. But most of all, keep making stuff!

## Pixel Perfection Perils

As promised above, here are some notes that may help in the troubleshooting process, if you're having issues with "leaking" pixels, or other issues related to the diffusers.

- If you see any light "leaking" out from between the two diffusers, they may not be close enough. Try unscrewing and repositioning them. The heated inserts may also be misaligned. You might be able to get away with reheating and adjusting their position, or you might have to reprint the offending diffuser.

- If there isn't enough light coming through the diffuser, even at full brightness, your white first layer may be too thick. 0.20mm is recommended.

- If the viewing angles of the matrix aren't great, you may need a less translucent first layer. While using translucent filament for the first layer can create a stunning "stained glass" look, the effect isn't so great if you aren't looking straight on. A white first layer has much better viewing angles.

- If light is "spilling out" of the grid cells (on all cells, not just some) your grid walls may not be thick enough. Or the filament you used may not be dark/opaque enough.

- If the grid walls are too high, the screen may appear very dim. Try using the provided `.3MF` files as a reference.

- If a black line/seam is visible between the matrixes...
  - It's up to personal preference whether this matters to you or not
  - You may not have printed one diffuser with a lip, and one without a lip
  - The heated inserts may be misaligned, or there may be something stopping the two diffusers from lining up properly

- If some pixels are "spilling out" near the middle of the screen
  - This is part of the diminishing returns of trying to fight the seam issue
  - You may have tightened the screws in the middle of the diffuser(s) too much, causing the middle of one/both of the diffusers to buckle
  - One diffuser may be caught on the other. Try different arrangements.
  - You may have to fidget a bit with the diffusers to get them to fit together without a seam AND pixel bleed near the middle.
  - You may decide to setting for either a visible seam or some minor pixel bleed near the middle, if nothing else seems to be working. Overall, that sort of thing is an inherent challenge of a DIY project like this.

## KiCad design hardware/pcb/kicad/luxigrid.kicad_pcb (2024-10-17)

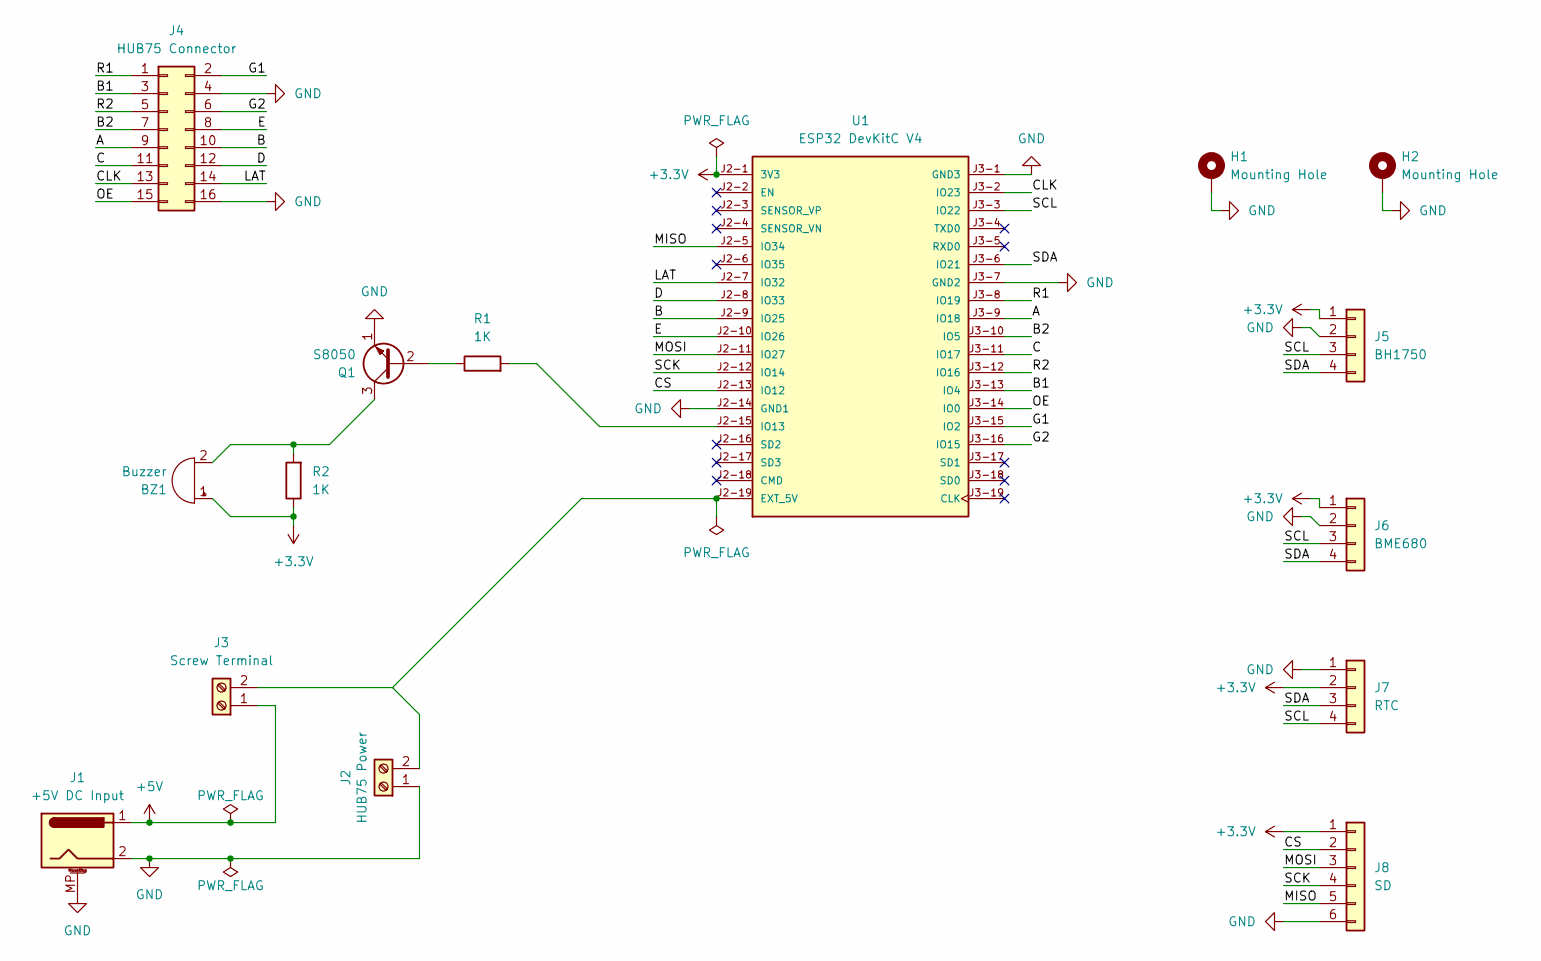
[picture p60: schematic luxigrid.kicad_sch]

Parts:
BZ1: Buzzer; Buzzer_TDK_PS1240P02BT_D12.2mm_H6.5mm
H1, H2: Mounting Hole; MountingHole_3.2mm_M3_ISO14580_Pad
J1: +5V DC Input; BarrelJack_Horizontal
J2: HUB75 Power; 7.62mm Barrier Block
J3: Screw Terminal; 5mm Screw Terminal Block
J4: HUB75 Connector; PinSocket_2x08_P2.54mm_Vertical
J5: BH1750; PinSocket_1x04_P2.54mm_Vertical
J6: BME680; PinSocket_1x04_P2.54mm_Vertical
J7: RTC; PinSocket_1x04_P2.54mm_Vertical
J8: SD; PinSocket_1x06_P2.54mm_Vertical
Q1: S8050; SS8050DTA Transistor
R1, R2: 1K; R_Axial_DIN0309_L9.0mm_D3.2mm_P15.24mm_Horizontal
U1: ESP32 DevKitC V4; PARTREV V4

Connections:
+3.3V: BZ1.1 (+), J5.1, J6.1, J7.2, J8.1, R2.1, U1.J2-1 (3V3)
+5V: J1.1, J3.1
/A: J4.9, U1.J3-9 (IO18)
/B: J4.10, U1.J2-9 (IO25)
/B1: J4.3, U1.J3-13 (IO4)
/B2: J4.7, U1.J3-10 (IO5)
/C: J4.11, U1.J3-11 (IO17)
/CLK: J4.13, U1.J3-2 (IO23)
/CS: J8.2, U1.J2-13 (IO12)
/D: J4.12, U1.J2-8 (IO33)
/E: J4.8, U1.J2-10 (IO26)
/G1: J4.2, U1.J3-15 (IO2)
/G2: J4.6, U1.J3-16 (IO15)
/LAT: J4.14, U1.J2-7 (IO32)
/MISO: J8.5, U1.J2-5 (IO34)
/MOSI: J8.3, U1.J2-11 (IO27)
/OE: J4.15, U1.J3-14 (IO0)
/R1: J4.1, U1.J3-8 (IO19)
/R2: J4.5, U1.J3-12 (IO16)
/SCK: J8.4, U1.J2-12 (IO14)
/SCL: J5.3, J6.3, J7.4, U1.J3-3 (IO22)
/SDA: J5.4, J6.4, J7.3, U1.J3-6 (IO21)
GND: H1.1, H2.1, J1.2, J1.MP (MountPin), J2.1, J4.4, J4.16, J5.2, J6.2, J7.1, J8.6, Q1.1 (E), U1.J2-14 (GND1), U1.J3-1 (GND3), U1.J3-7 (GND2)
unnamed: BZ1.2 (-), Q1.3 (C), R2.2
unnamed: J2.2, J3.2, U1.J2-19 (EXT_5V)
unnamed: Q1.2 (B), R1.1
unnamed: R1.2, U1.J2-15 (IO13)

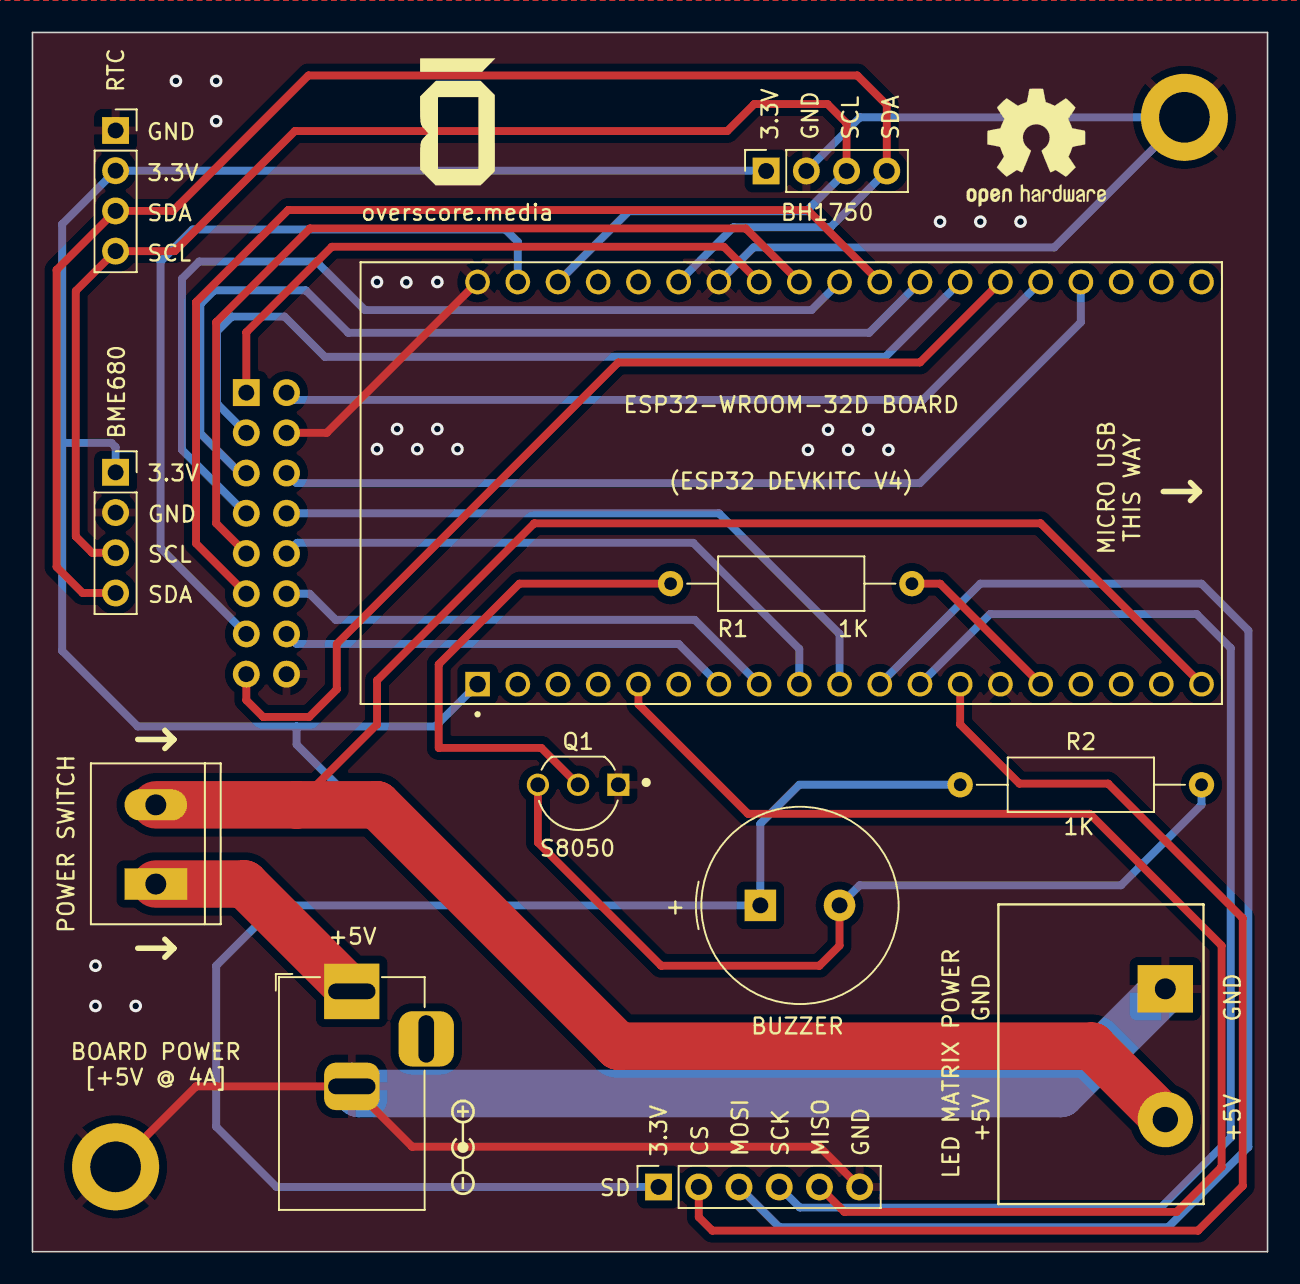
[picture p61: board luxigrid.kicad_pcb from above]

Board: 2 copper layers, 78.0 x 77.0 mm, 15 parts (1 on the bottom side), 27 nets.

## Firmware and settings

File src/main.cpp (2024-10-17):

#include "Arduino.h"
#include "../lib/luxigrid.h"

extern void setup();
extern void loop();

#ifdef GIF_PLAYER
#include "../apps/gif-player.hpp"
#endif

#ifdef MORPHING_CLOCK
#include "../apps/morphing-clock.hpp"
#endif

#ifdef PONG_CLOCK
#include "../apps/pong-clock.hpp"
#endif

#ifdef STOCK_TICKER
#include "../apps/stock-ticker.hpp"
#endif

#ifdef WEATHER_STATION
#include "../apps/weather-station.hpp"
#endif

//
// Animations
//
#ifdef ATTRACT
#include "../apps/animations/attract.hpp"
#endif

#ifdef BUBBLES
#include "../apps/animations/bubbles.hpp"
#endif

#ifdef CODE_RAIN
#include "../apps/animations/code-rain.hpp"
#endif

#ifdef DVD_LOGO
#include "../apps/animations/dvd-logo.hpp"
#endif

#ifdef ELECTRIC_MANDALA
#include "../apps/animations/electric-mandala.hpp"
#endif

#ifdef FLOCK
#include "../apps/animations/flock.hpp"
#endif

#ifdef FLOW_FIELD
#include "../apps/animations/flow-field.hpp"
#endif

#ifdef HUE_VALUE_SPECTRUM
#include "../apps/animations/hue-value-spectrum.hpp"
#endif

#ifdef INCREMENTAL_DRIFT
#include "../apps/animations/incremental-drift.hpp"
#endif

#ifdef JULIA_SET
#include "../apps/animations/julia-set.hpp"
#endif

#ifdef LIFE
#include "../apps/animations/life.hpp"
#endif

#ifdef MAZE
#include "../apps/animations/maze.hpp"
#endif

#ifdef MUNCH
#include "../apps/animations/munch.hpp"
#endif

#ifdef PENDULUM_WAVE
#include "../apps/animations/pendulum-wave.hpp"
#endif

#ifdef PERIODIC_TABLE
#include "../apps/animations/periodic-table.hpp"
#endif

#ifdef PLASMA
#include "../apps/animations/plasma.hpp"
#endif

#ifdef PONG_WARS
#include "../apps/animations/pong-wars.hpp"
#endif

#ifdef SIMPLEX_NOISE
#include "../apps/animations/simplex-noise.hpp"
#endif

#ifdef SNAKE_GAME
#include "../apps/animations/snake-game.hpp"
#endif

#ifdef SNAKES
#include "../apps/animations/snakes.hpp"
#endif

#ifdef SWIRL
#include "../apps/animations/swirl.hpp"
#endif

#ifdef TV_TEST_PATTERN
#include "../apps/animations/tv-test-pattern.hpp"
#endif

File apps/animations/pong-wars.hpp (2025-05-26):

/* _    _  _ _  _ _ ____ ____ _ ___
 * |    |  |  \/  | | __ |__/ | |  \
 * |___ |__| _/\_ | |__] |  \ | |__/
 * =================================
 * Luxigrid - Pong Wars Animation
 * Copyright (c) 2024 OverScore Media - MIT License
 *
 * Adapted from: https://github.com/anoken/pong-wars-forM5Stack
 * Copyright (c) 2024 anoken2017 - MIT License
 * ==================================
 *
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
 * THE SOFTWARE IS PROVIDED "AS IS", WITHOUT WARRANTY OF ANY KIND, EXPRESS OR
 * IMPLIED, INCLUDING BUT NOT LIMITED TO THE WARRANTIES OF MERCHANTABILITY, FITNESS
 * FOR A PARTICULAR PURPOSE AND NONINFRINGEMENT. IN NO EVENT SHALL THE AUTHORS OR
 * COPYRIGHT HOLDERS BE LIABLE FOR ANY CLAIM, DAMAGES OR OTHER LIABILITY, WHETHER
 * IN AN ACTION OF CONTRACT, TORT OR OTHERWISE, ARISING FROM, OUT OF OR IN
 * CONNECTION WITH THE SOFTWARE OR THE USE OR OTHER DEALINGS IN THE SOFTWARE.
 */

#ifndef PONG_WARS_GUARD
#define PONG_WARS_GUARD

#include "Arduino.h"
#include "../../lib/luxigrid.h"

struct Colour {
	uint8_t r;
	uint8_t g;
	uint8_t b;
};

struct PongWarsConfig {
	Colour colour1;
	Colour colour2;
};

PongWarsConfig pongWarsConfig;
const char *pongWarsConfigFilename = "/config/apps/pong_wars.json";

bool importPongWarsConfig(const JsonDocument &jsonDoc) {
	if (!jsonDoc["colour1"].is<JsonObjectConst>() || !jsonDoc["colour2"].is<JsonObjectConst>()) {
		return false;
	}

	JsonObjectConst colour1 = jsonDoc["colour1"].as<JsonObjectConst>();
	JsonObjectConst colour2 = jsonDoc["colour2"].as<JsonObjectConst>();

	// Return false if the colour1 format is invalid
	if (!colour1["r"].is<uint8_t>() || !colour1["g"].is<uint8_t>() || !colour1["b"].is<uint8_t>()) {
		return false;
	}

	// Return false if the colour2 format is invalid
	if (!colour2["r"].is<uint8_t>() || !colour2["g"].is<uint8_t>() || !colour2["b"].is<uint8_t>()) {
		return false;
	}

	// Otherwise, load the config into pongWarsConfig
	pongWarsConfig.colour1.r = colour1["r"].as<uint8_t>();
	pongWarsConfig.colour1.g = colour1["g"].as<uint8_t>();
	pongWarsConfig.colour1.b = colour1["b"].as<uint8_t>();

	pongWarsConfig.colour2.r = colour2["r"].as<uint8_t>();
	pongWarsConfig.colour2.g = colour2["g"].as<uint8_t>();
	pongWarsConfig.colour2.b = colour2["b"].as<uint8_t>();

	return true;
}

void loadPongWarsConfig() {
	File pongWarsConfigFile = SD.open(pongWarsConfigFilename, FILE_READ);

	DeserializationError deserializationError;
	JsonDocument jsonDoc;

	// Set default pong wars config, and create new config file if none exists
	if (!pongWarsConfigFile) {
		JsonObject colour1 = jsonDoc["colour1"].to<JsonObject>();
		colour1["r"] = 237;
		colour1["g"] = 223;
		colour1["b"] = 214;

		JsonObject colour2 = jsonDoc["colour2"].to<JsonObject>();
		colour2["r"] = 200;
		colour2["g"] = 100;
		colour2["b"] = 81;

		jsonDoc.shrinkToFit();

		// Create the "config" directory if it doesn't exist
		if (!SD.exists("/config")) {
			bool configDir = SD.mkdir("/config");

			if (!configDir) {
				Serial.println("ERROR 2206 - Failed to create directory for config files");

				// ERROR 2206 - Failed to create directory for config files
				crashWithErrorCode(2206);
			}
		}

		// Create the "apps" subdirectory if it doesn't exist
		if (!SD.exists("/config/apps")) {
			bool appsDir = SD.mkdir("/config/apps");

			if (!appsDir) {
				Serial.println("ERROR 2206 - Failed to create directory for config files");

				// ERROR 2206 - Failed to create directory for config files
				crashWithErrorCode(2206);
			}
		}

		File newPongWarsConfigFile = SD.open(pongWarsConfigFilename, FILE_WRITE, true);

		if (!newPongWarsConfigFile) {
			Serial.println("ERROR 2201 - Failed to Create App-Specific Config File");

			// ERROR 2201 - Failed to Create App-Specific Config File
			crashWithErrorCode(2201);
		}

		if (serializeJsonPretty(jsonDoc, newPongWarsConfigFile) == 0) {
			Serial.println("ERROR 2202 - Failed to Write Defaults to App-Specific Config File");

			// ERROR: 2202 - Failed to Write Defaults to App-Specific Config File
			crashWithErrorCode(2202);
		}

		newPongWarsConfigFile.close();

		// Reboot the ESP32
		restart();
	} else {
		deserializationError = deserializeJson(jsonDoc, pongWarsConfigFile);

		if (!importPongWarsConfig(jsonDoc)) {
			Serial.println("ERROR 2203 - JSON App-Specific Config Present, but Validation Failed");

			// ERROR 2203 - JSON App-Specific Config Present, but Validation Failed
			crashWithErrorCode(2203);
		}
	}

	pongWarsConfigFile.close();
}

///////////////////
// RETRIEVE APP CONFIG
///////////////////
void retrieveAppConfig(JsonDocument &jsonDoc) {
	// Pong Wars Config
	JsonObject colour1 = jsonDoc["pong-wars"]["colour1"].to<JsonObject>();
	colour1["r"] = pongWarsConfig.colour1.r;
	colour1["g"] = pongWarsConfig.colour1.g;
	colour1["b"] = pongWarsConfig.colour1.b;
	JsonObject colour2 = jsonDoc["pong-wars"]["colour2"].to<JsonObject>();
	colour2["r"] = pongWarsConfig.colour2.r;
	colour2["g"] = pongWarsConfig.colour2.g;
	colour2["b"] = pongWarsConfig.colour2.b;
}

///////////////////
// VALIDATE APP CONFIG
///////////////////
void validateAppConfig(AsyncWebServerRequest *request, bool &shouldSaveConfig) {
	if (request->hasParam("colours", true)) {
		const AsyncWebParameter *colours = request->getParam("colours", true);

		JsonDocument jsonDoc;
		DeserializationError deserializationError = deserializeJson(jsonDoc, colours->value());

		if (deserializationError || !importPongWarsConfig(jsonDoc)) {
			request->send(400, "text/plain", "Pong Wars colour configuration is invalid");
			shouldRestart = true;
			return;
		}

		shouldSaveConfig = true;
	}
}

///////////////////
// SAVE APP CONFIG
///////////////////
void saveAppConfig() {
	File pongWarsConfigFile = SD.open(pongWarsConfigFilename, FILE_WRITE, true);

	JsonDocument jsonDoc;
	JsonObject colour1 = jsonDoc["colour1"].to<JsonObject>();
	colour1["r"] = pongWarsConfig.colour1.r;
	colour1["g"] = pongWarsConfig.colour1.g;
	colour1["b"] = pongWarsConfig.colour1.b;
	JsonObject colour2 = jsonDoc["colour2"].to<JsonObject>();
	colour2["r"] = pongWarsConfig.colour2.r;
	colour2["g"] = pongWarsConfig.colour2.g;
	colour2["b"] = pongWarsConfig.colour2.b;

	if (serializeJsonPretty(jsonDoc, pongWarsConfigFile) == 0) {
		Serial.println("ERROR 2205 - Failed to Save Changes to App-Specific Config File");

		// ERROR 2205 - Failed to Save Changes to App-Specific Config File
		crashWithErrorCode(2205);
	}
}

// 画像の幅と高さ、四角形のサイズ、四角形の数を定義 [Define square size and the number of squares to fill the screen with]
int SQUARE_SIZE = 2;  // 16
int numSquaresX = MATRIX_WIDTH / SQUARE_SIZE + 1;
int numSquaresY = MATRIX_HEIGHT / SQUARE_SIZE + 1;

// 四角形の位置情報を格納する2次元ベクトル [A 2D vector that stores the position information of a square]
std::vector<std::vector<int>> squares;

// ボールの情報を格納する構造体のベクトル [A vector of structs that store ball information]
struct _pong {
	double x;
	double y;
	double dx;
	double dy;
	int class_num;
};

double vel = SQUARE_SIZE / 2;

std::vector<_pong> pong;

uint16_t color1;
uint16_t color2;
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
